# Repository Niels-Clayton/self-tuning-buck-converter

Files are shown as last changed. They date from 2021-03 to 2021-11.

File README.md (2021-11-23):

# [Self Tuning Buck Converter](https://niels-clayton.github.io/self-tuning-buck-converter/)

### Documents

Documentation and project planing

### Literature

Latex bibliography `.bib` file, organised using [JabRef](http://www.jabref.org), with copies of all cited documents.

### Reports

Latex projects for all written reports.

- Project Proposal
- Preliminary Report
- Final Project Report

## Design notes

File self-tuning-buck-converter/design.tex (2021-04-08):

\documentclass[a4paper,11pt]{article}
\usepackage[left=2.5cm, right=2.5cm, top=1.5cm, bottom=1.5cm]{geometry}
\usepackage{graphicx}
\usepackage{amssymb}
\usepackage{amsmath}
\usepackage{xcolor}
\usepackage{hyperref}

\hypersetup{ %color attributes of citation, link, etc.
    colorlinks=true,
    linkcolor=blue,
    filecolor=gray,
    urlcolor=blue,
    citecolor=blue,
}

\setlength{\parindent}{0pt}

%'codify' text for snippets
\usepackage{xcolor}
\definecolor{codegray}{gray}{1}
\newcommand{\code}[1]{\colorbox{codegray}{\texttt{#1}}}

\graphicspath{ {./images/} }
  
\title{\LARGE{\textbf{Self Tuning Buck Converter Design}}}
\author{}
\date{}

\begin{document}

\maketitle
\vspace{-20pt}
\hrule

\section{PWM Generation}

Based on our evaluation criteria, the generated PWM signal will need to be capable of outputting frequencies between 1kHz and 100kHz. \\

This PWM signal will also need to facilitate the required output voltage accuracy of $\pm5\%$ of the target output voltage, for target voltages between 3V and 10V. The relationship between the input and output voltage of a buck converter is given by $V_{out} = D \times V_{in}$. It should be noted that the output voltage is a function of the PWM duty cycle, therefore we must design the duty cycle such that it can provide the required output voltage accuracy. The workings of this design can be seen in the following.\\

Assuming $V_{min} = 3V$ 
\begin{align*}
    V_{error} &= 5\% \mathrm{\; of \;} V_{min} = 0.15V\\
    D_{steps} &\ge \frac{V_{in}}{V_{error}} \ge 80
\end{align*}

By designing the PWM duty cycle based on the buck converter minimum output voltage, we design the system to achieve the smallest tolerable error. This design guarantees that the required output voltage accuracy will always be achievable by our system if our PWM duty cycle has more than 80 steps. 

\subsection{Analogue}

\subsection{Microcontroller}

\subsection{FPGA}

\section{Current Ripple Sensing}

\end{document}

% \begin{center}
%     \fbox{\includegraphics[width=0.9\textwidth]{image_name.png}}
% \end{center}

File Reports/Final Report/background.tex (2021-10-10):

\chapter{Background}\label{C:background}

A literature research was performed to inform design decision made in this project, and to evaluate any existing research. This chapter will discuss buck converter design factors and topologies, as well as the various different methods of PWM generation, current sensing, and control implementation. In performing this literature research, we searched Google Scholar, Engineering Village, and Te Waharoa to find designs that utilised variable frequency PWM. 

These searches returned no research relevant to the designs of this project, with the only related work focusing on the electromagnetic noise reduction using randomised frequency modulation \cite{Roman2001,Familiant2016}. Because of this, research was instead performed to inform the design of the buck converter and the generation of PWM signals.

\section{Pulse Width Modulated Signal Generation}\label{S:PWM_back}

Pulse width modulation (PWM) is a digital signal generation technique shown in \Cref{F:PWM}, in which the Period $T$ of the signal is held constant, while the ratio of its logic high period $T_{on}$ to logic low period $T_{off}$ is modulated. This ratio of high period to the low period is referred to as the duty cycle of the PWM signal and is often expressed as a percentage, this can be seen in \Cref{F:Duty}.\\

PWM signals are used in a wide variety of applications for both digital and analogue electronics. PWM is often used to generate analogue signals from digital components by varying the average voltage of the digital PWM signal over time \cite{Thoren}. PWM is also used to control the switching elements contained within switch mode power supplies using this same principle, as discussed in \Cref{S:buck_back}. With regard to this project, we will be looking to generate a PWM signal that can be modulated in both duty cycle and frequency.

\begin{figure}[H]
      \centering
      \begin{subfigure}{0.45\textwidth}
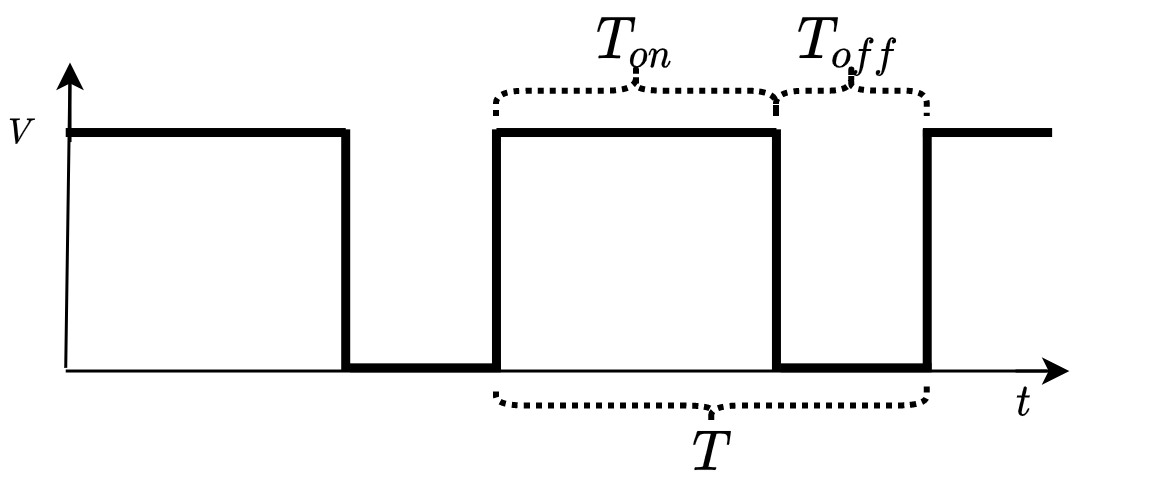
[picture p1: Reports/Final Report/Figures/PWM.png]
          
          \subcaption{Pulse width modulated signal}
          \label{F:PWM}
      \end{subfigure}
      \hspace{10pt}
      \begin{subfigure}{0.5\textwidth}
          
          \vspace{-6pt}
          \subcaption{Duty cycle calculation}
          \label{F:Duty}
      \end{subfigure}
      \caption{Pulse width modulated signal characteristics}
      \label{F:PWM_description}
  \end{figure}

\subsection{Analogue PWM Signal Generation} \label{S:analogue_PWM_back}

Designing a PWM signal generator using analogue components has three distinct stages required to generate the signal. These stages can be seen in \Cref{F:analogue_PWM}, and include clock generation, triangle wave generation, and signal comparator stages \cite{Caldwell2013}.\\ 

The clock generation stage generates a square wave clock signal at a set frequency. This is usually done using a quartz crystal oscillator, or another form of resonating oscillator circuit. The triangle wave generating state must take the clock signal from the previous stage, and produce a triangle wave of the same frequency. This stage is most often done using a standard op-amp integrating circuit with unity gain at the resonating frequency of the clock source. The final signal comparator stage will convert this triangle wave into a PWM signal. Using a comparator, a reference voltage can be applied to the non-inverting input, and then the triangle wave can be applied to the inverting input. This will produce a pulse train with the same frequency as the clock source, where the period of $T_{on}$ and $T_{off}$ is set by the reference voltage. 

\begin{figure}[H]
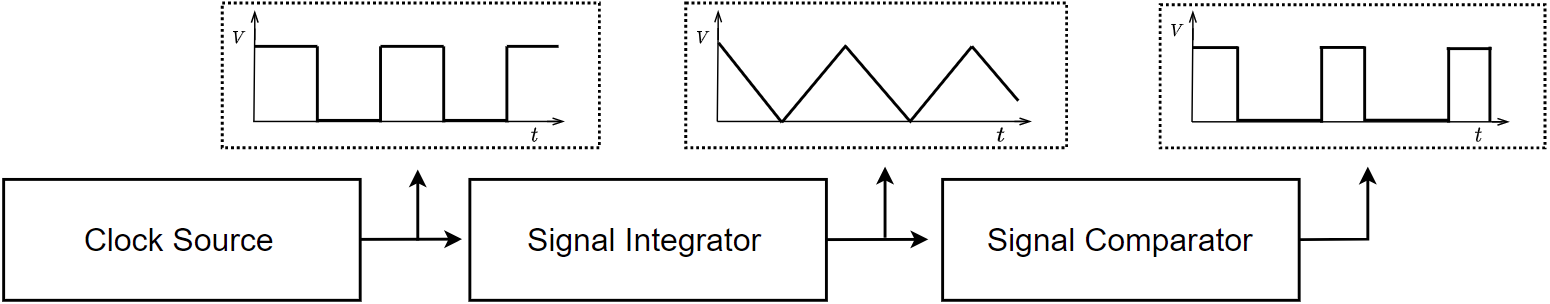
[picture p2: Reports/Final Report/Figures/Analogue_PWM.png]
	
	\caption{Stages of analogue PWM generation}
	\label{F:analogue_PWM}
\end{figure}

\subsection{Digital PWM Signal Generation}\label{S:digital_PWM_back}

Designing a PWM signal generator with digital components is less complex than the method described in \Cref{S:analogue_PWM_back}, and can be done using either a microcontroller or a Field Programmable Gate Array (FPGA). By using an internal timing register that is continually incrementing at a known period we can set a period for our PWM. It is possible to vary the period of the PWM by simply increasing or decreasing the timing registers clock. Next, by toggling a digital I/O when a compare variable is equal to the current value of the timer, we are able to generate a PWM signal with a variable duty cycle \cite{Colley2020}. 
This timing architecture can be simply implemented within an FPGA, but it can also commonly be found within the hardware of most microcontrollers. However, It should be noted that the range of achievable frequencies and duty cycle accuracy will be dependant on an individual microcontrollers clock speed and internal register sizes.

\section{Buck Converters}\label{S:buck_back}

The buck converters is a variant of a switch mode power supply that steps down a DC input voltage to a DC output voltage. They are commonly used in a wide variety of consumer and professional appliances such as laptops, phones, and chargers due to their high efficiency compared to other DC-to-DC step down converters such as linear regulators \cite{Mohan2012}.\\

The basic operational components of a buck converter can be seen below in \Cref{F:buck_func}. From this we see that a buck converter has three main elements, the input voltage source, two switching components, and an output filter across the load. In the case of \Cref{F:buck_func}, the first switching component is an actively controlled switch such as a MOSFET or transistor, and the second a passive switching diode. This configuration of an active and a passive switch is known as the non-synchronous buck converter topology, if the passive diode were to be replaced with a second active switch the topology would be considered synchronous. Although both topologies function under the same fundamental principles, the non-synchronous topology is easier to implement with the drawback of higher losses and therefore lower efficiency.\\

It can also be seen from \Cref{F:buck_func} that a buck converter has two operating states that are controlled through the activation of these switching components. By toggling these switching components at high speed though the use of PWM, we can control the current flowing through the inductor of the output filter. By controlling this current we are also able to directly control the current through, and voltage across the output load of the converter. Using this, buck converters will often have a feedback control system in their design to be able to actively control and regulate the output voltage during usage. This controller will vary the duty cycle of the the switching PWM signal, thereby varying the output voltage of the buck converter as shown in \Cref{E:V_out}.\\

\begin{figure}[H]
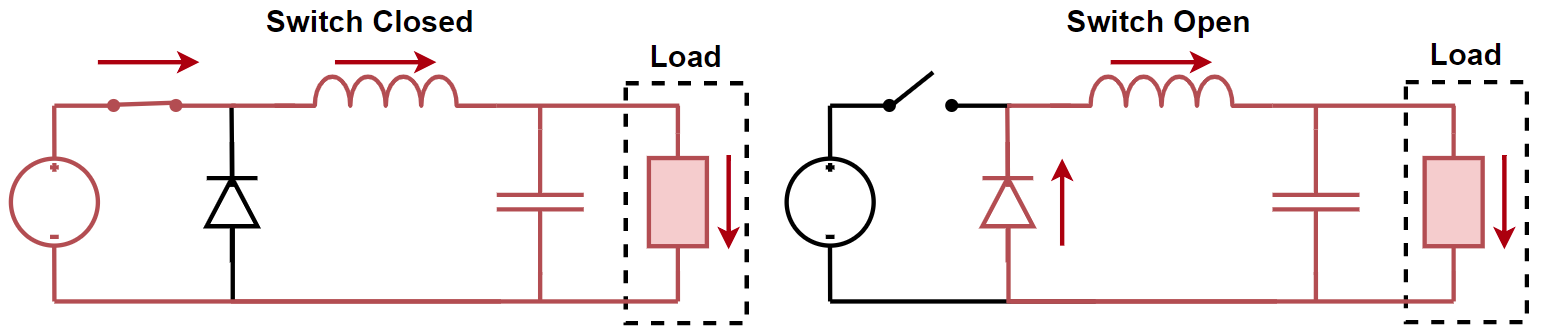
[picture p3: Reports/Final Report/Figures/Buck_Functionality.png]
	
	\caption{Operating states of a buck converter}
	\label{F:buck_func}
\end{figure}

\subsection{Buck Converter Design}\label{S:buck_design_back}

The design of a common buck converter has two primary considerations, the output voltage of the converter $V_0$, and the inductor current ripple of the converter $\Delta i_L$. These considerations can be specified by designing the buck converter using \Cref{E:V_out} \& \Cref{E:delta_i} \cite{Mohan2012_Design,Hauke2015}.\\ 

When designing a buck converter the first design specification that must be met is the output voltage. In \Cref{E:V_out} the output voltage can be directly related to the input voltage $V_{in}$ and the switching duty cycle $D$. Using this equation it is possible to directly set the output voltage of the buck converter by varying this duty cycle.

\begin{align}\label{E:V_out}
	V_o &= D \cdot V_{in}
\end{align}

Once the output voltage has been specified, the inductor current ripple can be calculated and specified with \Cref{E:delta_i}. This equation allows for the inductor current ripple to be directly related to the inductor size $L$, and the PWM switching frequency $f_s$. This allows the the specification of the inductor current ripple through the varying of these two values.

\begin{align}\label{E:delta_i}
   \Delta i_L &= \frac{ V_{o} \cdot \left( 1 - D \right) } {L \cdot f_s}
\end{align}

These two equations will be used to inform the designs and specifications of this project, and will be discussed in detail in \Cref{S:specs_design}.

\section{Current Sensing}\label{S:current_sense_back}

Current sensors are transducers that converter an input current to an easily measured output voltage that is proportional to the current through the sensor. Current sensors operate on one of two principles, Ohm's law, Faraday’s and Ampere’s law \cite{current_sensor_types}.  Ohm's law describes how when current flows through a resistive element a voltage drop will occur. Sensors operating under this principle will measure the voltage drop across a known resistance, and are referred too as direct sensors as they directly effect the circuit. Faraday’s and Ampere’s law describes how a changing electric flux will induce a changing magnetic field, and a changing magnetic field will induce a changing magnetic flux. Sensors operating under this principle will use the magnetic field induced by the current through the sensor to produce a voltage proportional to that current, and are referred to as indirect sensors as they make no direct contact with the circuit being sensed. 

\subsection{Current Sense Amplification}\label{S:current_shunt_back}

Current sense voltage amplification sensors are a form of direct sensor, working on the principle of Ohm's law $I=\frac{V}{R}$. By sensing the voltage dropped across a known value resistive element (Often called the current shunt), it is possible to calculate the current that is flowing through the element. This form of current sensing is easy to implement in theory, however it has the effect of altering the system being sensed by adding a resistive load, and thereby increasing the losses of the system. 

To mitigate the effects of this sensing on a circuit, a smaller resistive load can be used. However, this will also decrease the measurable voltage across the load, and therefore decrease the precision of a taken measurement. Because of this, shunt based current sensors are often paired with an operational amplifier of known gain. This combination allows for accurate amplification of the shunts voltage drop, increasing the precision of measurements, and allowing for drastically smaller shunt resistors. 

\subsection{Hall Effect Sensors}\label{S:hall_effect_back}

Hall effect sensors are a form of indirect sensor, working on the principles of Faraday’s and Ampere’s law as discussed above. They function by measuring the magnetic flux density, meaning that they are commonly used to sense the presence of a magnets or magnetic fields. However, since a current flowing though a wire will produce a magnetic flux, they can also be used to measure current flow.

Due to this operation, they are able to sense a current without contacting or altering the circuit. This means that they are commonly used in the measurement of high voltage or high current circuits, as they will remain completely isolated from the circuit being sensed. This provides large safety advantages, eliminates sensing power losses, and can often decrease the complexity of the sensing circuit. 

However, hall affect sensors do suffer from a lack of precision. Due to their operation, their measurements will constantly be offset by any ambient magnetic flux within the surrounding environment. This means that they are not commonly used for the sensing of small signal currents, as the noise floor of the Earth's own magnetic field can often be larger than the signal being sensed \cite{hall_effect_precision}. 

\newpage

\section{Control Systems}\label{S:control_back}

Control systems are integral to the operation of any system for which you wish to achieve a desired outcome. In their simplest, a control systems has the purpose of obtaining a desired output from a system, with a desired performance, when a given input is provided. \\

There are two main topologies of control system, open loop and closed loop. An open loop control system requires no feedback of the output, and therefore no sensing. Because of this, open loop controllers are often fast to implement within a system because of this. However, it should be noted that they possess no knowledge of the systems state and are therefore unable to correct for errors such as external disturbances. 

On the other hand, closed loop controllers require feedback from the current output of a system, and therefore will require sensing to be implemented. This feedback provides the ability to compensate for errors in the systems output, with the drawback of add complexity.\\

The performance of a specific control system is often discussed in terms of it's steady state settling time, and it's stead state error. The steady state settling time of a controller describes the time it takes for a controller to reach it's final value (`steady state') when provided with a given input. The slower the steady settling time of a controller, the slower it will react to a given input, and vice versa. The steady state error of a controller describes the error between the desired output and the final output of the system once it's steady state has been achieved.

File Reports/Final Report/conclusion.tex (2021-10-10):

\chapter{Conclusions}\label{C:conclusion}

The ultimate goal of this project was to develop a testing platform through which the effects of variable buck converter switching frequency on inductor current ripple could be observed and controlled. This goal was to be approached with an emphasis on its usability and expandability, providing a proof of concept for further development and research to be performed.\\

With these goals in mind the project was subdivided into three subsystems, each responsible for the operation of a key component of the final systems design. Each subsystem was individually designed, implemented, and evaluated throughout this report.

The first of these subsystem is PWM signal generation, responsible for providing a selectable switching frequency and duty cycle switching signal. This section facilitates buck converter operation, providing the ability to both vary output voltage, and inductor ripple independently. 

The second subsystem involves system state sensing, responsible for measuring the current values of various portions of the design. This section facilitates the feedback on current converter states, monitoring the output voltage, the supply voltage, and the inductor current ripple. 

The final subsystem provides the control, responsible for maintaining the selected buck converter output voltage and inductor current ripple. This subsystems interacts directly with the previous two, receiving system feedback from subsection 2, and providing output frequencies and duty cycles to subsystem 1.\\

This project was also subject to a list of requirements, provided in \Cref{S:goals}, which was then broken down into final system specifications in \Cref{S:specs_design}. The following list briefly outlines each requirement and it's final implementation within this project.\\

\begin{enumerate}
    \item \textbf{Operate with a 12V DC input supply voltage}

    Each subsystem was successfully designed to operate with a DC input supply between 8V and 16V. 

    \item \textbf{Provide a selectable DC output voltage between 3V and 10V}

    The implemented system was capable maintaining a selected DC output voltage between 1V and 10V, selectable to one decimal pace. 

    \item \textbf{Provide an output voltage precision of at least $\pm5\%$ of the targeted output voltage}

    The implemented system was capable maintaining an output steady state error of $\pm$0.78\%, across the entire output voltage range.

    \newpage
    \item \textbf{Provide a selectable inductor current ripple between 20\% and 50\% of the total output current}

    This requirement is pending implementation due to Covid-19 relates delays. Evaluation has been performed on each element of the requirements design, all of which successfully met the individual specifications.

    \item \textbf{Provide a variable converter switching frequency between 1kHz and 100kHz}

    The implemented system was capable of varying switching frequency between 1kHz, and 100kHz, with a maximum frequency error of 0.064\% of the target output.

    \item \textbf{Provide an inductor current ripple precision of at least $\pm5$\% of the target inductor current ripple }

    This requirement is pending implementation due to Covid-19 relates delays. Evaluation has been performed on each element of the requirements design, all of which successfully met the individual specifications.

    \item \textbf{Operate with variable load sizes between 10$\Omega$ and 20 $\Omega$}

    Each subsystem has been successfully designed to operate with variable load sizes between 10$\Omega$ and 20 $\Omega$.

\end{enumerate}

\section{Future Work}

Upon full assembly of this projects subsystems into the final designed system, this project lends it self to a wide variety of future research and study. 

With the projects motivation being based on the complexity and static nature of buck converter design, research into the characterisation of varying buck converter topologies can be performed. This could allow for distinctions between the design process of synchronous and asynchronous buck converters, exploring possible differences in switching frequency requirements between the two topologies. 

It would also be valuable to explore this systems response to non-resistive loads, looking to characterise the different switching requirements for both inductive and capacitive impedances.

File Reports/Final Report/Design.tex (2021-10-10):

\chapter{Design}\label{C:design}

The design processes outlined within this report will draw heavily on the background research discussed in \Cref{C:background}. These designs aim to effectively implement the outlined system requirements discussed by \Cref{S:goals} in a robust and repeatable manner.

%
% SECTION Defining & Justifying System Specifications
%

\section{System Specifications and Architecture}\label{S:specs_design}

\Cref{S:goals} outlines a list of specifications that this project must achieve. For each item in this list, design specifications can be derived to ensure that our designs are capable of meeting the outlined requirements. This list of specifications will also help to shape the architectural approach taken on this project.

\subsubsection*{Requirement 1: Operate with a 12V DC input supply voltage}

To meet this requirement, the buck converter must be designed to be 12V DC compatible. this will require all designed hardware, including additional digital and analog circuity to be capable of operating with this supply.

\subsubsection*{Requirement 2: Provide a selectable DC output voltage between 3V and 10V}

To meet this requirement, the designed buck converter must have the ability to change the duty cycle of it's PWM switching signal. This will allow for variation of the output voltage based on \Cref{E:V_out}.

\subsubsection*{Requirement 3: Provide an output voltage precision of at least $\pm5\%$ of the targeted output voltage}

To meet this requirement, the designed buck converter must have a control system to regulate the output voltage. To achieve a steady state error of less than $\pm5\%$, feedback should be implemented, requiring output voltage sensing. We can also specify that a minimum duty cycle resolution of 1.25\% will be required to achieve this. For the derivation of these values, refer to \Cref{A:specs}.

\subsubsection*{Requirement 4: Provide a selectable inductor current ripple between 20\% and 50\% of the total output current}

To meet this requirement, the designed buck converter must have the ability to change the frequency of it's PWM switching signal. This will allow for variation of the inductor peak to peak current ripple based on equation \Cref*{E:delta_i}. 

\subsubsection*{Requirement 5: Provide a variable converter switching frequency between 1kHz and 100kHz}

To meet this requirement, the PWM switching frequency must be selectable across the specified range. This, in tandem with requirement 4, allow for the specification of the inductor range for which these requirements can be met. For the derivation of these values, refer to \Cref{A:specs}.

\subsubsection*{Requirement 6: Provide  an  inductor  current  ripple  precision  of  at  least $\pm$5\%  of  the  target  inductor current ripple}

To meet this requirement, the designed buck converter must have a control system to regulate the inductor current ripple. To achieve a steady state error of $\pm$5\%, feedback should be implemented, requiring inductor current ripple sensing. We can also specify that a minimum frequency selection resolution of 200Hz, as well as a minimum current ripple measurement resolution of a resolution of 15mA will be required to achieve this. For the derivation of these values, refer to \Cref{A:specs}.  

\subsubsection*{Requirement 7: Operate with variable load sizes between $10\Omega$ and $20\Omega$}

To meet this requirement, all components of the buck converter must be designed to handle the maximum output current of 1A that will occur with a $10\Omega$ load at 10V. It will also be important that any current sensing is designed to operate within the range defined by these loads. Finally it is required that control systems are implemented to maintain requirements 3, \& 6 as the load varies. 

\subsection{System Architecture}\label{S:system_architecture}

Based on the specifications outlined in the above section, an architecture that outlines the system design has been developed. This architecture has been divided into three subsystems that must each be developed. This architecture system can be seen in \Cref{F:sys_overview}.\\

Subsystem one implements a PWM generator. From requirements 2, \& 5 it has been identified that a PWM generator capable of varying both the duty cycle and the frequency of it's output signal independently must be designed. This system can be seen in \Cref{F:sys_overview} outlined in green.\\

Subsystem two implements system state sensing. From requirement 3 \& 6 it has been identified that an output voltage sensor, and an inductor current ripple sensor must be designed. This system can be seen in \Cref{F:sys_overview} outlined in blue.\\

Subsystem three implements two control systems. From requirements 3, 4, 6, \& 7 it has been identified that control systems should be designed to ensure that the specified steady state errors of the output voltage and inductor current ripple are met. 

One control system will take the output load voltage measurement, and control the PWM duty cycle. The other control system will take the inductor current ripple, and control the PWM frequency. This system can be seen in \Cref{F:sys_overview} outlined in red.

\newpage

\begin{figure}[!h]
    
    \caption{System architecture design, with three internal subsystems}
    \label{F:sys_overview}
\end{figure}

% It has been specified that the final system design will be able to select for both the output load voltage, and the inductor current ripple of the buck converter. From this requirement we can identity that two separate control systems should be designed, one to regulate the output voltage of the converter, and one to regulate the inductor current ripple.

% Next we can identify that to control the output load voltage and the inductor current ripple, we must be able to actively effect their current state. Based on \Cref{E:V_out} we can see that by varying the duty cycle of the converters PWM signal, we are able to directly control the output voltage. Similarly, from \Cref{E:delta_i} we can see that by varying the converters PWM switching frequency we are able to directly control the inductor current ripple. From this we can specify that our designs of the PWM generation must be capable of varying both the duty cycle and the switching frequency of the output PWM signal independently and simultaneously. \\

% The outlined requirements also specify the level of precision that will be required from the output load voltage and the inductor current ripple. This allows us to specify the tolerable error for the system design, and calculate the minimum required system specifications. Based on the buck converter design equations from \Cref{S:buck_design_back}, The following specifications have been identified:

% \begin{itemize}
%     \item Maximum allowable duty cycle step size

%     \begin{align}
%         V_{error} &= V_{min} \cdot error = 0.15V\\
%         D_{step} &= \frac{V_{error}}{V_{in}} = 0.0125\\
%         N_{step} &= \frac{1}{D_{step}} = 80 \label{E:duty_step}
%     \end{align}

%     \item Maximum \& minimum inductor sizes

%     \begin{align}
%         L_{max}&=\frac{V_{max}\cdot\left(1-D_{max}\right)}{f_{min}\cdot I_{min}} = 27.7mH \label{E:L_max}\\ 
%         L_{min}&=\frac{\frac{V_{in}}{2}\cdot\left(1-0.5\right)}{f_{max}\cdot I_{min}} = 0.5mH \label{E:L_min}
%     \end{align}
    
%     \item Maximum allowable frequency step size

%     \begin{align}
%         f_{step}&=\frac{V_{max}\cdot\left(1-D_{max}\right)}{\left(I_{min}-I_{Error}\right)\cdot L_{max}}-f_{min} = 52Hz\\
%         N_{steps}&=\frac{\left(f_{max}-f_{min}\right)}{f_{step}} = 1881 \label{E:f_step}
%     \end{align}

% \end{itemize}

% The derivation of these values can be found in \Cref*{A:specs}.

% \subsubsection{TODO Refactor this to be a list of specifications}
% From these equations we can build a list of final specifications to inform the design of our PWM generator and buck converter. The PWM generator must provide a minimum voltage step size of $0.0125$V, for a resolution of 80 voltage steps between 3V and 10V. The PWM generator must also be able to provide a minimum frequency step size of $52$Hz, for a resolution of 1881 frequency steps between $1$kHz \& $100$kHz. Finally we can also specify that the buck converter must be capable of functioning with inductor values between $0.5$mH \& $27.7$mH. \\

% By designing the PWM generator and the buck converter to these specifications, we are able to guarantee that we can always achieve the requirements outlined in \Cref{C:intro}.\\

% \subsubsection{TODO Discuss the minimum and maximum sense current, along with the bandwidth requirement of the sensors}
% Design the system specifications around the current sensing and voltage sensing. What is the required bandwidth of the sensor? What is the required precision?\\

% \section{System Architecture \& Design}\label{S:system_design}

% To achieve the specifications that have been outlined in \Cref{S:specs_design}, it is important to design the system architecture around them. In \Cref{F:sys_overview} an overview of the system architecture can be seen, with three main design sections outlined. These sections each represent a significant segment of work that must be completed for the final artefact of this project to be achieved. \\

% The first section of work that must be completed is the design of the PWM generation, denoted 1 in \Cref{F:sys_overview}. This PWM generator will be used to control both the output voltage and the inductor current ripple, and as such must be able to modulate both the duty cycle and the frequency of the PWM to the precisions required. \\

% The second section of work is the design of the sensing elements required by the system, denoted 2 in \Cref{F:sys_overview}. These elements will be used to measure both the output voltage and the inductor current ripple, and therefore must be able to achieve the required precisions and sampling rates. \\

% Finally the third section of work is the design and implementation of the two control systems, denoted 3 in \Cref{F:sys_overview}. These control systems will be responsible for maintaining the desired output voltage and inductor current ripple of the buck converter. This system will therefore be responsible for facilitating the final functionality of the project, combining sections 1 \& 2. \\

%
% SECTION PWM Generation
%

\section{PWM Signal Generator}\label{S:pwm_gen_design}

In the design of the PWM generator, both the analogue and digital topologies discussed in \Cref{S:PWM_back} were considered, and designed for. Each of these designs presented pros and cons that would affect the overall design. This section will discuss these design choices, and finalise the design of the PWM signal generator.

A successful design will meet all of the requirements outlined by \Cref{S:specs_design}. Therefore the design must be capable of duty cycle variation with a resolution of 1.25\%, as specified by requirements 2 \& 3, as well as switching frequency variation between 1kHz \& 100kHz with a resolution of 200Hz, as specified by requirements 4, 5, \& 6. A successful design will also adhere to the ease of use and future expansion goal specified in \Cref{S:goals}.

\subsection{Analogue PWM Generator Design}\label{S:PWM_analogue_design}

It has been discussed in \Cref{S:analogue_PWM_back} that the design of an analogue PWM signal generator requires three distinct stages. These stages are signal clock generation, signal integration, and signal comparison, as shown in \Cref{F:analogue_PWM}.

Designs for these sections were implemented within the circuit simulation software LTSpice, see \Cref{A:PWM}. From these simulations it was identified that the signal integration stage of the design functions as a first order low pass filter, where integration occurs beyond the filter's cut-off frequency. This causes a 40dB attenuation of the output signal across the required frequency range. Due to this, the design was identified to be unsuitable for this system as it was unable to meet requirements 4, 5, \& 6. 

% The clock generation stage will be responsible for setting the frequency of the final PWM signal. This specifies that the clock source have a variable frequency output range between $1kHz$ and $100kHz$, with a minimum step size of $52Hz$. Research was done on a variety of clock sources, looking at voltage-controlled oscillators (VCO's), signal generator IC's, and even the basic 555 timer. From this VCO's were identified to operate at much higher frequencies than those used in this project. It was also identified that signal generator IC's often require selections of passive components to operate effectively, increasing their complexity. For this reason the variable frequency 555 timer circuit was selected, as it provided the required specifications.\\

% The next section designed was the signal integrator stage. This stage consisted of a basic op-amp integrator circuit, with a design requirement that it be able to integrate the clock signal across the frequency range required. This circuit was designed and implemented in an LTSpice simulation to evaluate it's performance, and can be seen in \Cref*{A:analogue_PWM}. From this simulation it was noted that the integrator's frequency response was similar to that of a first order low pass filter, and greatly attenuated the integrated signal. For this reason it was decided that analogue PWM generation would not be implemented in this system, as it presented many issues.

\subsection{Digital PWM Generator Design}\label{S:PWM_digital_design}

As discussed in \Cref{S:digital_PWM_back}, The design of a digital PWM signal generator is based on the toggling an output when a timer reaches a given comparison value. This design can be achieved with either discrete logic designed within an FPGA, or using existing hardware within a microcontroller. 

\subsubsection*{FPGA PWM Generator}

The operation of an FPGA allows for the design and implementation of customised logic. Because of this, designs utilising FPGA's would easily be able to meet the specified requirements for the PWM signal generator.

However, the designs integration into the system architecture described in \Cref{F:sys_overview} must also be considered. A PWM generator implemented in an FPGA will be required to either implement or provide an interface with the control subsystem, as well as the state sensing subsystem. These interfaces must also be designed, greatly increasing the complexity of this specific subsystem. Due to this added complexity, it was identified that this design was not suitable for an initial proof of concept, and would not adhere to the ease of use goal. 

\subsubsection*{Microcontroller PWM Generator}

The selection of the microcontroller is highly dependant on the clock frequency and internal PWM peripheral architecture. Since these vary greatly between different processors, a selection of microcontroller data-sheets were reviewed to identify their specifications. 

The microcontrollers reviewed were selected based on the ease of use of their available development environments. This included AVR, STM8, Espressif, and teensy based microcontroller development boards. 

From this review it was identified that the ESP32 microcontroller \cite{ESP32Manual} would be best suited to this project. This microcontroller is capable of outputting a maximum PWM frequency of 125$kHz$ when a duty cycle resolution of 9 bits is selected. This will provide a total of 512 selectable duty cycle values, for a resolution of 0.2\%, while providing a selectable duty cycle frequency between 1Hz, \& 125kHz. 

Based on these specifications, it is clear that this design meets the duty cycle requirements of 2 \& 3, as well as the frequency requirements of 4, 5, \& 6, and is therefore suitable.

%
% SECTION Inductor Current Ripple Sensing Design
%

\section{System State Sensing}\label{S:sensing_design}

The design of the state sensing system will include the output voltage sensor and the inductor current ripple sensor. These sensors will be responsible for providing the feedback data for the control systems, illustrated in \Cref{F:sys_overview}. To provide a peak to peak inductor current measurement as a percentage of the output current, both the average and peak inductor currents must be measured. Based on these measurements, the inductor current ripple percentage can be calculated.

A successful design will meet all the requirements outlined by \Cref{S:specs_design}. Therefore the output voltage sensor must be capable of measuring voltages between 3V \& 10V with a resolution of 150mV, as specified by requirements 2 \& 3. It is also required that the average inductor current, and the peak inductor current ripple measurements achieve a resolution of 15mA, for frequencies between 1kHz \& 100kHz, as specified by requirement 4, 5, 6, \& 7.

\subsection{Output Voltage Sensing}\label{S:v_sense_design}

The output voltage of the buck converter will be a DC voltage between 3V \& 10V. As there are no high frequency components to this signal, there are no bandwidth requirements on it's sampling. Due to this the internal analog to digital converter (ADC) of the ESP32 microcontroller will be used for sampling. This 12 bit ADC can measure an input voltage range of 0V to 3V \cite{ESP32Manual}, therefore the output voltage will have to be measured through a voltage divider. This divider will provide an output ratio of $\frac{10}{3.33}$, allowing for maximal use of the ADC's input range. This will provide a theoretical measurement resolution of 2.5mV. 

Based on these specifications, this design is capable of measuring output voltages between 3V and 10V, with a resolution of 2.5mV, meeting the outlines requirements 2 \& 3.

\subsection{Current Sensor Selection}\label{S:current_sense_selection}

To maintain design simplicity, both the average inductor current, and the peak inductor current ripple will be measured from the same sensor. Due to this, a hall effect based current sensor is not suitable for this application. It was discussed in \Cref{S:hall_effect_back} that they lack precision due to a high noise floor, and would be unable to meet requirements 4 \& 6. 

Because of this, a current shunt based sensor with a defined gain and selectable shunt resistance has been designed, specifically the LT1999-50 with a 60m$\Omega$ shunt. This current sense amplifier has a specified gain of 50V/V, a typical gain error of 0.2\%, and a bandwidth of 2MHz \cite{LT1999_datasheet}. This sensing solution will provide a voltage output between 0.67V \& 3.72V across the total current sensing range, with a resolution defined by the gain error of 50$\mu$A at the output. Refer \Cref{A:specs} for the calculation of these values. The datasheet also specifies that there will be no attenuation of the output gain for frequencies of 100kHz or below. 

Based on these specifications, this design is capable of measuring the full current input range specified in requirements 4 \& 7, while surpassing the resolution and frequency specifications of requirements 5, \& 6.

\subsection{Average Inductor Current Sensing}\label{S:avg_current_design}

\begin{wrapfigure}{r}{0.3\textwidth}
    \vspace{-33pt}
    \begin{center}
      
    \end{center}
    \caption{Average current 10Hz cut-off low pass filter}
    \vspace{-22pt}
\end{wrapfigure}

To obtain the average inductor current ripple, the output of the previously designed current sense amplifier can be low pass filtered. By designing a first order passive low pass filter with a cut-off frequency of 10Hz, we can be sure to attenuate any selectable switching frequency by at least 40dB. This will provide a simple to measure DC voltage between 0.45V and 3V. This can be measured using the internal ADC of the ESP32 providing a theoretical resolution of 700$\mu$V, or 244$\mu$A. Refer \Cref{A:specs} for the calculation of these values.

\subsection{Peak Inductor Current Sensing}\label{S:peak_current_design}

Based on the bandwidth requirement of 1kHz to 100kHz, it was identified that sampling the output signal of the current sensors to identify the peaks would be impractical. To achieve this a sampling rate of at least twice the highest frequency component would be specified by the Nyquist theorem, and a recommended minimum of one decade above is considered common practice, requiring a sampling rate of 1Mhz. 

Due to this, designs were undertaken to simplify the sampling requirements. The following designs will take direct input from the current sensor, and aim to output a DC voltage that is representative of the input current peak values. 

% discuss why it is that peak sensing is important, and how two designs have been created to achieve this task. The precision rectifier is my own design and not based on any existing designs, the sample and hold based sensor is based on designs from these resources \cite{peak_detector_designs, LTC6244_peak_detector}

\subsubsection*{Precision Rectifier Peak Voltage Detection}\label{S:current_sense_precision_rectifier_design}

This design is based around the operation of a signal precision rectifier, and the knowledge that the inductor current ripple will be symmetrical and triangular in shape \cite{Mohan2012_Design}. Due to this symmetry, we know that the average inductor ripple current over a period will be zero, shown in \Cref*{F:rectification} (a). After rectification of the signal, the the ripple peak to peak value will halve, the frequency will double, and the new signal average will be half the new ripple peak to peak, shown in \Cref*{F:rectification} (b). 

\begin{figure}[H]
    
    \centering
    \begin{subfigure}{0.49\textwidth}
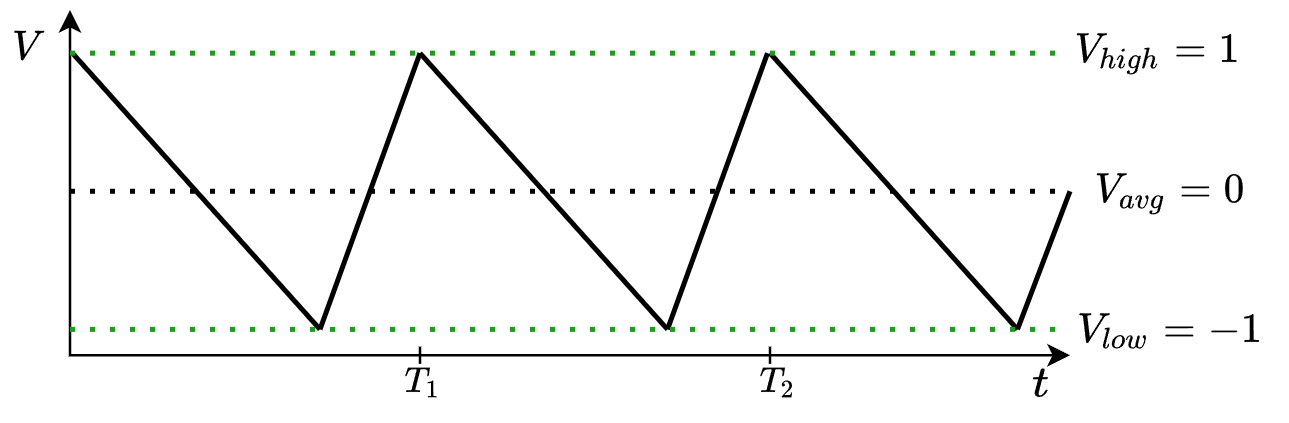
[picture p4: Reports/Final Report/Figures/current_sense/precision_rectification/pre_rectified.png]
        
        \subcaption{Pre-rectification current sense output of 1V pk to pk, average voltage of 0V}
    \end{subfigure}
    \begin{subfigure}{0.49\textwidth}
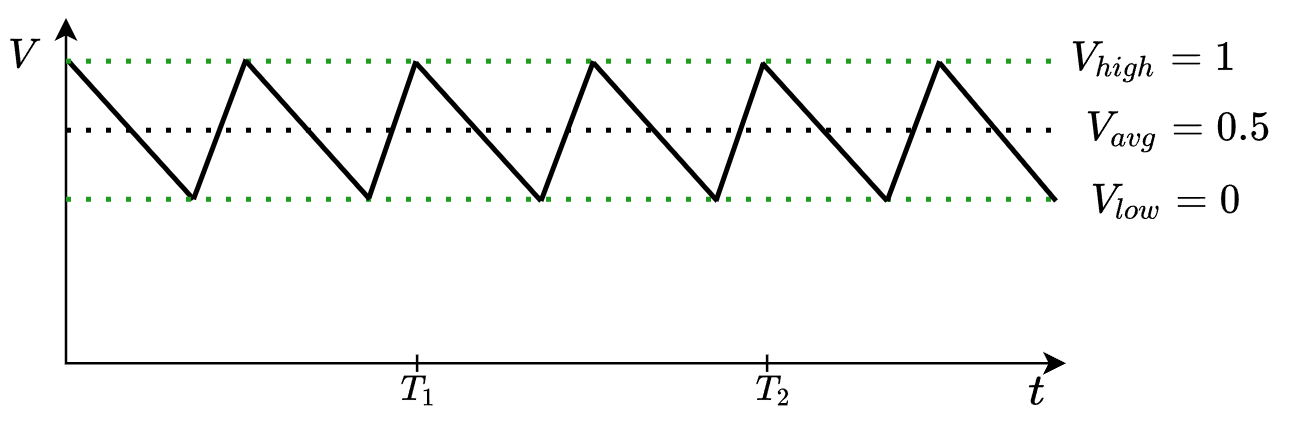
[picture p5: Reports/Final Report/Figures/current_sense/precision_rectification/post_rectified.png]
        
        \subcaption{Post-rectification current sense output of 1V pk to pk, average voltage of 0.5V}
    \end{subfigure}
    \caption{Average voltage output of a symmetrical signal, before and after rectification}
    \label{F:rectification}
\end{figure}

From here, we can obtain the signal average by applying a passive a low pass filter with a cut off of 10Hz to the output, producing a sampleable DC voltage. To obtain the full original signal peak to peak value, this signal can then amplified with a gain of 4. The full design can be seen in \Cref{F:precision_rectifier_circuit}.

\begin{figure}[!h]
    \centering
    
    \caption{Precision rectifier peak detector designed circuit schematic}
    \label{F:precision_rectifier_circuit}
\end{figure}

% Discuss the operation, and simulations of the Precision Rectifier Peak Voltage Detection. 

\subsubsection*{Sample and Hold Peak Voltage Detection}\label{S:current_sense_sample_and_hold_design}

This design is based on existing voltage peak detection designs \cite{peak_detector_designs,LTC6244_peak_detector}. The design operates on a similar principle to a sample and hold unit, charging a signal capturing capacitor through a diode such that it will not discharge. In order to remove the voltage drop across the charging diode, it is placed within the forward path of an operational amplifier buffer. The output voltage is then buffered again to allow for sampling. The full design can be seen in \Cref{F:sample_and_hold_circuit}.

\begin{figure}[!h]
    \centering
    
    \caption{Sample \& hold peak detector designed circuit schematic}
    \label{F:sample_and_hold_circuit}
\end{figure}

Both of the discussed designs have been simulated in LTSpice, and have had their operation confirmed, refer to \Cref{A:peak_detector} for output plots. From this it was identified that both designs would be able to meet the resolution specification of 15mA, and bandwidth specification of 1kHz to 100kHz outlined in requirement 4, 5, 6, \& 7.

It should also be noted however that the design of the precision rectifier based peak detector is much more complex than that of the sample and hold peak detector. Because of this, it was decided that the sample and hold based peak detector would be most suitable for this project, as it meets all required specifications, and best adheres to the ease of use goal.

% Discuss the operation, and simulations of the Sample and Hold Peak Voltage Detection. Then discuss that due to it's simpler design, it's implementation will be far easier, the possible issue it may have will be easier to diagnose, and it's cost will be much lower. then specify that this was the final design selected for this section.

\subsection*{Current sensing digitisation}\label{S:current_sense_ADC_design}

Due to the operation of the design discussed in \Cref{S:current_sense_sample_and_hold_design}, the output DC voltage will be imposed on a DC refrence voltage. To eliminate this DC bias from the output, a dedicated external ADC with a differential input can be employed. This will allow for the removal of the bias at the digitisation of the signal. The selected ADC is the MAX11644, which provides a 12bit resolution, an internal reference of 4.096V, and the required differential input. 
Based on these specifications, this design is capable of measuring input voltages between 0V and 4.096V, with a resolution of 8mV. This will give a current sensing resolution of 2.6mA, meeting the specifications of requirement 6.

% Discuss the selection of the ADC for measuring the peak ripple and mean ripple currents. Talk about the minimum required ADC precision, and bandwidth requirements. Discuss hoe this AC provides a differential output. 

%
% SECTION Control System Design
%

\section{Control System}\label{S:control_design}

When designing the output voltage and inductor current ripple control systems, a successful design will meet all the requirements outlined by \Cref{S:specs_design}. From this we can identify that both controllers must provide a steady state error that is less $\pm$5\% of the targeted value, as specified in requirements 3 \& 6. 

\subsection{Output Load Voltage Controller}\label{S:output_control_design}

To achieve the desired output voltage steady state error, a feedback controller with an integrating term should be used. To provide this, the design will implement a proportional, integral, \& differential (PID) controller. This controller will be provided with the buck converter output voltage as an input, this will then be converted to the theoretical PWM duty cycle required to produce that output based on \Cref{E:V_out}. This will then be used to calculate the controller error and output the new PWM duty cycle.

To design this, a mathematical model of a buck converter \cite{Patil2015} was found and simulated in Matlab. This model was then discretised such that it could be implemented on a microcontroller, and a PID controller was then designed with the `\lstinline{PIDTune()}' function. A step response simulation of this model can be found in \Cref{A:control}. 

Due to the control topology used in this design, this design will be able to provide an output voltage steady state error of 23mV based on the discrete voltage step size from the PWM generator. This will provide a worst case error of $\pm$0.78\%, meeting the $\pm$5\% specified in requirement 3.

\newpage
\subsection{Inductor Current Ripple Controller}\label{S:ripple_control_design}

To achieve the desired inductor current ripple steady state error, the same topology implemented for the output voltage controller will be implemented. This PID controller will take the system's inductor current ripple as a percentage of the average current, and then calculate the error between it and the target value. From here it will then output the new PWM switching frequency. 

Due to the control topology used in this design, this design will be able to provide an inductor current ripple steady state error of less than $\pm$5\%, as specified in requirement 6.

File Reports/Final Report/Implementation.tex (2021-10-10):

\chapter{Implementation}\label{C:implementation}

\section{PWM Signal Generation}\label{S:pwm_gen_impl}

The PWM signal generator subsystem was designed around the Espressif ESP32 microcontroller. For ease of development around this microcontroller, a pre-built breadboard compatible development board was purchased for the implementation. \\

Using this development board, a PWM hardware driver was developed to facilitate the implementation of this subsystems core functionality as specified in \Cref{S:specs_design}. This driver implements three core functions, `\lstinline{PWM_setup()}' to initialise the PWM hardware, `\lstinline{PWM_set_duty()}' to select a new duty cycle, and `\lstinline{PWM_set_frequency}' to select a new frequency. The full driver implementation, refer to \Cref{A:pwm_code}.\\

After the software implementation had been completed, it was identified that the 3.3V digital output of the microcontroller would be incapable of driving the buck converters switching power MOSFET. To resolve this, the IR2125 high side N-channel gate driver IC was purchased to drive the MOSFET from the PWM generators output signal. This final circuit was then implemented and it's functionality was tested on a breadboard. Please see \Cref{A:pcb_and_schematic} for the designed schematic, and \Cref{A:breadboard} for the implemented breadboard circuit.

% Discuss how the micro will be unable to directly drive the gate of the switching MOSFET, as it's $V_{GS_{on}}$ will be too large. Because of this a gate driver will need to be selected. The driver will need to be driven using the 3.3V logic from the ESP32, and will need timings fast enough to function correctly at 100kHz. I can also discuss how during the lock-down I was unable to purchase a gate driver, and so I built a bootstrapping circuit from components I located around the house. 

\section{System State Sensing}\label{S:current_sense_impl}

% Due to time restraints caused by COVID-19 related delays, the implementation and evaluation of each design within the state sensing subsystem discussed in \Cref{S:sensing_design} was impractical. Therefore, designs that \todo{lacked prior formal testing and evaluation in the form of datasheets} were prioritised for implementation. 

\subsection{Output Voltage Sensing}\label{S:v_sense_impl}

The output voltage sensing design discussed in \Cref{S:v_sense_design} was implemented on a prototyping breadboard. Refer to \Cref{A:pcb_and_schematic} for the designed schematic, and \Cref{A:breadboard} for the implemented breadboard circuit.

Using the ESP32 development board, an ADC hardware driver was developed to facilitate the measurement of the sensor output. This driver implements the core functionality of the ADC though two functions, `\lstinline{init_adc()}' to assign the input IO and measurement resolution, and `\lstinline{read_adc()}' to take an ADC measurement. Using these two functions this driver then also facilitates the computation of a rolling average with the `\lstinline{rolling_average()}' function, and voltage conversion with the `\lstinline{adc_conversion()}' function. The full driver implementation can be found in \Cref{A:adc_code}.\\

When initially implementing the ADC conversion function, it was assumed that that the output conversion of the ADC was linear. Once this had been implemented, it was observed that there were large inaccuracies in the voltage conversion. 

From this it was identified that the internal ADC  was non-linear, and would require calibration before meeting the required specifications. To achieve this, ADC measurements were taken for a selection of known input voltages ranging from 100mV to 3V in 500mV steps. These ADC measurements were then plotted against their respective input voltages using Matlab, and a forth order polynomial was fit to the data, shown in \Cref{F:adc_calibration}. This polynomial was then used for the conversion of the raw ADC reading to a voltage, greatly improving the ADC's accuracy.

\begin{figure}[!h]
    \centering
    
    \caption{ESP32 internal ADC calibration data with forth order polynomial fit}
    \label{F:adc_calibration}
\end{figure}

\subsection{Inductor Current Sensing}

\subsubsection*{Average Inductor Current Sensing}

The average inductor current sensing design discussed in \Cref{S:avg_current_design} was implemented on a prototyping breadboard. Refer to \Cref{F:final_peak_detector} for the designed schematic, and \Cref{A:breadboard} for the implemented breadboard circuit.

This design also utilises the ESP32 internal ADC, which was previously implemented in \Cref{S:v_sense_impl}. Therefore no further implementation was required for the functionality of this design.  

\subsubsection*{Peak Inductor Current Sensing}\label{S:peak_current_implementation}

The peak inductor current sensing design discussed in \Cref{S:peak_current_design} was initially implemented on a prototyping breadboard, using an LT084CN operational amplifier (op amp) provided by the lab technicians. 

On implementation it was observed that the functional principles of the design held true, as the design maintained a DC output voltage that was dependant in the input peak to peak ripple. However, it was observed that the accuracy of the design was much lower than expected when compared to the design simulations. The operation of this original design \todo{can be seen in} \Cref{A:peak_detector}.\\

It was identified that the limiting factor within the design was the bandwidth and slew-rate of the input stage op amp seen in \Cref{F:sample_and_hold_circuit}. This op amp is responsible for charging the sampling capacitor and negating the forward bias diode drop, and therefore it's bandwidth and slew-rate will dictate the bandwidth of the design.  

Based on this, the input op amp was replaced with the OPA2830, as it provided a greatly improved bandwidth of 230MHz and a slew rate of 500V/$\mu$s. The original design was also altered to place a potentiometer in series with the sampling capacitor, as well as adding a high impedance resistor in parallel with this capacitor. This allows for the final designs performance to be tuned through the potentiometer, and any overshoot to be quickly dissipated by the parallel discharge resistor. This final design of the schematic can be seen in \Cref{F:final_peak_detector}, and the implemented breadboard circuit can be found in \Cref{A:breadboard}.

\begin{figure}[!h]
    \centering
    
    \caption{Finalised peak detector schematic, with updated op amp selection and performance improvements}
    \label{F:final_peak_detector}
\end{figure}

\section{Control System}\label{S:control_impl}

The control system design discussed in \Cref{S:control_design} has been implemented in the form of a generic PID based control system library. This control system implementation provides a structure in which all of the controller variables and states are stored. This simplifies the initialisation of the controller, as the proportional, integral, derivative, and time period constants can all be specified at the structure initialisation. This implementation also allows for the creation and management of multiple controllers simultaneously, meeting requirements 2 \& 4. 

This control library also provides more advanced safety features for the system, including selectable minimum and maximum output limits, and selectable integrator windup limits.\\

This library implements two core functions which provide the full functionality of a digital PID control loop. `\lstinline{PID_init()}' initialises and sets up the controller, and `\lstinline{PID_update()}' calculates the new output of the controller. The full driver implementation can be found in \Cref{A:pid_code}.

\section{Full system implementation}

\subsubsection*{Software implementation}

The full system software implementation is built upon the ESP-IDF framework, and utilises a FreeRTOS to provide tasks and scheduling. 

The ESP-IDF Framework was chosen over other supported frameworks due to it's increased control of the ESP32 available hardware peripherals, which was required for the designs system to meet it's specified requirements from \Cref{F:sys_overview}. 

The use of the ESP-IDF framework also facilitated the use of FreeRTOS, providing access to a task scheduler that would greatly decrease the structural complexity of this system. This scheduler allows each subsystem within the design to operate from within a task, independent of all others. therefore, this implementation reduces the complexity of further developments within this project, without limiting the functionality of the microcontroller platform. The full system software implementation can be found in \Cref{A:main_code}.

\subsubsection*{Hardware implementation}

To facilitate the ease of use of the fully designed system, a printed circuit board (PCB) was designed and implemented using the KiCAD software platform. This PCB implements all finalised designed elements discussed in \Cref{C:design}, and provides multiple footprints for the buck converter output filter to allow for expedited testing and varying filters. For the full system schematic, refer to \Cref{A:pcb_and_schematic}.

\begin{figure}[!h]
    \centering
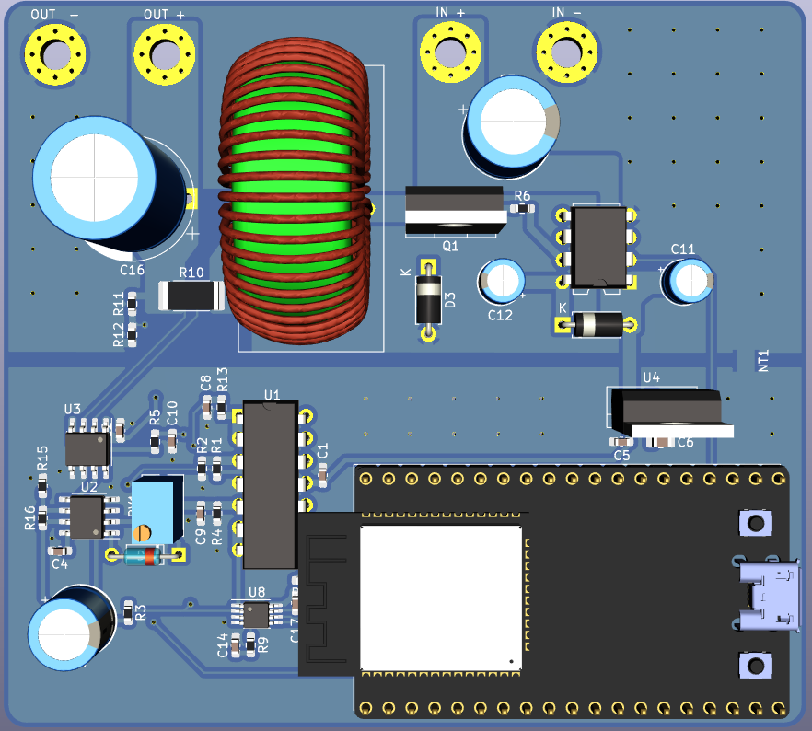
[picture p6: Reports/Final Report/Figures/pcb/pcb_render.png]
    
    \caption{Full system printed circuit board implementation}
    \label{F:implemented_pcb}
\end{figure}

% Discuss how the code implements each of the hardware sections designed. Then also discuss how the full system has been implemented on a PCB 
% Discuss the ESP-IDF HAL (Hardware Abstraction Layer), and how it provides greater control of the system resources than the more commonly used Arduino platform. 
% \\
% Then discuss how the system operates within the freeRTOS real time operating system, what allows for easy multitasking between the different time sensitive control loops that will have to be run on the micro.  
% \\
% Finally discuss the simple to use API that was implemented, which aims to abstract away the HAL layer. This API is implemented using collection of single header libraries written in the 'C' programming language, with each implementing only the core functionality of the hardware they are interacting with. This makes the software platform robust and simple to move to different embedded platforms, with such a move only requiring the re-implementation of the core functions of each library.

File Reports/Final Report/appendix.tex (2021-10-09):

\appendix

\include{acknowledge}

\include{appendix/system_specifications}

\include{appendix/pwm_figures_and_tables}

\include{appendix/peak_detector_figures_and_tables}

\include{appendix/control_figures.tex}

\include{appendix/schematic_and_pcb}

\include{appendix/breadboard_implementation}

\include{appendix/source_code}

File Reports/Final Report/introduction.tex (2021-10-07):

\chapter{Introduction}\label{C:intro}

Historically power distribution has been primarily in the form of AC (Alternating current). This is credited to the fact that AC power is simple to produce, and made it easy to step up and down the voltages efficiently with transformers \cite{Earley2013}. However, with the invention of solid-state electronics such as the metal–oxide–semiconductor field-effect transistor or MOSFET for short, it has become possible to efficiently step up and step down direct current (DC) voltages. This has been achieved by the invention of the switch-mode power supply, which has facilitated the continued reduction of size and increase in efficiency of electronics \cite{Bocock}.

Today, switch-mode power supplies can be found in a wide variety of consumer and professional electronics, with some examples being laptops, phones, and any form of DC charger. Their widespread usage when compared to other DC-DC converters such as linear regulators can be attributed to their far greater efficiency. One such switch-mode power supply is the buck converter, which will step down a DC input voltage to a lower DC output voltage.

\section{Project Motivation}

Although buck converters are a widespread technology, they are not without their limitations and drawbacks. The current buck converter design process requires that a specific output filter be designed around the switching frequency of the converter, and the desired inductor ripple current. This filter design process will often result in the converter requiring discrete passive components that are non-standard and hard to source. This will usually result in the designer having to make compromises in their design for either the cost or the performance of the converter.

Another drawback of this design process is the static nature of both the filter and the switching components once they have been selected. This results in the buck converters desired inductor current ripple only being achieved at a very specific designed output voltage or load. This means that with current buck converter designs varying the desired output voltage or varying the output load will cause the inductor current ripple to vary. This is an issue, as very few loads are static and will not change during their operation. 

\section{Project Goals}\label{S:goals}

The goal of this project is to develop a testing platform through which the effects of variable buck converter switching frequency on inductor current ripple can be observed and controlled. The aim of this is to eliminate the need to design the output stage of the buck converter by implementing a control system to maintain a specified inductor current ripple, and output voltage.\\

To achieve this goal, a proof of concept buck converter will be designed to operate as the testing platform. This converter will require a variable frequency pulse width modulated (PWM) signal generator, and inductor current ripple sensing. This will allow for direct manipulation and control of inductor current ripple. The converter will also need to implement the full functionality of existing buck converter designs, including controlled output voltage regulation.

It is also important to note that as this project aims to produce a testing platform to be used as a proof of concept, there will be continued work undertaken after the projects conclusion. Because of this, it is important that the design and implementation undertaken in this project considers the ease of use and future expansion of the project.\\

The following list of specifications outlines the requirements the designed test platform will meet:

\begin{enumerate}
    \item Operate with a 12V DC input supply voltage
    \item Provide a selectable DC output voltage between 3V and 10V
    \item Provide an output voltage precision of at least $\pm5\%$ of the targeted output voltage
    \item Provide a selectable inductor current ripple between 20\% and 50\% of the total output current
    \item Provide a variable converter switching frequency between 1$k$Hz and 100$k$Hz
    \item Provide an inductor current ripple precision of at least $\pm5$\% of the target inductor current ripple 
    \item Operate with variable load sizes between 10$\Omega$ and 20 $\Omega$
\end{enumerate}

% This project aims to eliminate the need to design the output stage of a buck converter. By implementing a control system that varies the switching frequency of the converter, we will be able to directly manipulate the inductor current ripple. This project aims to produce a proof of concept buck converter that is capable of operating at 12V, with an output range of 3-10V and precision of $\pm5\%$. The converter will also be able vary its switching frequency between 1$kHz$ and 100$kHz$, allowing for selection of inductor current ripple between 20\% and 50\% with precision of $\pm5\%$. All of this must be implemented while maintaining the standard functionality of the converter.

% \subsubsection{TODO Expand on the project goals, possibly convert the previous section into a bulleted list of project goals and requirements.}

% This will be referenced in the implementation and design sections many times, so it needs to clearly outline what we are looking to achieve in this project.

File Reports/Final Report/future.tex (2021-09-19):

\chapter{Future Plan}\label{C:future} 

This final chapter will outline the work that is yet to be completed for this project, and how we plan complete it. It will also discuss how we plan to evaluate this system once this future work has been completed, outlining the changes to the evaluation that have come about since the project proposal. Finally this chapter will then present the project timeline for the remaining work and evaluation, breaking down this work into discrete blocks of time. 

\section{Work to be Completed}\label{S:work_remaining}

As discussed in \Cref{S:system_design}, there are 3 main segments of work in this project. The first segment of work was the PWM generator, which has been outlined in \Cref{S:pwm_gen_design} and has already been completed. The next two section were the specification and selection of the required sensing elements, and then the implementation of the control system that will make this project functional.\\

To complete the specification and selection of the sensing elements, a large amount of background research will need to be completed. This research will include the identifying of various ways that the inductor current ripple can be measured, as well as defining the required specifications of the sensors based on the system requirements. Once this research has been completed and components have been selected, it will be important to evaluate the functionality of the components, to verify that they do meet the required specifications. Finally once the sensing elements have been selected and tested, the creation of a printed circuit board (PCB) to hold the PWM generator, sensing elements, and buck converter will be completed. This PCB will be the final physical artefact that is created from this project. \\

Once this physical artefact has been generated, the only section left to be completed is the projects control system. This control system will be responsible for regulating both the inductor ripple current and the buck converter output voltage. To be able to successfully implement this section of the project I will again need to perform a section of background research. This research will inform the design and implementation of this controller within the microcontroller, helping to select the controller architecture and structure. Once the controller design has been specified, it will need to be implemented in software on the microcontroller, allowing for time to test the implementation. 

\section{System Evaluation}

    The evaluation of this system has not changed substantially since the project proposal, and is still based upon meeting the following selection of specifications. 
    
    However, the evaluation of the system will now be conducted using a range of load resistances, evaluating its performance with 10$\Omega$, 15$\Omega$, and 20$\Omega$ output loads, using a constant supply voltage of 12V DC.

\begin{itemize}
	\item The buck converter will be able to take input voltages up to 12V DC
	
	\item The buck converter must maintain the basic functionality outlined in \cref{E:V_out}

	\item The buck converter will have an output voltage range between 3V and 10V DC
	
	\item The output voltage accuracy will be within $\pm 5\%$ of the target output voltage

	\item The user will be able to define the inductor ripple between 20\% and 50\%
	
	\item The inductor ripple accuracy will be within $\pm 5\%$ of the defined inductor ripple
	
	\item The buck converter will have a switching frequency range of 1k$Hz$ to 100k$Hz$

	\item The control system will have no steady state error

\end{itemize}

Since all of these evaluation metrics are highly qualitative, the evaluation of the final artefact will consist of a series of tests that will look to confirm the systems ability to achieve each of theses requirements.  

\section{Project Timeline}

The Gantt chart in \Cref{F:gantt} directly relates the remaining work set out in \Cref{S:work_remaining} to the time remaining for the project. For both the sensing element design and the control system, we believe that a large amount of background research will need to be completed before work is able to commence. This background research will inform and help reduce the time require to effectively design these sections. we plan to have all of the implementation and evaluation of the system completed before the end of the mid trimester break, as this will allow for a large amount of report writing time.

\begin{figure}[H]
    
    \caption{Proposed project timeline}
    \label{F:gantt}
\end{figure}

\section*{Feedback}\label{S:feedback} 

At this stage in the project I have a very clear idea as to what I am planning to, and how I am planning to get there. I would also greatly appreciate all feedback that can be provided on this report, so that I can implement the changes in my final report. I would greatly appreciate it if It would be possible to organise an in person meeting with my markers to discuss this report and project.

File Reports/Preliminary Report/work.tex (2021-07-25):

\chapter{Work Completed}\label{C:work}

This chapter will discuss the work that has been completed so far on this project. It will begin by discussing the projects requirements', using them to design and justify the final specifications of the system. Once the specifications are outlined, the architecture and design of the final system will be discussed. Finally the design and current implementation of the PWM signal generator will be specified.  

\section{Defining \& Justifying System Specifications}\label{S:specs}

Based on the system requirements that have been outlined in \Cref{C:intro}, a set of system specifications can be created to inform the design. Current work on this project has been towards the implementation of the PWM signal generator, and as such all specifications outlined will pertain to this work.

The final system is required to be able to select both the output voltage and inductor current ripple of the buck converter. From this requirement we specify that our PWM generator must vary both the duty cycle and the switching frequency of the buck converter, based on \Cref{E:V_out} \& \Cref{E:delta_i}. The requirements also specify the level of precision that will be required for these selections, allowing us to specify the tolerable error. Using these same equations, the minimum duty cycle step size in \Cref{E:duty_step}, the inductor minimum and maximum values in \Cref{E:L_min} \& \Cref{E:L_max}, and the frequency step size in \Cref{E:f_step} have all been derived. For the derivation of these values see \Cref*{A:specs}.\\

Duty cycle step calculation:
\begin{align}
    V_{error} &= V_{min} \cdot error = 0.15V\\
    D_{step} &= \frac{V_{error}}{V_{in}} = 0.0125\\
    N_{step} &= \frac{1}{D_{step}} = 80 \label{E:duty_step}
\end{align}

Inductor Sizing Calculations:
\begin{align}
    L_{max}&=\frac{V_{max}\cdot\left(1-D_{max}\right)}{f_{min}\cdot I_{min}} = 27.7mH \label{E:L_max}\\ 
    L_{min}&=\frac{\frac{V_{in}}{2}\cdot\left(1-0.5\right)}{f_{max}\cdot I_{min}} = 0.5mH \label{E:L_min}
\end{align}

Frequency step calculation:
\begin{align}
    f_{step}&=\frac{V_{max}\cdot\left(1-D_{max}\right)}{\left(I_{min}-I_{Error}\right)\cdot L_{max}}-f_{min} = 52Hz\\
    N_{steps}&=\frac{\left(f_{max}-f_{min}\right)}{f_{step}} = 1881 \label{E:f_step}
\end{align}

From these equations we can build a list of final specifications to inform the design of our PWM generator and buck converter. The PWM generator must provide a minimum voltage step size of $0.0125V$, for a resolution of 80 voltage steps between 3V and 10V. The PWM generator must also be able to provide a minimum frequency step size of $52Hz$, for a resolution of 1881 frequency steps between $1KHz$ \& $100kHz$. Finally we can also specify that the buck converter must be capable of functioning with inductor values between $0.5mH$ \& $27.7mH$. \\

By designing the PWM generator and the buck converter to these specifications, we are able to guarantee that we can always achieve the requirements outlined in \Cref{C:intro}.

\section{System Architecture \& Design}\label{S:system}

To achieve the specifications that have been outlined in \Cref{S:specs}, it is important to design the system architecture around them. In \Cref{F:sys_overview} an overview of the system architecture can be seen, with three main design sections outlined. These sections each represent a significant segment of work that must be completed for the final artefact of this project to be achieved. \\

The first section of work that must be completed is the design of the PWM generation, denoted 1 in \Cref{F:sys_overview}. This PWM generator will be used to control both the output voltage and the inductor current ripple, and as such must be able to modulate both the duty cycle and the frequency of the PWM to the precisions required. \\

The second section of work is the design of the sensing elements required by the system, denoted 2 in \Cref{F:sys_overview}. These elements will be used to measure both the output voltage and the inductor current ripple, and therefor must be able to achieve the required precisions and sampling rates. \\

Finally the third section of work is the design and implementation of the two control systems, denoted 3 in \Cref{F:sys_overview}. These control systems will be responsible for maintaining the desired output voltage and inductor current ripple of the buck converter. This system will therefor be responsible for facilitating the final functionality of the project, combining sections 1 \& 2. \\

\begin{figure}[!h]
    
    \caption{High level system overview}
    \vspace{-20pt}
    \label{F:sys_overview}
\end{figure}

\section{PWM Generation Design}\label{S:pwm_gen}

In the design of the PWM generator, both the analogue and digital designs discussed in \Cref{S:PWM} were considered, designed, and tested for. Each of these designs presented pros and cons that would affects the overall design of the system architecture. This section will discuss these designs and finalise the design of the PWM generator for this system. 

\subsection{Analogue PWM Generator Design}\label{S:analogue_design}

As discussed in \Cref{S:analogue_PWM}, the design of the analogue PWM signal generator requires three stages, each of which will have its own design requirements based on the specifications outlined in \Cref{S:specs}. \\

The clock generation stage will be responsible for setting the frequency of the final PWM signal. This specifies that the clock source have a variable frequency output range between $1kHz$ and $100kHz$, with a minimum step size of $52Hz$. Research was done on a variety of clock sources, looking at voltage-controlled oscillators (VCO's), signal generator IC's, and even the basic 555 timer. From this VCO's were identified to operate at much higher frequencies than those used in this project. It was also identified that signal generator IC's often require selections of passive components to operate effectively, increasing their complexity. For this reason the variable frequency 555 timer circuit was selected, as it provided the required specifications.\\

The next section designed was the signal integrator stage. This stage consisted of a basic op-amp integrator circuit, with a design requirement that it be able to integrate the clock signal across the frequency range required. This circuit was designed and implemented in an LTSpice simulation to evaluate it's performance, and can be seen in \Cref*{A:analogue_PWM}. From this simulation it was noted that the integrator's frequency response was similar to that of a first order low pass filter, and greatly attenuated the integrated signal. For this reason it was decided that analogue PWM generation would not be implemented in this system, as it presented many issues.

\subsection{Digital PWM Generator Design}\label{S:digital_design}

As discussed in \Cref{S:digital_PWM}, The design of the digital PWM generator is far simpler than that of the analogue, and can be implemented in a wide variety of methods. In this project microcontrollers and FPGA's have been considered.

Based solely on the capabilities of the platform, the PWM generator would be best designed and implemented on an FPGA as it would allow for superior speed and precision. However FGPA design brings a lot of difficulties, primarily in the prototyping and testing stages. Because of this, due to the limited time from of this project, we have decided to implement this PWM design using a microcontroller.

The selection of the microcontroller is highly dependant on the clock frequency and design of the PWM peripherals, as it must be capable of achieving the specifications outlined in \Cref{S:specs}. A large selection of microcontroller datasheets were reviewed to identify their specifications, including AVR, STM8, Espressif, and teensy based microcontrollers. From this review it was decided that the ESP32 microcontroller would be best suited to this project \cite{ESP32Manual}. This microcontroller is capable of outputting a maximum PWM frequency 125$kHz$ with a duty cycle resolution of 9 bits (512 voltage steps). From here a short C program was written to test the PWM functionality of the ESP32, and it was confirmed that it met the required specifications. The source code and images of this PWM signal can be found in \Cref{A:digital_PWM}.

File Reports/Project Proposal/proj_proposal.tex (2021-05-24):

%% $RCSfile: proj_proposal.tex,v $
%% $Revision: 1.3 $
%% $Date: 2016/06/10 03:44:08 $
%% $Author: kevin $

\documentclass[11pt, a4paper, oneside]{report}

\usepackage{float} % lets you have non-floating floats
\usepackage{url} % for typesetting URLs
\usepackage{wrapfig}
\usepackage[image,ecs]{vuwproject}

\renewcommand{\thesection}{\arabic{section}}
\setlength{\parindent}{0pt}
\setlength{\parskip}{\baselineskip}

%  We don't want figures to float so we define
%
\newfloat{fig}{thp}{lof}[chapter]
\floatname{fig}{Figure}
\graphicspath{ {./Figures/} }

\title{Self Tuning Buck Converter}
\author{Niels Daniel Clayton}
\supervisor{Daniel Burmester, Ramesh Rayudu}
\date{}
\otherdegree{Honours of Electronic and Computer System Engineering}

\begin{document}

% Make the page numbering Roman, until after the contents, etc.
\frontmatter

%%%%%%%%%%%%%%%%%%%%%%%%%%%%%%%%%%%%%%%%%%%%%%%%%%%%%%%

\begin{abstract}

	Switch-mode power supplies are commonly used in a wide variety of consumer and professional appliances to transform DC voltages with high efficiency. One such converter is the buck converter. The design of the buck converter requires specific components to design the output filter. These components be difficult to purchase or accurately manufacture. This project will implement a control system to actively control the switching frequency and eliminate the need design the output filter.

\end{abstract}

%%%%%%%%%%%%%%%%%%%%%%%%%%%%%%%%%%%%%%%%%%%%%%%%%%%%%%%

\maketitle

\tableofcontents

% we want a list of the figures we defined
%\listof{fig}{Figures}

%%%%%%%%%%%%%%%%%%%%%%%%%%%%%%%%%%%%%%%%%%%%%%%%%%%%%%%

\mainmatter

%%%%%%%%%%%%%%%%%%%%%%%%%%%%%%%%%%%%%%%%%%%%%%%%%%%%%%%

\section{Introduction}

\subsection{Switch Mode Power Supplies}

Switch-mode power supplies convert a DC input voltage to another DC output voltage. They are commonly used in a wide variety of consumer and professional appliances such as laptops and chargers due to their high efficiency compared to other DC-to-DC converters.

The step-down switch mode power supply also known as a buck converter, is a common DC-to-DC power converter that steps down an input voltage to the desired output efficiently. Currently, the design of these converters for specific applications requires a specifically designed output filter, designed around the switching speed of the converter. This filter will smooth the converter output voltage and maintain the inductor current ripple at the designed values. However this design process is not always applicable, if the specified components for the filter are not available there can be lead times, cost implications and delays.

\begin{figure}[h!]
	\begin{center}
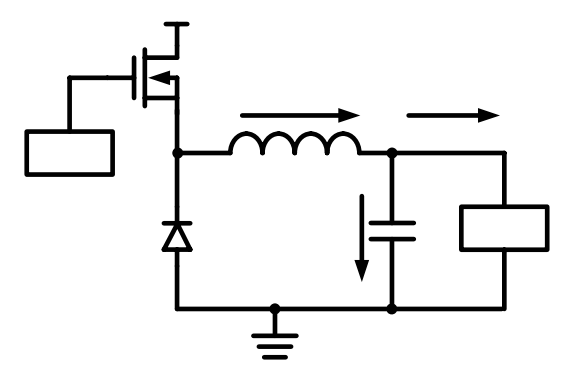
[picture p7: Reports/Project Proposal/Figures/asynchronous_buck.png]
		
		\caption{Asynchronous buck converter topology \cite{BuckTopology}}
		\label{asynchronous_buck}
	\end{center}
\end{figure}

This project aims to remove the need for designing the output stage of the buck converter. Using a control system, the switching frequency and duty cycle of the converter can be modulated to meet a selected inductor ripple, while maintaining a selected output voltage. This project will focus on the design and implementation of this control system on a basic asynchronous buck converter.
\newpage

\section{The Problem}

The current buck converter design requires that a specific output filter be designed around the switching frequency of the converter, and the desired inductor ripple. This filter design process will often result in the designer requiring discrete passive components that are not easily available. This requirement for precise discrete components can greatly increase the cost of the converter, and can also cause delays in manufacturing due to the lead time of components.

Another side effect of this design process is that this desired inductor ripple will only be achieved at the designed output voltage or load. This means that in current buck converter designs, varying the output voltage, or output load will cause the inductor ripple to vary. This can lead to the buck converter no-longer meeting the required specifications, making it hard to design a converter for a complex load.

This project aims to eliminate the need to design the output stage of a buck converter. This will be achieved by implementing a control system to vary both the switching frequency and duty cycle, to achieve the desired inductor ripple and output voltage. This will allow the buck converter to actively adjust the switching frequency to match the currently designed output filter at all times.

\section{Proposed Solution}

The proposed solution to this problem will have 3 phases, the initial research and setup, the design, and the implementation phase. Each phase will have a selection of tasks that must be completed to be able to progress to the following phase. The following subsections will go into detail on the undertakings of each phase. For time estimations of each task please look at the Gantt chart in Figure \ref{fig:gantt}.

\subsection{Research and Set-up}

The first phase of this project is the research and setup. The major component of this phase is the creation of the literature review that will be the basis of this project. In this literature review, I will compare and contrast a wide range of methods available to produce a frequency variable PWM signal. This review will also be used to compare and contrast varying sensing methods for sampling the inductor ripple and the output voltage.

When the literature review is complete, I will select the methods of PWM generation and output sensing that are most suitable for this project. This will help me identify a range of components that I believe will be feasible for the design. These components will be purchased for used in the design phase.

Finally, once the components have been purchased I will design a selection of development PCB's that will allow for simplistic interfacing with the purchased components and the existing buck converter design. This will help expedite the design phase.

\subsection{Design}
\label{sec:design}

In the design phase of the project, I will test and evaluate all of the selected PWM generation methods, and sensing methods. This will involve a large amount of prototyping on breadboards, along with possibly embedded programming on microcontrollers, and FPGA (Field Programmable Gate Array) design. The method of evaluation of these designs will be decided upon in the literature review.

Once the evaluation of the designs is complete, I will make the final hardware selection. The components selected at this stage will be used to implement the closed-loop controller for the converter.

\subsection{Implementation}

Finally, in the implementation phase of the project, the finalised hardware design will be used to implement the closed-loop control system. This system will sample the inductor ripple and vary the switching speed and duty cycle of the buck converter to reach a requested ripple value. A Simulink simulation may be designed to help with the implementation and design of this controller.

As the controller is being implemented, I will also design a final PCB for the buck converter. This PCB will include the entire buck converter design, with female headers for easy filter inductor and capacitor swapping.

\begin{figure}[!h]
	\begin{center}
		
		\caption{Project Gantt Chart}
		\label{fig:gantt}
	\end{center}
\end{figure}

\newpage
\section{Project Evaluation}

The evaluation of this project will be based upon meeting the following selection of specifications. All evaluations of the design will be conducted using a 10$\Omega$ output load, with an input voltage of 12V DC.

\begin{itemize}
	\item The buck converter will be able to take input voltages up to 12V DC
	
	\item The buck converter maintains basic functionality of $V_{out} = D\times V_{in} - \mathrm{effeciency}$

	\item The buck converter will output voltages between 3V and 10V DC
	
	\item The output voltage accuracy will be within $\pm 5\%$ of the target output voltage

	\item The user will be able to define the inductor ripple between 20\% and 50\%, with increments of 5\%.
	
	\item The inductor ripple accuracy will be within $\pm 5\%$ of the defined inductor ripple
	
	\item The buck converter will have a switching frequency range of 1k$Hz$ to 100k$Hz$
\end{itemize}

\section{Safety and Resourcing}

\subsection{Safety Considerations}

Below in Table \ref{tab:hazzard} there is a safety hazard identification, prevention, and mitigation table.

\begin{table}[!h]
	\begin{tabular}{|l|l|l|}
		\hline
		\multicolumn{1}{|c|}{Potential Hazards} & \multicolumn{1}{c|}{Hazard Prevention} & \multicolumn{1}{c|}{Hazard Mitigation} \\ \hline
		\begin{tabular}[c]{@{}l@{}}Burns due to resistive\\ elements heating \\ during use.\end{tabular}               & \begin{tabular}[c]{@{}l@{}}Ensure that no more than 5W of \\ power is dissipated across the \\ load at any time.\end{tabular}              & \begin{tabular}[c]{@{}l@{}}Turn off equipment that is \\ overheating.\end{tabular}              \\ \hline
		\begin{tabular}[c]{@{}l@{}}Cuts due to misuse \\ of wire cutters\end{tabular}               & \begin{tabular}[c]{@{}l@{}}Ensure that there are no \\ distractions when operating \\ potentially hazardous equipment.\end{tabular}              & \begin{tabular}[c]{@{}l@{}}Bandage the cut, and fill out \\ an accident/incident report.\end{tabular}             \\ \hline
		\begin{tabular}[c]{@{}l@{}}Burns due to misuse \\ of soldering iron\end{tabular}              & \begin{tabular}[c]{@{}l@{}}Ensure that there are no \\ distractions when operating \\ potentially hazardous equipment. \\ Make sure to correctly store \\ the soldering iron after use.\end{tabular}             & \begin{tabular}[c]{@{}l@{}}Apply ice to the burn and fill out \\ an accident/incident report.\end{tabular}             \\ \hline
		Dangerous voltages                      & \begin{tabular}[c]{@{}l@{}}Ensure that the power supply \\ never outputs more than the \\ maximum of 50V.\end{tabular}             & Turn off that is not operating safely  \\ \hline
	\end{tabular}
	\caption{Hazard assessment }
	\label{tab:hazzard}
\end{table}

\newpage
\subsection{Required Equipment}
\label{sec:equipment}
The Following list of equipment is currently available without purchase, but will be required for this project:

\begin{itemize}
	\item Lab bench power supply
	\item Lab bench oscilloscope
	\item Lab bench signal generator
	\item lab bench multi-meter
	\item Prototyping breadboards
	\item Passive components (resistors, inductors, capacitors, MOSFETs)
\end{itemize}

\subsection{Budget}

Below in Table \ref{tab:budget} is the total estimated cost of the components I will need to purchase for this project.

\begin{table}[!h]
	\begin{tabular}{|l|l|l|}
		\hline
		\multicolumn{1}{|c|}{Component} & \multicolumn{1}{c|}{Description}                                          & Cost  \\ \hline
		PCB Manufacturing               & In house or external PCB manufacturing                                    & \$50  \\ \hline
		Assorted components             & Parts to be tested and evaluated as discussed in section \ref{sec:design} & \$200 \\ \hline
	\end{tabular}
	\caption{Budget }
	\label{tab:budget}
\end{table}

\subsection{Covid-19 Considerations}

Due to the effects of Covid-19 lock-downs, it is important to be prepared for the possible implication of going to the varying alert levels will have.

In the case of alert level 2, the university will still be open and operating with enforced social distancing and masks. This alert level will have little to no effect on the progress of this project, as the honours lab allows for social distancing.

In the case of alert level 3 \& 4, the university will close. This means that I will not be able to access the honours lab to get to my equipment. In the case of alert level 3 or 4, I will have to ask the technicians if I am able to bring home with me the equipment listed in section \ref{sec:equipment} to continue working from home. If this is not possible then I will work to make an accurate simulation of the Project within Simulink.

%%%%%%%%%%%%%%%%%%%%%%%%%%%%%%%%%%%%%%%%%%%%%%%%%%%%%%%
\backmatter
%%%%%%%%%%%%%%%%%%%%%%%%%%%%%%%%%%%%%%%%%%%%%%%%%%%%%%%

\bibliographystyle{ieeetr}
\bibliography{bibliography}
\end{document}

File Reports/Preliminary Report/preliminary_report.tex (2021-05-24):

%% $RCSfile: proj_report_outline.tex,v $
%% $Revision: 1.3 $
%% $Date: 2016/06/10 03:41:54 $
%% $Author: kevin $

\documentclass[11pt, a4paper, oneside]{report}

\usepackage{float} % lets you have non-floating floats
\usepackage{url} % for typesetting urls

\usepackage{amsmath}

\usepackage{hyperref}
\usepackage{cleveref}

\usepackage{wrapfig}
\usepackage{subcaption}
\usepackage{graphicx}

\usepackage{pdfpages}

% Include C code
\usepackage{listings}
\lstset{
  language=C,                % choose the language of the code
  numbers=left,                   % where to put the line-numbers
  stepnumber=1,                   % the step between two line-numbers.        
  numbersep=5pt,                  % how far the line-numbers are from the code
  backgroundcolor=\color{white},  % choose the background color. You must add \usepackage{color}
  showspaces=false,               % show spaces adding particular underscores
  showstringspaces=false,         % underline spaces within strings
  showtabs=false,                 % show tabs within strings adding particular underscores
  tabsize=2,                      % sets default tabsize to 2 spaces
  captionpos=b,                   % sets the caption-position to bottom
  breaklines=true,                % sets automatic line breaking
  breakatwhitespace=true,         % sets if automatic breaks should only happen at whitespace
  title=\lstname,                 % show the filename of files included with \lstinputlisting;
}

\hypersetup{
    colorlinks=true,
    linkcolor=black,
    filecolor=black,
    citecolor=black,
    urlcolor=black,
}

\usepackage[image,ecs]{vuwproject}

% \renewcommand{\thesection}{\arabic{section}}
% \setlength{\parskip}{\baselineskip}
\setlength{\parindent}{0pt}

\usepackage{titlesec}
\titleformat{\chapter}[hang] 
{\normalfont\huge\bfseries}{\chaptertitlename\ \thechapter:}{1em}{} 

%
%  We don't want figures to float so we define
%
\newfloat{fig}{thp}{lof}[chapter]
\floatname{fig}{Figure}
\graphicspath{ {./Figures/} }

%% These are standard LaTeX definitions for the document
%%                            
\title{Self Tuning Buck Converter}
\author{Niels Clayton}

\supervisors{Daniel Burmester and Ramesh Rayudu}
\otherdegree{Bachelor of Engineering with Honours}

\date{}

\begin{document}

\frontmatter

%%%%%%%%%%%%%%%%%%%%%%%%%%%%%%%%%%%%%%%%%%%%%%%%%%%%%%%

\begin{abstract}

    Switch-mode power supplies are commonly used in a wide variety of consumer and professional appliances to transform DC voltages with high efficiency. One such switch-mode supply is the buck converter, which steps down a DC voltage. The current buck converter design process requires that a specific output filter be designed around the switching frequency of the converter, the required output voltage, and the desired inductor ripple. This filter design process often results in the selection of non-standards components that are difficult to purchase or manufacture, increasing costs and leading to design compromises. This project will implement a control system to actively control the inductor current ripple by modulating the switching frequency of the converter. This will allow engineers to design buck converters directly for the inductor current ripple they wish to tolerate, eliminating the issues of designing this output filter.

\end{abstract}

%%%%%%%%%%%%%%%%%%%%%%%%%%%%%%%%%%%%%%%%%%%%%%%%%%%%%%%

\maketitle

% \include{acknowledge}
% \listof{fig}{figures}
\tableofcontents

%%%%%%%%%%%%%%%%%%%%%%%%%%%%%%%%%%%%%%%%%%%%%%%%%%%%%%%

\mainmatter

%%%%%%%%%%%%%%%%%%%%%%%%%%%%%%%%%%%%%%%%%%%%%%%%%%%%%%%

% individual chapters included here
\include{introduction}
\include{background}
\include{work}
\include{future}

%%%%%%%%%%%%%%%%%%%%%%%%%%%%%%%%%%%%%%%%%%%%%%%%%%%%%%%

\backmatter

%%%%%%%%%%%%%%%%%%%%%%%%%%%%%%%%%%%%%%%%%%%%%%%%%%%%%%%

\bibliographystyle{ieeetr}
% \bibliographystyle{acm}
\bibliography{../../Literature/bibliography}

\appendix
\input{appendix}

\end{document}

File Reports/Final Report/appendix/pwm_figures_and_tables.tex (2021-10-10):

\chapter{PWM Generation Figures} \label{A:PWM}

\section*{Analogue PWM Generation} \label{A:analogue_PWM}

\begin{figure}[H]
    \begin{center}
        
        \caption{Operational amplifier integrator LTSpice circuit simulation}
    \end{center}
    \vspace{-10pt}
\end{figure}
    
\begin{figure}[H]
    
    \caption{Operational amplifier integrator simulation with a 1$kHz$ square wave input. Output triangle wave amplitude of 1.5V}
    \vspace{-10pt}
\end{figure}

\begin{figure}[H]
    
    \caption{Operational amplifier integrator simulation with a 1$kHz$ square wave input. Output triangle wave amplitude of 20mV}
    \vspace{-10pt}
\end{figure}

\section*{Digital PWM Generation} \label{A:digital_PWM}

\subsection*{PWM Duty Cycle Control}
\begin{figure}[H]
    
    \centering
    \begin{subfigure}{0.45\textwidth}
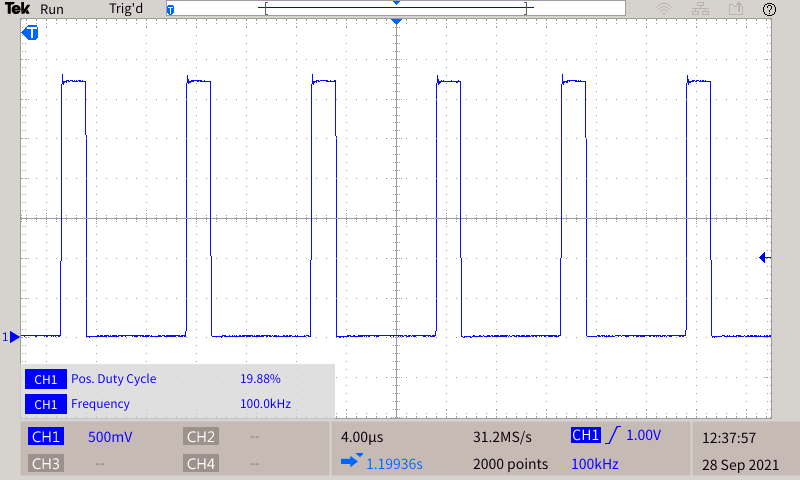
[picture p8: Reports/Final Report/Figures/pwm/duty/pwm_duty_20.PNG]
        
        \subcaption{Digital PWM Generation with a 20\% duty cycle}
    \end{subfigure}
    \begin{subfigure}{0.45\textwidth}
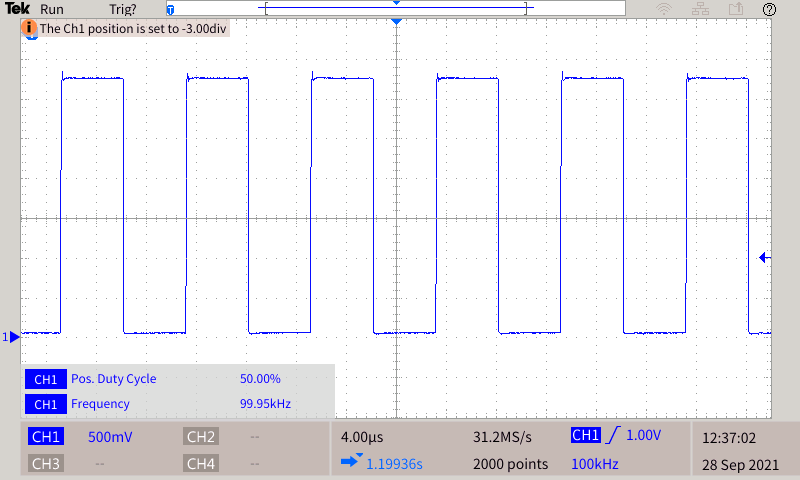
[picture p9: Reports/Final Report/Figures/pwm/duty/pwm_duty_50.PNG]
        
        \subcaption{Digital PWM Generation with a 50\% duty cycle}
    \end{subfigure}
    \begin{subfigure}{0.45\textwidth}
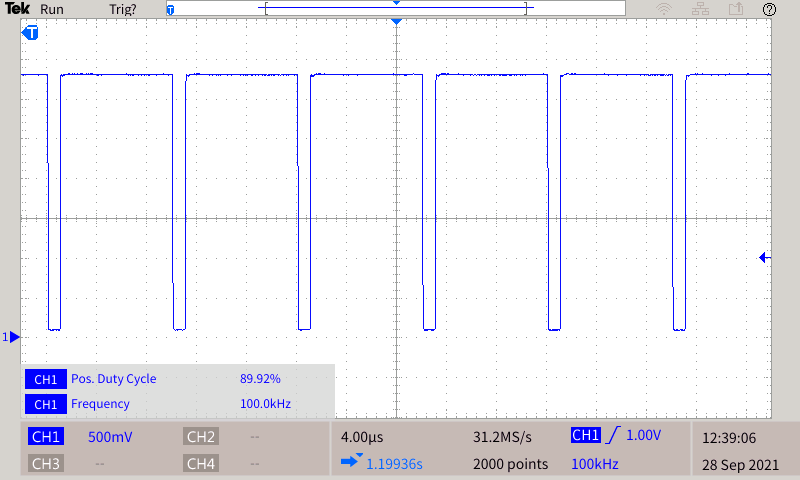
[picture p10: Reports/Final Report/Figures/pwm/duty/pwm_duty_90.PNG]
        
        \subcaption{Digital PWM Generation with a 90\% duty cycle}
    \end{subfigure}
    \caption{Digital PWM: Varying PWM duty cycle with a $100kHz$ frequency}

\end{figure}

\subsection*{PWM Duty Cycle Output range}

\begin{figure}[!h]
    \centering
    
    \caption{Implemented PWM generator full duty cycle selection range}
    \label{A:pwm_range}
\end{figure}

\subsection*{PWM Frequency Control}
\begin{figure}[H]
    \centering
    \begin{subfigure}{0.45\textwidth}
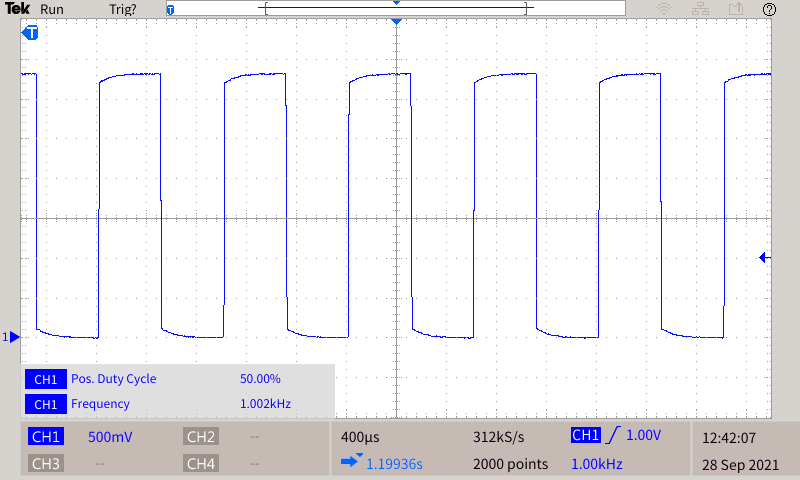
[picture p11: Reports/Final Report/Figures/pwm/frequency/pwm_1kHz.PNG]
        
        \subcaption{Digital PWM Generation with a $1kHz$ frequency}
    \end{subfigure}
    \begin{subfigure}{0.45\textwidth}
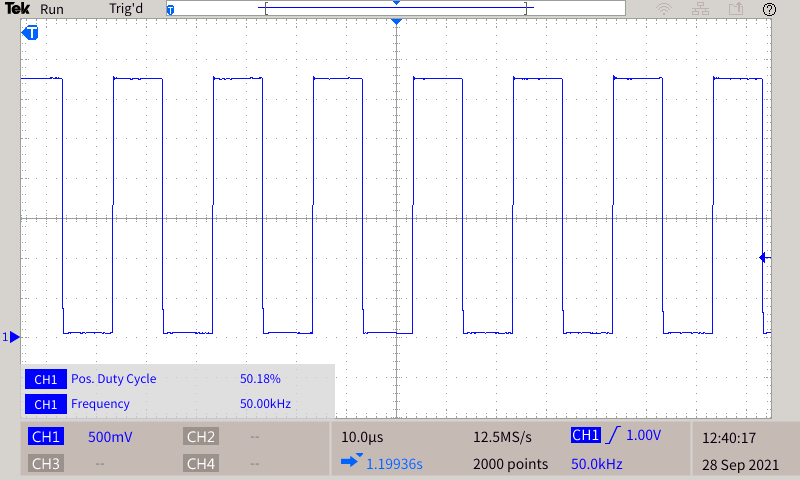
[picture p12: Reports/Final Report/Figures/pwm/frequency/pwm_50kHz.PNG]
        
        \subcaption{Digital PWM Generation with a $50kHz$ frequency}
    \end{subfigure}
    \begin{subfigure}{0.45\textwidth}
        
        \subcaption{Digital PWM Generation with a $100kHz$ frequency}
    \end{subfigure}
    \caption{Digital PWM: Varying PWM frequency with a 50\% duty cycle}

\end{figure}

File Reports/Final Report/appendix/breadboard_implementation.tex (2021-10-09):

\chapter{Breadboard Implementation}\label{A:breadboard}

\section*{PWM Signal Generator \& Control System Breadboard Implementation}

\begin{figure}[H]
    \begin{center}
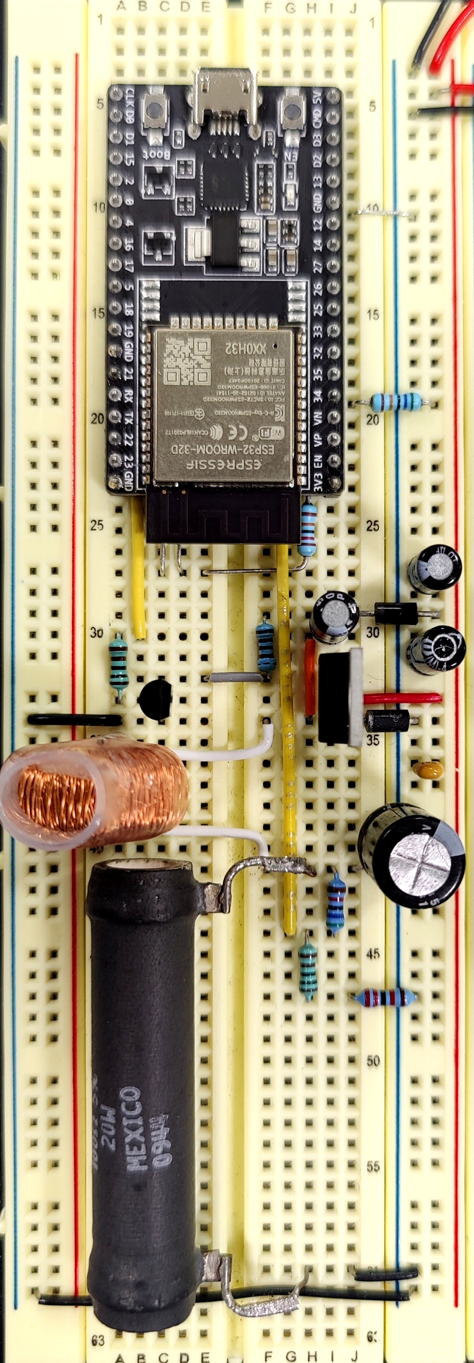
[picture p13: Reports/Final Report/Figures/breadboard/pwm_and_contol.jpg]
        
        \caption{Photograph of the hardware implementation of both the PWM signal generator, and the feedback measurements for the output voltage control system.}
    \end{center}
\end{figure}

\begin{figure}[H]
    \begin{center}
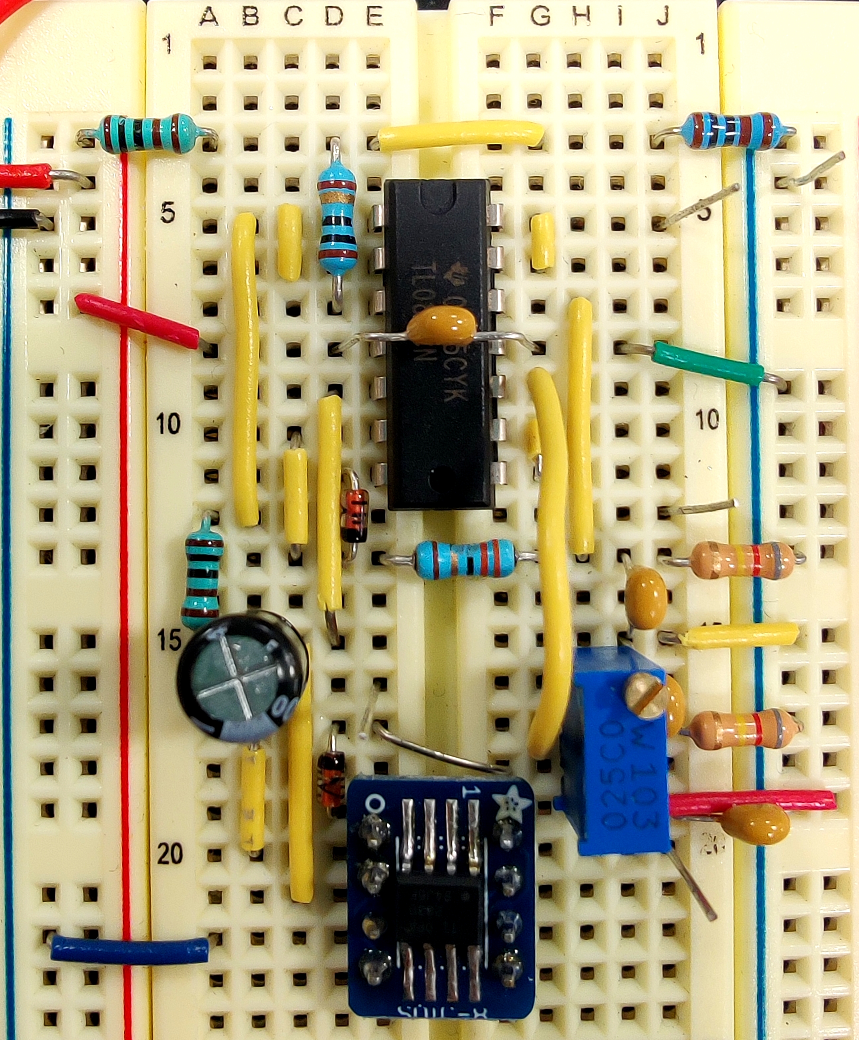
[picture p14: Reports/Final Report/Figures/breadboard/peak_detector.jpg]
        
        \caption{Photograph of the hardware implementation of the inductor current ripple peak detection circuit.}
    \end{center}
\end{figure}

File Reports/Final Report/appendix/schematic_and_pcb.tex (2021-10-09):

\chapter{Schematic \& Printed Circuit Board} \label{A:pcb_and_schematic}

\section*{Full System Schematic} \label{A:full_schematic}

\begin{figure}[H]
        \hspace{-65pt}
        
        \caption{Final system full schematic}

\end{figure}

\section*{Designed Printed Circuit Board}

\begin{figure}[H]
    \begin{center}
        
        \caption{Final system printed circuit board rendering}
    \end{center}
    \vspace{-100pt}
\end{figure}

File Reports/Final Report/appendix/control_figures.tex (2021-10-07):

\chapter{Control System Figures}\label{A:control}
\vspace{-20pt}

\section*{Control System Matlab Simulation}

\begin{figure}[H]
    \begin{center}
        
        \caption{Matlab simulation of the discrete time controlled buck converter with a 3V step input}
    \end{center}
\end{figure}

\section*{Variable Output Voltage Duty Cycle Control} \label{A:control_duty}

\begin{figure}[H]
    
    \centering
    \begin{subfigure}{0.5\textwidth}
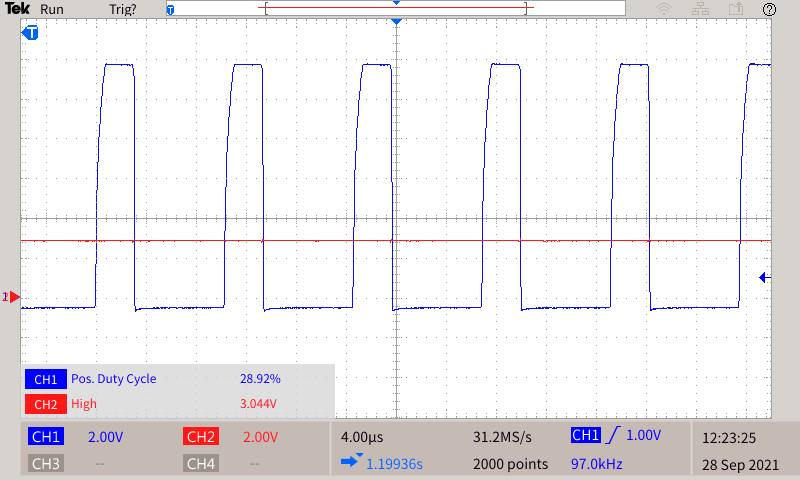
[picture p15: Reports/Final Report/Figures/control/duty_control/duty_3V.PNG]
        
        \subcaption{Controlled duty cycle of 28.9\% for a 3V DC output}
    \end{subfigure}
    \begin{subfigure}{0.5\textwidth}
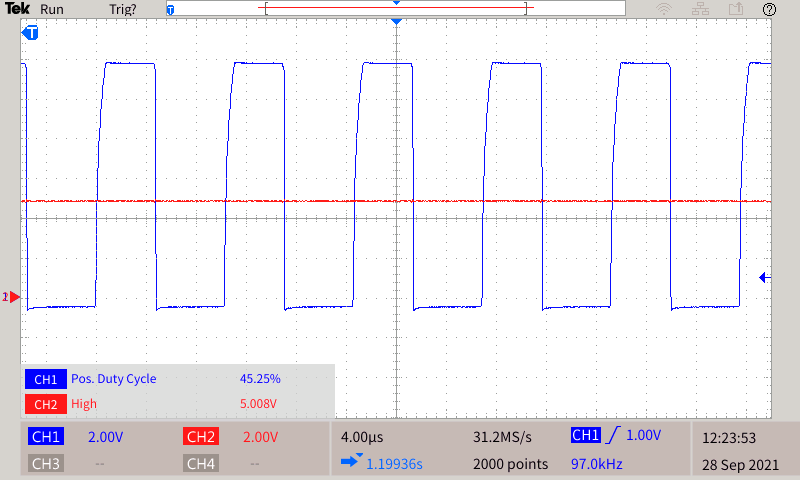
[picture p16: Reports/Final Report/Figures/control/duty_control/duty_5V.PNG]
        
        \subcaption{Controlled duty cycle of 45.25\% for a 5V DC output}
    \end{subfigure}
    \begin{subfigure}{0.5\textwidth}
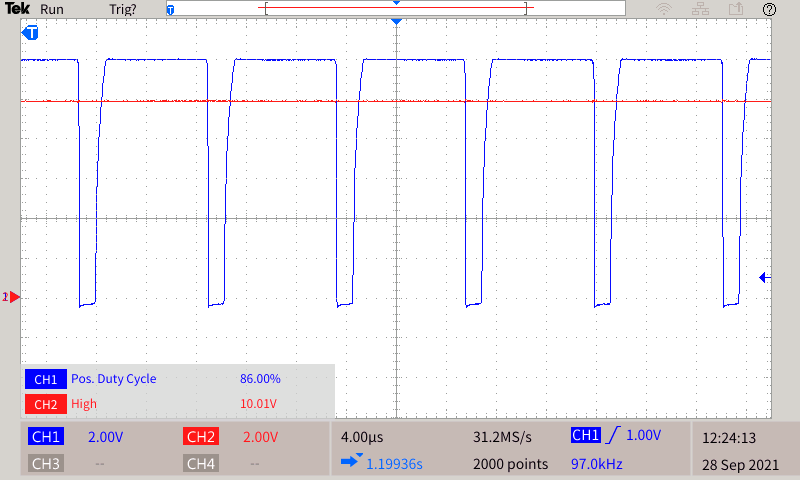
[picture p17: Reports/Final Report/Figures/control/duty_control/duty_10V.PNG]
        
        \subcaption{Controlled duty cycle of 86.0\% for a 10V DC output}
    \end{subfigure}
    \caption{PWM duty cycle controlled by the voltage output control system (Blue), achieving 3V, 5V and 10V DC (Red).}
\end{figure}

\section*{Output Voltage Control System Step Response Rise Time} \label{A:control_step_rise}
\begin{figure}[H]
    \centering
    \begin{subfigure}{0.62\textwidth}
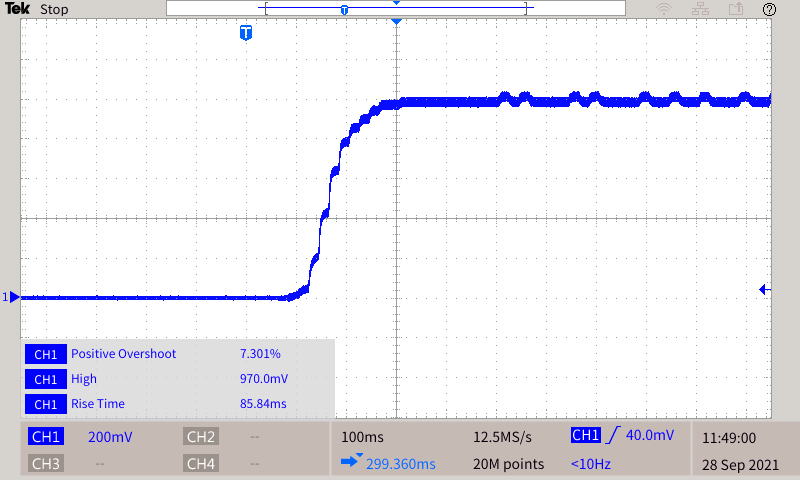
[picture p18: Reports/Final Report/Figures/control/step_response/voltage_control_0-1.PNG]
        
        \subcaption{Output voltage controller 0V to 1V step response with 86ms settleing time.}
    \end{subfigure}
    \begin{subfigure}{0.62\textwidth}
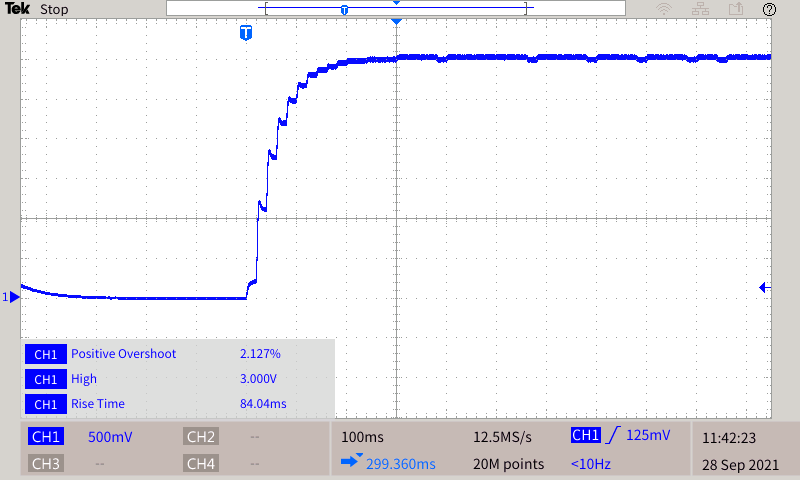
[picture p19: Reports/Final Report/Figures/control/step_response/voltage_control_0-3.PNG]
        
        \subcaption{Output voltage controller 0V to 3V step response with 84ms settleing time.}
    \end{subfigure}
    \begin{subfigure}{0.62\textwidth}
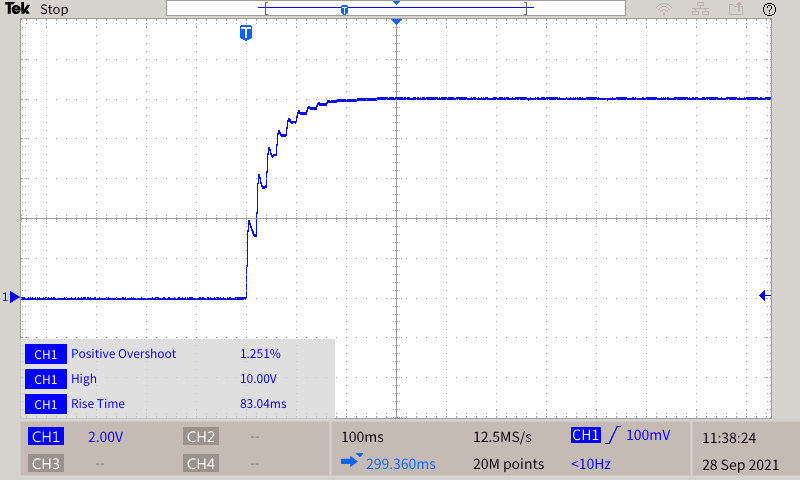
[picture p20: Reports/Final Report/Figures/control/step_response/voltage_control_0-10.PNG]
        
        \subcaption{Output voltage controller 0V to 10V step response with 83ms settleing time.}
    \end{subfigure}
    \caption{Output voltage control system step response, reacting to 1V, 3V and 10V output steps.}
\end{figure}

\section*{Output Voltage Control System Step Response Fall Time} \label{A:control_step_fall}
\begin{figure}[H]
    \centering
    \begin{subfigure}{0.7\textwidth}
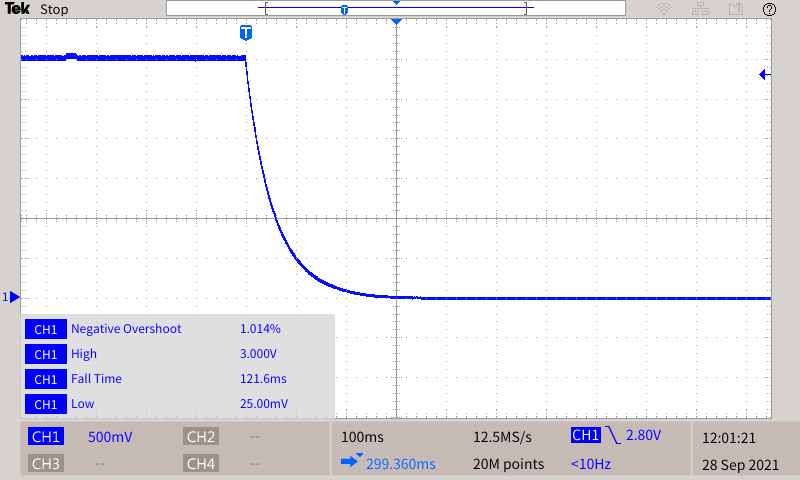
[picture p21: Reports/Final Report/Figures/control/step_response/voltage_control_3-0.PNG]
        
        \subcaption{Output voltage controller 3V to 0V step response with 121ms settleing time.}
    \end{subfigure}
    \begin{subfigure}{0.7\textwidth}
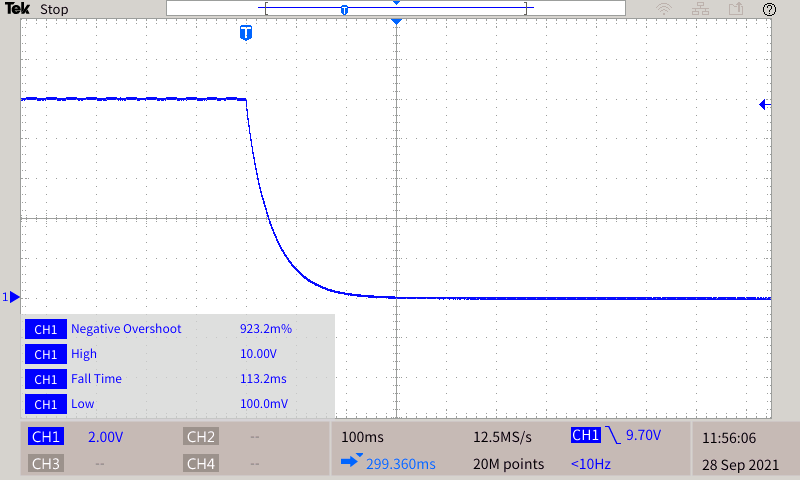
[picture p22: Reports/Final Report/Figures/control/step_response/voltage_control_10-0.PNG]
        
        \subcaption{Output voltage controller 10V to 0V step response with 113ms settleing time.}
    \end{subfigure}
    \caption{Output voltage control system step response, reacting to -3V and -10V output steps.}
\end{figure}
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

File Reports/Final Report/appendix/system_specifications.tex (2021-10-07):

\chapter{System Specification Derivation} \label{A:specs}

\section*{PWM Duty Cycle Resolution Calculations}

It has been specified that the output voltage error should be within $\pm 5\%$ of the output voltage. This allowable error will be smallest with the smallest output voltage, and will therefore define the smallest allowable duty cycle resolution.\\

Calculate the allowable output voltage error:
\begin{align}
    V_{error} &= 3 \cdot 0.05\\
    &=0.15V \nonumber
\end{align}

Calculate the minimum number of discrete voltage steps based on \Cref{E:V_out}
\begin{align}
    N_{steps} &= \frac{V_{in}}{V_{error}} = \frac{12}{0.15}\\
    &=80 \nonumber
\end{align}

Calculate the resolution in bits:
\begin{align}
    N_{bits} &= \log_2(N_{steps}) = \log_2(80)\\
    &=6.3 \approx 7 \nonumber
\end{align}

This gives a minimum duty cycle resolution of 7 bits, or 128 discrete steps.

\section*{Minimum \& Maximum Inductor Size Calculations}

It has been specified that the operating frequency of the buck converter should be between 1$k$Hz \& 100$k$Hz, with an inductor current ripple between 20\% \& 50\%. Based on these specifications, \Cref{E:delta_i} can be used to derive the minimum and maximum inductor sizes that the system will continue to function with. \\
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

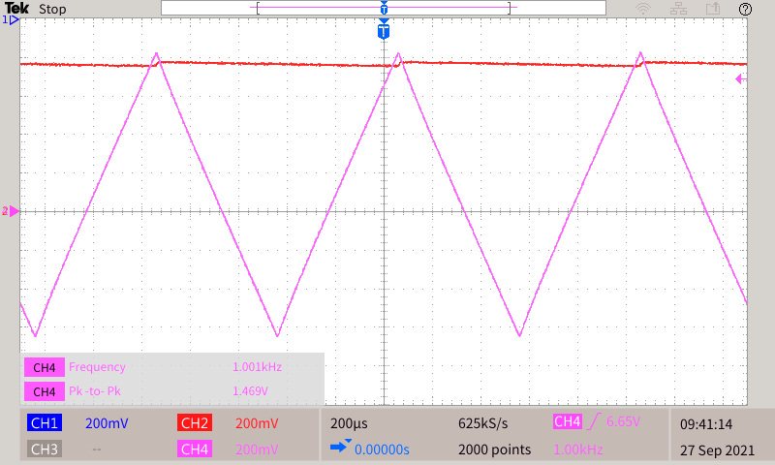
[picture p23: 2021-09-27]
Reports/Final Report/Figures/current_sense/peak_detector_original/1kHz_peak_detector.PNG

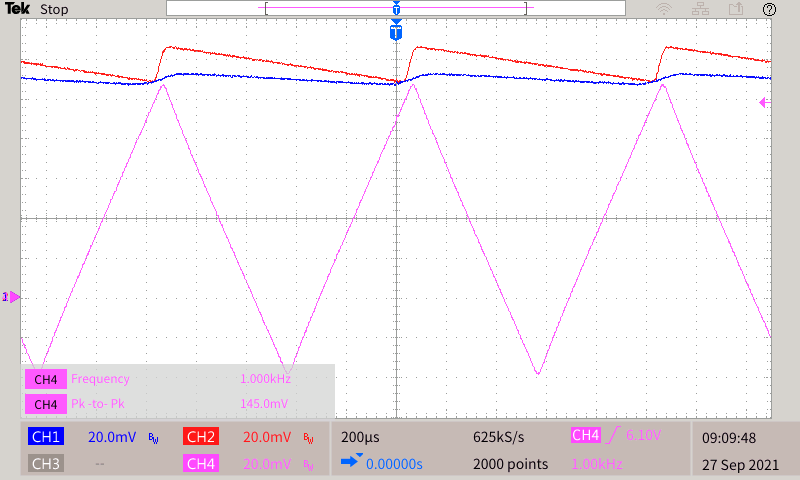
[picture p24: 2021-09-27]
Reports/Final Report/Figures/current_sense/peak_comparison_150mV/1kHz_150mV.PNG

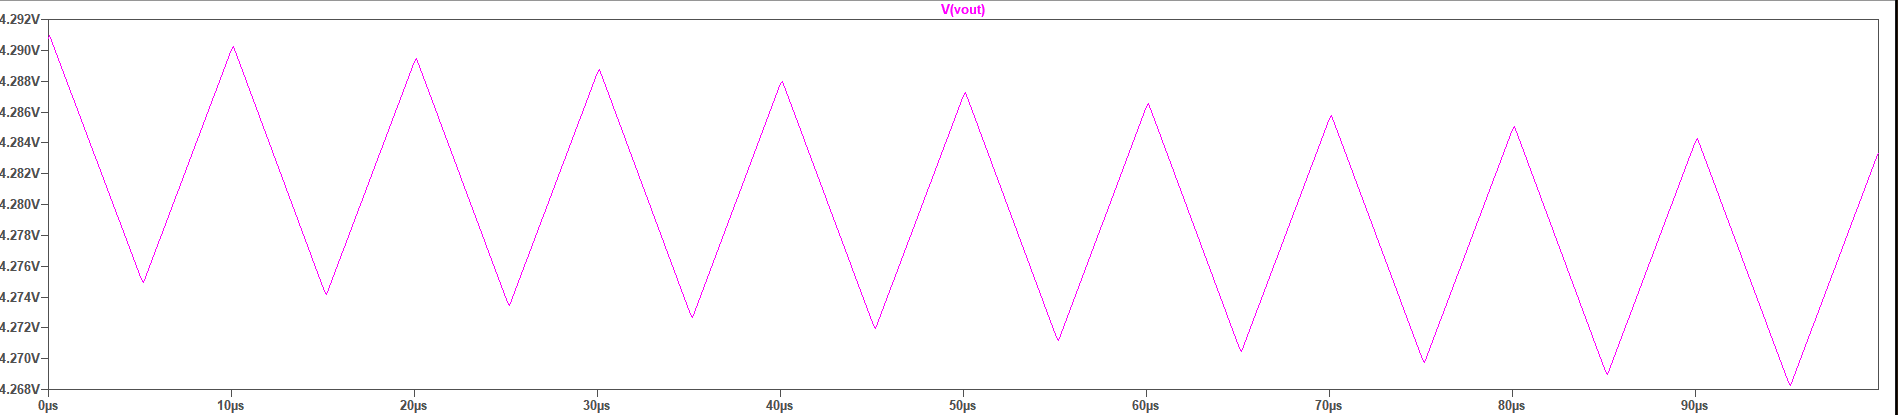
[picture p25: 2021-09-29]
Reports/Final Report/Figures/pwm/analog/analogue_PWM_ltspice_100k.png

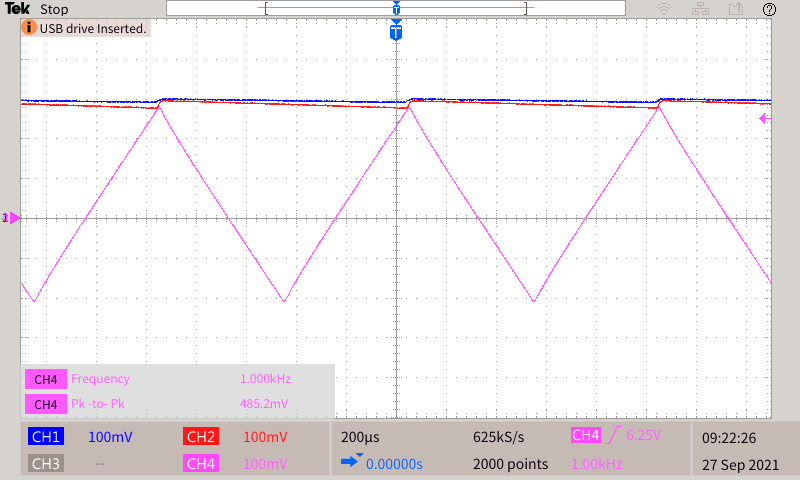
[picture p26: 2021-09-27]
Reports/Final Report/Figures/current_sense/peak_comparison_500mV/1kHz_500mV.PNG

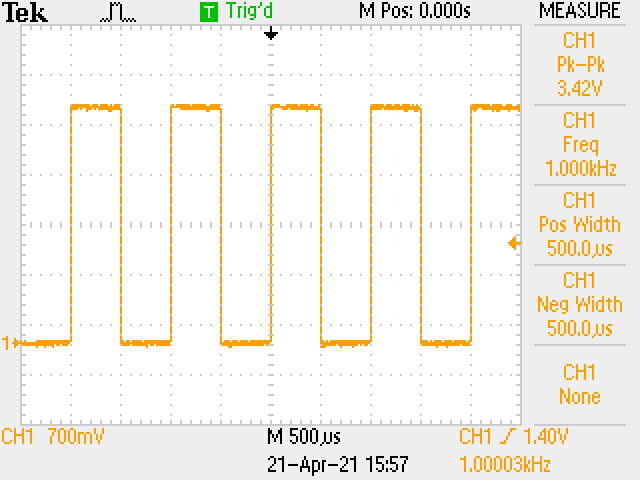
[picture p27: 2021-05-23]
Reports/Final Report/Figures/pwm/duty/1kHz_50Duty.JPG

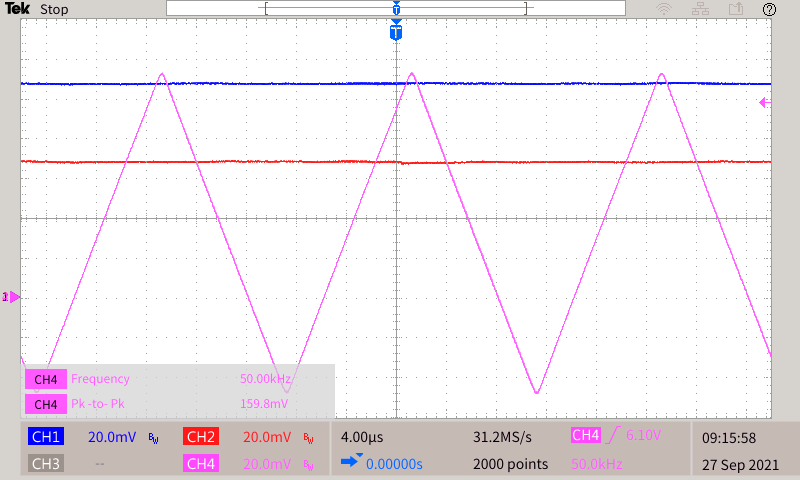
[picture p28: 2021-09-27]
Reports/Final Report/Figures/current_sense/peak_comparison_150mV/50kHz_150mV.PNG

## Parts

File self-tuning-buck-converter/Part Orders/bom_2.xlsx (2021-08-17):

Supplier | Supplier Part No. | Manufacturer Part Number | Qty | Description
Digi-key | MAX11646EUA+-ND | MAX11646EUA+ | 2 | IC ADC 10BIT SAR 8UMAX
Digi-key | MAX11644EUA+-ND | MAX11644EUA+ | 2 | IC ADC 12BIT SAR 8UMAX
Digi-key | 2156-MAX4173FESA-MA-ND | MAX4173FESA | 2 | IC CURR SENSE 1 CIRCUIT 8SOIC
Digi-key | LT1999IS8-10#PBF | LT1999IS8-10#PBF-ND | 2 | IC CURR SENSE 1 CIRCUIT 8SO
Digi-key | 273-PCS1206DR0500ETCT-ND | PCS1206DR0500ET | 4 | 1W 0.050 OHMS 0.5% 1206
Digi-key | WSLG-.06CT-ND | WSL2512R0600FEA | 4 | RES 0.06 OHM 1% 1W 2512
Digi-key | LTC4440EMS8E-5#PBF-ND | LTC4440EMS8E-5#PBF | 2 | IC GATE DRVR HIGH-SIDE 8MSOP
Digi-key | IR2125PBF-ND | IR2125PBF | 2 | IC GATE DRVR HIGH-SIDE 8DIP
Digi-key | LD1117V50 | 497-7311-5-ND | 2 | IC REG LINEAR 5V 800MA TO220AB
Digi-key | LM7322QMAX/NOPB | 296-46308-1-ND | 4 | IC OPAMP GP 2 CIRCUIT 8SOIC

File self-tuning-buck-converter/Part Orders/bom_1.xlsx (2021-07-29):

Supplier | Supplier Part No. | Manufacturer Part Number | Qty | Description
Digi-key | 296-53070-ND | INA253A1IPW | 2 | IC CURR SENSE 1 CIRCUIT 20TSSOP
Digi-key | A888AR-ND | LCQT-TSSOP20 | 2 | SOCKET ADAPTER TSSOP TO 20DIP
Digi-key | 1965-1000-ND | ESP32-DEVKITC-32D | 1 | EVAL BOARD FOR ESP-WROOM-32
Digi-key | 1528-1069-ND | 1210 | 1 | SMT ADAPTERS 6 PACK 14SOIC/TSSOP
Digi-key | 1528-1071-ND | 1212 | 2 | SMT ADAP 6 PACK 8SOIC/MSOP/TSSOP
Digi-key | MAX4020ESD+-ND | MAX4020ESD+ | 1 | IC OPAMP VFB 4 CIRCUIT 14SOIC
Digi-key | LMH6658MAX/NOPBCT-ND | LMH6658MAX/NOPB | 4 | IC OPAMP VFB 2 CIRCUIT 8SOIC
Digi-key | 296-17958-1-ND | OPA2830IDGKT | 2 | IC OPAMP VFB 2 CIRCUIT 8VSSOP
Digi-key | 3296W-101LF-ND | 3296W-1-101LF | 2 | TRIMMER 100 OHM 0.5W PC PIN TOP

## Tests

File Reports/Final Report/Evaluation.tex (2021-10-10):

\chapter{Evaluation}\label{C:evaluation}

This evaluation will evaluate the the success of the designed and implemented components in achieving their specified requirements as outlined in \Cref{C:design}.

\section{PWM Generation}\label{S:pwm_gen_eval}

It was specified in \Cref{S:pwm_gen_design} that a successful PWM generator subsystem must be capable of duty cycle variation with a resolution of 1.25\%, as specified by requirements 2 \& 3. The successful subsystem must also be capable of varying the switching frequency between 1kHz \& 100kHz with a resolution of 200Hz, as specified by requirements 4, 5, \& 6. 

\subsection*{Duty Cycle Variation}

The design discussed in \Cref{S:PWM_digital_design} outlines it's capabilities for selectable PWM duty cycle, with a resolution of 0.2\%. This precision was verified through visual inspection of oscilloscope measurements at various selected duty cycles, as well as numerically, plotting each targeted duty cycle against the systems output.\\

\subsection*{Switching Frequency Variation}

The design discussed in \Cref{S:PWM_digital_design} outlines it's capabilities for selectable PWM frequency between 1Hz, \& 125kHz. This frequency range was verified through visual inspection of oscilloscope measurements at various selected frequencies across the designed range. 

\begin{figure}[H]
    
    \centering
    \begin{subfigure}{0.45\textwidth}
        
        \subcaption{Output PWM frequency plotted against target frequency}
    \end{subfigure}
    \begin{subfigure}{0.45\textwidth}
        
        \subcaption{Output PWM frequency error as a percentage of target frequency}
    \end{subfigure}
    \caption{PWM frequency selection}
    \vspace{-10pt}
    \label{F:pwm_frequency_eval}
\end{figure}

It was also specified that the design would provide a PWM frequency selection error of no more than 200Hz for a provided frequency. This was evaluated numerically by plotting the target output frequency against the systems provided output, and can be seen in \Cref{F:pwm_frequency_eval} (a). To allow for easier visualisation of this error, it was calculated and plotted as a percentage of the target frequency \Cref{F:pwm_frequency_eval} (b). From this data, it was found that the maximum output frequency error of the system was 64Hz, or 0.064\% of the target output.\\

\subsection{PWM Generator Subsystem Evaluation}

The PWM generator subsystem was required to provides a duty cycle selection resolution of at least 1.25\%, and a frequency selection resolution of at least 200Hz, across the 1kHz to 100kHz range. The performed tests show that the implemented subsystem meets these specifications, providing a duty cycle selection resolution of 0.02\%, and a frequency selection resolution of 64Hz.  For the full range of PWM duty cycle and frequency test, measurements, and plots, refer too \Cref{A:digital_PWM}

\section{System State Sensing}\label{S:current_sense_eval}

It was specified in \Cref{S:sensing_design} that a successful state sensing subsystem will provide two sensing elements. The first, an voltage sensor capable of measuring voltages between 3V \& 10V with a resolution of 150mV, specified by requirements 2 \& 3. The second, an inductor current sensor capable of measuring average current and the peak current ripple with a resolution of 15mA, for frequencies between 1kHz \& 100kHz, as specified by requirement 4, 5, 6, \& 7.

\subsection{Output Voltage Sensing}

The design discussed in \Cref{S:v_sense_design} outlines it's capability of measuring a DC voltage between 3V \& 10V, with a measurement resolution of 2.5mV. This measurement precision was evaluated by comparing a selection of known input voltages between 3V and 10V to their measured outputs from the implemented design.\\

From this testing it was identified that a final precision of 10mV was achieved by the design, with signal noise from the ADC presenting as the main design limitation. Although the evaluated resolution of the design does not meet it's designed specification, it still provides a resolution 15 times greater than required.

\subsection{Inductor Current Sensing}

\subsection*{Average Inductor Current}

The design discussed in \Cref{S:avg_current_design} outlines it's capability to provide an average current measurement for frequencies between 1kHz and 100kHz, with a resolution of 244$\mu$A. The frequency range and resolution were evaluated by comparing a selection of known input voltages between 100mV and 3V to their measured outputs from the implemented design. This was then repeated for frequencies of 1kHz, 50kHz, and 100kHz.\\ 

From this testing it was identified that a final precision of 3.5mV was achieved by the design across all frequencies, with similar design limitations as the output voltage sensing. This provided a final average current measurement resolution of 1.1mA.

\subsection*{Peak Inductor Current}

The design discussed in \Cref{S:current_sense_sample_and_hold_design} outlines it's capability to provide a peak current measurement for frequencies between 1kHz and 100kHz, with a resolution of 15mA. As discussed in \Cref{S:peak_current_implementation}, the operation of the original design did not approach the resolution suggested by the simulations, and as such a redesign was undertaken to improve this. 

The precision and functional frequency range of both the initial and final designs were evaluated and compared. In this evaluation, a known peak to peak voltage was input to the design, and compared to it's output DC voltage for a range of frequencies from 1kHz to 100kHz. This was then repeated for input voltages of 150mV, 500mV, and 1500mV, spanning the entire possible input range from the system. An oscilloscope screenshot of this testing for an input of 500mV, and frequencies of 10kHz and 100kHz can be seen in \Cref{F:peak_detect_scope}.

\begin{figure}[H]
    \centering
    \begin{subfigure}{0.45\textwidth}
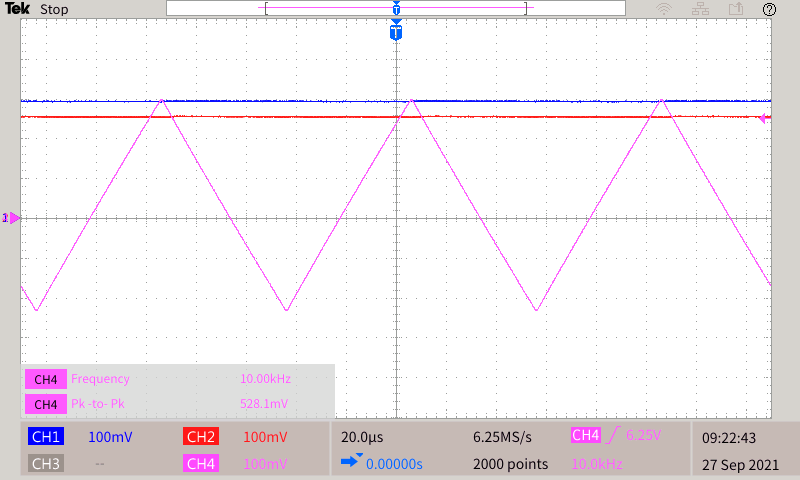
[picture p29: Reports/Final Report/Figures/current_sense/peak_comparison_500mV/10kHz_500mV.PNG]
        
        \subcaption{Initial (Red) \& final (Blue) peak detetor outputs for a 10$kHz$ 500mV triangle input}
    \end{subfigure}
    \begin{subfigure}{0.45\textwidth}
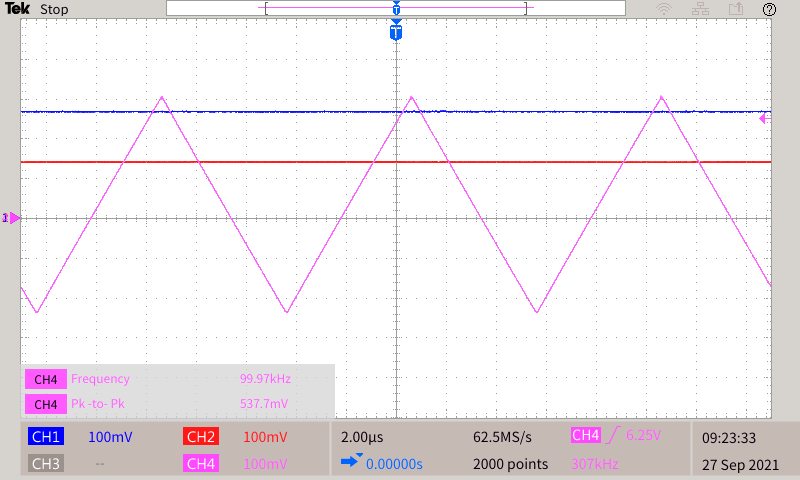
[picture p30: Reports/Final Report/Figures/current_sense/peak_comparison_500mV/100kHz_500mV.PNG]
        
        \subcaption{Initial (Red) \& final (Blue) peak detetor outputs for a 100$kHz$ 500mV triangle input}
    \end{subfigure}
    \caption{Initial and final peak detector design }
    \vspace{-10pt}
    \label{F:peak_detect_scope}
\end{figure}

From this testing, plots comparing the total error of the two designs as a percentage of the input peak to peak signal were generated, and can be seen in \Cref{F:peak_detect_eval}. From these plots it can be observed that there is an increase in the total error for both designs as the input frequency increases, and a decrease in the total error as the input ripple increases. It can also clearly be seen that the final design provides substantially lower error for all input frequencies and peak to peak values, with a largest recorded error of 8.9\% when operating at the minimum input ripple and maximum frequency.   

\begin{figure}[H]
    \centering
    \begin{subfigure}{0.45\textwidth}
        
        \subcaption{Initial design peak current sensing error as a percentage of actual peak current against frequency}
    \end{subfigure}
    \begin{subfigure}{0.45\textwidth}
        
        \subcaption{Final design peak current sensing error as a percentage of actual peak current against frequency}
    \end{subfigure}
    \caption{Initial and final peak current sensing design, percentage of actual peak current against frequency}
    \vspace{-10pt}
    \label{F:peak_detect_eval}
\end{figure}

From this testing it was identified that a worst case precision of 13.35mV was achieved by the design with an 100kHz input of 150mV peak to peak. After conversion, this provided a worst case peak current measurement resolution of 4.45mA. 

\subsection{State Sensing Subsystem Evaluation}

The state sensing subsystem was required to provide measurements of the buck converters output voltage to a resolution of 150mV, as well as inductor average current and peak current ripple measurements across the 1kHz to 100kHz range to a resolution of 15mA. The performed tests show that the implemented subsystem meets these specifications. This subsystem provides an output voltage measurement resolution of 10mV, an average current sensing resolution of 1.1mA, and a worst case peak ripple sensing resolution of 4.45mA. For the full range of testing, measurements, and plots, refer too \Cref{A:peak_detector}.

\section{Control System}\label{S:control_eval}

It was specified in \Cref{S:control_design} that a successful control subsystem will ensure a steady state error of no more than $\pm$5\% across the output range of 3V to 10V, as specified by requirement 3. It can be noted that the success of this control subsystem relies heavily on the designed specifications of the PWM generator subsystem to implement the selected duty cycle and frequency, as well as the state sensing subsystem to provide reliable and accurate feedback. 

\subsection*{Output Voltage Control}

The design discussed in \Cref{S:output_control_design} outlines it's capability to provide an output steady state error of 23mV, or $\pm$0.78\%. This implemented controller was evaluated using a number of methods, characterising the subsystems steady state error and step response across the across the 3V to 10V output range, as well as the controllers supply change rejection.\\

The step response of the system was evaluated by selecting a system output of 0V DC, and then providing supplying an output target voltage step between 1V DC and 10V DC. From these tests it was observed that there was no output overshoot from the control system, and a consistent settling time of 84ms was observed for all step input values. Oscilloscope screenshots of this controller response can be seen in \Cref{F:control_step}. 

It was also observed from these tests that the designed steady state error of $\pm$0.78\% was achieved, with small output fluctuations of 23mV noticeable in \Cref{F:control_step} (a).

\begin{figure}[H]
    \centering
    \begin{subfigure}{0.45\textwidth}
        
        \subcaption{Buck converter output voltage controller 3V step response}
    \end{subfigure}
    \begin{subfigure}{0.45\textwidth}
        
        \subcaption{Buck converter output voltage controller 10V step response}
    \end{subfigure}
    \caption{Buck converter output voltage controller step response for full output voltage range}
    \vspace{-10pt}
    \label{F:control_step}
\end{figure}

The controller response to supply voltage changes was evaluated by allowing the controller to achieve a steady state, and then varying the input supply between values of 6V and 16V respectively. From these tests it was observed that the controller was consistently able to return the output to it's steady state within a period of 250ms. It was also observed that the designed converter was capable of providing any specified output between 1V and 10V across the full tested supply range, so long as the requested output was at least 500mV below the current supply.

\begin{figure}[H]
    \centering
    \begin{subfigure}{0.45\textwidth}
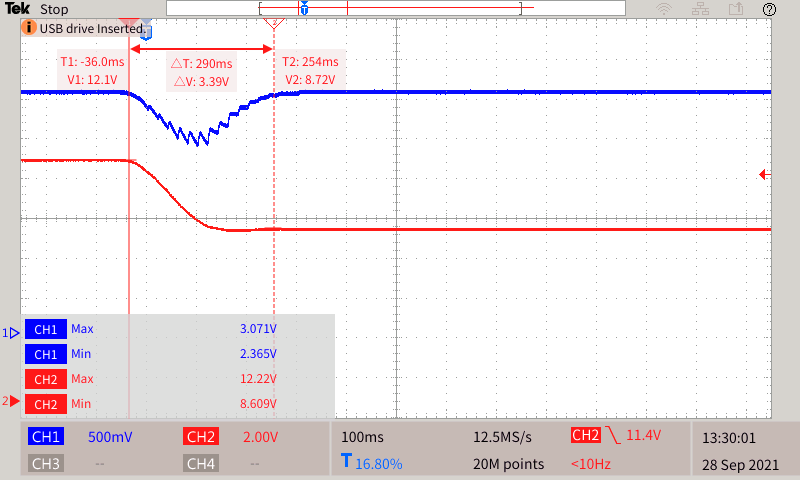
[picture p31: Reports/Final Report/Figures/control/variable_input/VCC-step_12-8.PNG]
        
        \subcaption{Buck converter output voltage controller response to -4V supply transition}
    \end{subfigure}
    \begin{subfigure}{0.45\textwidth}
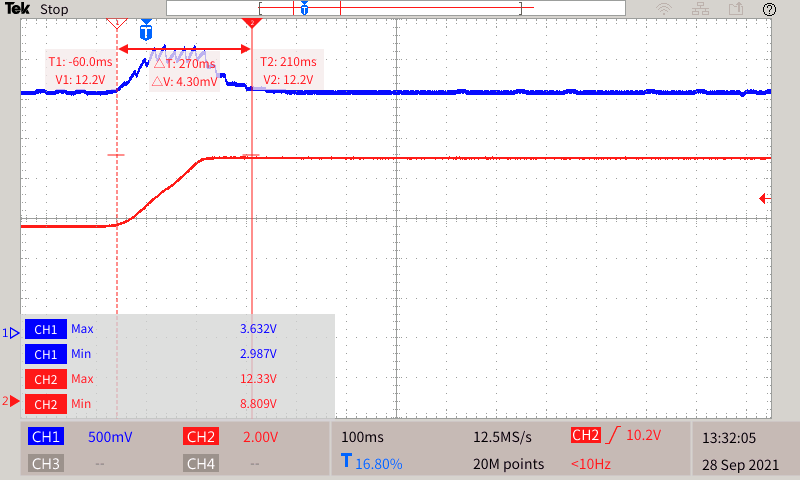
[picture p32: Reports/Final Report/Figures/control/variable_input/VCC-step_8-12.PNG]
        
        \subcaption{Buck converter output voltage controller response to 4V supply transition}
    \end{subfigure}
    \caption{Buck converter output voltage controller response to varied input supply}
    \vspace{-10pt}
    \label{F:Control_variable_input}
\end{figure}

\subsection{Control Subsystem Evaluation}

The control subsystem was required to ensure that the buck converters output voltage steady state error was no larger than $\pm$5\% across the output range of 3V to 10V. The performed tests show that the implemented sub system meets these specifications. This subsystem has been proven to provide an output voltage steady state error of $\pm$0.78\% across it's full output range, while also providing additional functionality of input supply rejection. This shifts the operating input supply range of all subsystems within this project to between 8V and 16V, as opposed to the static 12V initially specified in requirement 1. 

For the full range of testing, measurements, and plots, refer too \Cref{A:control}.

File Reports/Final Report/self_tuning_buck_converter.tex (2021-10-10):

\documentclass[11pt, a4paper, oneside]{report}
% \usepackage[left=2cm, right=2cm, top=1.5cm, bottom=1.5cm]{geometry}

\usepackage{float} % lets you have non-floating floats
\usepackage{url} % for typesetting urls

\usepackage{amsmath}

\usepackage{hyperref}
\usepackage{cleveref}

\usepackage{wrapfig}
\usepackage{subcaption}
\usepackage{graphicx}
\usepackage[table,xcdraw]{xcolor}

\usepackage{pdfpages}

\definecolor{mGreen}{rgb}{0,0.6,0}
\definecolor{mGray}{rgb}{0.5,0.5,0.5}
\definecolor{mPurple}{rgb}{0.58,0,0.82}
\definecolor{backgroundColour}{rgb}{0.95,0.95,0.92}

% Include C code
\usepackage{listings}
\lstset{
  backgroundcolor=\color{backgroundColour},   
  commentstyle=\color{mGreen},
  keywordstyle=\color{magenta},
  numberstyle=\tiny\color{mGray},
  stringstyle=\color{mPurple},
  basicstyle=\ttfamily\small,
  columns=flexible,
  keepspaces=true,
  language=C,                     % choose the language of the code
  numbers=left,                   % where to put the line-numbers
  stepnumber=1,                   % the step between two line-numbers.        
  numbersep=5pt,                  % how far the line-numbers are from the code
  backgroundcolor=\color{white},  % choose the background color. You must add \usepackage{color}
  showspaces=false,               % show spaces adding particular underscores
  showstringspaces=false,         % underline spaces within strings
  showtabs=false,                 % show tabs within strings adding particular underscores
  tabsize=2,                      % sets default tabsize to 2 spaces
  captionpos=b,                   % sets the caption-position to bottom
  breaklines=true,                % sets automatic line breaking
  breakatwhitespace=true,         % sets if automatic breaks should only happen at whitespace
  title=\lstname,                 % show the filename of files included with \lstinputlisting;
  emph={%  
    uint8_t, uint16_t, uint32_t, TaskHandle_t, QueueHandle_t, esp_adc, esp_err_t, PIDController, ledc_timer_config_t, ledc_channel_config_t, TickType_t%
    },emphstyle=\color{magenta},
}

% Make the title spacing smaller
% \usepackage{titlesec}
% \titleformat{\chapter}[hang] 
% {\normalfont\huge\bfseries}{\chaptertitlename\ \thechapter:}{1em}{} 
% \titlespacing*{\chapter}{0pt}{-50pt}{40pt}

\newcommand{\todo}[1]{\textcolor{red}{#1}}

\hypersetup{
    colorlinks=true,
    linkcolor=black,
    filecolor=black,
    citecolor=black,
    urlcolor=black,
}

\usepackage[image,ecs]{vuwproject}

% \renewcommand{\thesection}{\arabic{section}}
% \setlength{\parskip}{\baselineskip}
\setlength{\parindent}{0pt}

\usepackage{titlesec}
\titleformat{\chapter}[hang] 
{\normalfont\huge\bfseries}{\chaptertitlename\ \thechapter:}{1em}{} 

%
%  We don't want figures to float so we define
%
\newfloat{fig}{thp}{lof}[chapter]
\floatname{fig}{Figure}
\graphicspath{ {./Figures/} }

%% These are standard LaTeX definitions for the document
%%                            
\title{Self Tuning Buck Converter}
\author{Niels Clayton}

\supervisors{Daniel Burmester and Ramesh Rayudu}
\otherdegree{Bachelor of Engineering with Honours}

\date{}

\begin{document}

\frontmatter

%%%%%%%%%%%%%%%%%%%%%%%%%%%%%%%%%%%%%%%%%%%%%%%%%%%%%%%

\begin{abstract}

    Switch-mode power supplies are commonly used in a wide variety of consumer and professional appliances to transform DC voltages with high efficiency. One such switch-mode supply is the buck converter, which steps down a DC voltage. The current buck converter design process requires that a specific output filter be designed around the switching frequency of the converter, the required output voltage, and the desired inductor ripple. This filter design process often results in the selection of non-standard components that are difficult to purchase or manufacture, increasing costs and leading to design compromises. This project will develop a platform that allows for observation and control of the inductor current ripple by modulating the switching frequency of the converter. This will allow engineers to design buck converters directly for the specified inductor current ripple their application can tolerate, eliminating the issues of designing this output filter.

\end{abstract}

%%%%%%%%%%%%%%%%%%%%%%%%%%%%%%%%%%%%%%%%%%%%%%%%%%%%%%%

\maketitle

% \setcounter{tocdepth}{1}
\tableofcontents
% \listoffigures
% \listoftables

%%%%%%%%%%%%%%%%%%%%%%%%%%%%%%%%%%%%%%%%%%%%%%%%%%%%%%%

\mainmatter

%%%%%%%%%%%%%%%%%%%%%%%%%%%%%%%%%%%%%%%%%%%%%%%%%%%%%%%

% individual chapters included here
\include{introduction}
\include{background}
\include{Design}
\include{Implementation}
\include{Evaluation}
\include{conclusion}

%%%%%%%%%%%%%%%%%%%%%%%%%%%%%%%%%%%%%%%%%%%%%%%%%%%%%%%

\backmatter

%%%%%%%%%%%%%%%%%%%%%%%%%%%%%%%%%%%%%%%%%%%%%%%%%%%%%%%

\let\OLDthebibliography\thebibliography
\renewcommand\thebibliography[1]{
  \OLDthebibliography{#1}
  \setlength{\parskip}{0pt}
}

\bibliographystyle{ieeetr}
\bibliography{../../Literature/bibliography}

% Remove the appendix from the table of contents
\addtocontents{toc}{\protect\setcounter{tocdepth}{1}}
\input{appendix}

\end{document}

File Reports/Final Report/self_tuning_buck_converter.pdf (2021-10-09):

# VICTORIA UNIVERSITY OF WELLINGTON

Te Whare Wananga o te ¯ | Upoko o te Ika a M ¯ | aui ¯

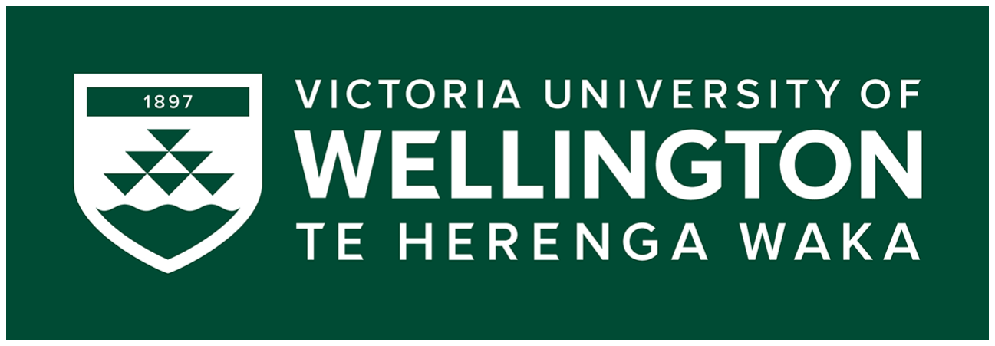
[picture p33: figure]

# School of Engineering and Computer Science

Te Kura Matai P ¯ | ukaha, P ¯ | urorohiko ¯

PO Box 600
Wellington
New Zealand

Tel: +64 4 463 5341
Fax: +64 4 463 5045
Internet: office@ecs.vuw.ac.nz

## Self Tuning Buck Converter

| Niels Clayton

Supervisors: Daniel Burmester and Ramesh Rayudu

Submitted in partial fulfilment of the requirements for Bachelor of Engineering with Honours.

Abstract

Switch-mode power supplies are commonly used in a wide variety of consumer and professional appliances to transform DC voltages with high efficiency. One such switch-mode supply is the buck converter, which steps down a DC voltage. The current buck converter design process requires that a specific output filter be designed around the switching frequency of the converter, the required output voltage, and the desired inductor ripple. This filter design process often results in the selection of non-standard components that are difficult to purchase or manufacture, increasing costs and leading to design compromises. This project will develop a platform that allows for observation and control of the inductor current ripple by modulating the switching frequency of the converter. This will allow engineers to design buck converters directly for the specified inductor current ripple their application can tolerate, eliminating the issues of designing this output filter.

# Contents

1 Introduction | 1
2 Background | 3
3 Design | 8
4 Implementation | 15
5 Evaluation | 19
6 Conclusions & Future Work | 20

i

# Chapter 1: Introduction

Historically power distribution has been primarily in the form of AC (Alternating current). This is credited to the fact that AC power is simple to produce, and made it easy to step up and down the voltages efficiently with transformers [1]. However, with the invention of solid-state electronics such as the metal–oxide–semiconductor field-effect transistor or MOSFET for short, it has become possible to efficiently step up and step down direct current (DC) voltages. This has been achieved by the invention of the switch-mode power supply, which has facilitated the continued reduction of size and increase in efficiency of electronics [2].
Today, switch-mode power supplies can be found in a wide variety of consumer and professional electronics, with some examples being laptops, phones, and any form of DC charger. Their widespread usage when compared to other DC-DC converters such as linear regulators can be attributed to their far greater efficiency. One such switch-mode power supply is the buck converter, which will step down a DC input voltage to a lower DC output voltage.

### 1.1 Project Motivation

Although buck converters are a widespread technology, they are not without their limitations and drawbacks. The current buck converter design process requires that a specific output filter be designed around the switching frequency of the converter, and the desired inductor ripple current. This filter design process will often result in the converter requiring discrete passive components that are non-standard and hard to source. This will usually result in the designer having to make compromises in their design for either the cost or the performance of the converter.
Another drawback of this design process is the static nature of both the filter and the switching components once they have been selected. This results in the buck converters desired inductor current ripple only being achieved at a very specific designed output voltage or load. This means that with current buck converter designs varying the desired output voltage or varying the output load will cause the inductor current ripple to vary. This is an issue, as very few loads are static and will not change during their operation.

### 1.2 Project Goals

The goal of this project is to develop a testing platform through which the effects of variable buck converter switching frequency on inductor current ripple can be observed and controlled. The aim of this is to eliminate the need to design the output stage of the buck converter by implementing a control system to maintain a specified inductor current ripple, and output voltage.

To achieve this goal, a proof of concept buck converter will be designed to operate as the testing platform. This converter will require a variable frequency pulse width modulated

(PWM) signal generator, and inductor current ripple sensing. This will allow for direct manipulation and control of inductor current ripple. The converter will also need to implement the full functionality of existing buck converter designs, including controlled output voltage regulation.
It is also important to note that as this project aims to produce a testing platform to be used as a proof of concept, there will be continued work undertaken after the projects conclusion. Because of this, it is important that the design and implementation undertaken in this project considers the ease of use and future expansion of the project.

The following list of specifications outlines the requirements the designed test platform will meet:

1. Operate with a 12V DC input supply voltage
2. Provide a selectable DC output voltage between 3V and 10V
3. Provide an output voltage precision of at least ±5% of the targeted output voltage
4. Provide a selectable inductor current ripple between 20% and 50% of the total output current
5. Provide a variable converter switching frequency between 1kHz and 100kHz
6. Provide an inductor current ripple precision of at least ±5% of the target inductor current ripple
7. Operate with variable load sizes between 10Ω and 20 Ω

# Chapter 2: Background

A literature research was performed to inform design decision made in this project, and to evaluate any existing research. This chapter will discuss buck converter design factors and topologies, as well as the various different methods of PWM generation, current sensing, and control implementation. In performing this literature research, we searched Google Scholar, Engineering Village, and Te Waharoa to find designs that utilised variable frequency PWM.
These searches returned no research relevant to the designs of this project, with the only related work focusing on the electromagnetic noise reduction using randomised frequency modulation [3, 4]. Because of this, research was instead performed to inform the design of the buck converter and the generation of PWM signals.

### 2.1 Pulse Width Modulated Signal Generation

Pulse width modulation (PWM) is a digital signal generation technique shown in Figure 2.1a, in which the Period T of the signal is held constant, while the ratio of its logic high period Ton to logic low period To f f is modulated. This ratio of high period to the low period is referred to as the duty cycle of the PWM signal and is often expressed as a percentage, this can be seen in Figure 2.1b.

PWM signals are used in a wide variety of applications for both digital and analogue electronics. PWM is often used to generate analogue signals from digital components by varying the average voltage of the digital PWM signal over time [5]. PWM is also used to control the switching elements contained within switch mode power supplies using this same principle, as discussed in Section 2.2. With regard to this project, we will be looking to generate a PWM signal that can be modulated in both duty cycle and frequency.

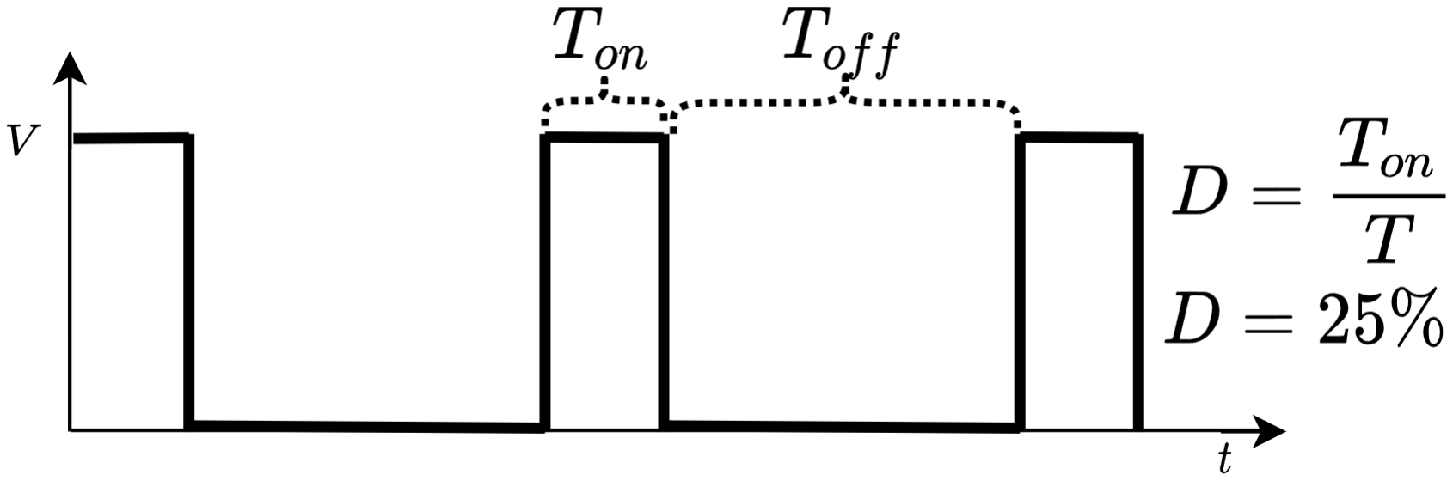
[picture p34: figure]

(a) Pulse width modulated signal | (b) Duty cycle calculation

Figure 2.1: Pulse width modulated signal characteristics

### 2.1.1 Analogue PWM Signal Generation

Designing a PWM signal generator using analogue components has three distinct stages required to generate the signal. These stages can be seen in Figure 2.2, and include clock generation, triangle wave generation, and signal comparator stages [6].

The clock generation stage generates a square wave clock signal at a set frequency. This is usually done using a quartz crystal oscillator, or another form of resonating oscillator circuit. The triangle wave generating state must take the clock signal from the previous stage, and produce a triangle wave of the same frequency. This stage is most often done using a standard op-amp integrating circuit with unity gain at the resonating frequency of the clock source. The final signal comparator stage will convert this triangle wave into a PWM signal. Using a comparator, a reference voltage can be applied to the non-inverting input, and then the triangle wave can be applied to the inverting input. This will produce a pulse train with the same frequency as the clock source, where the period of Ton and To f f is set by the reference voltage.

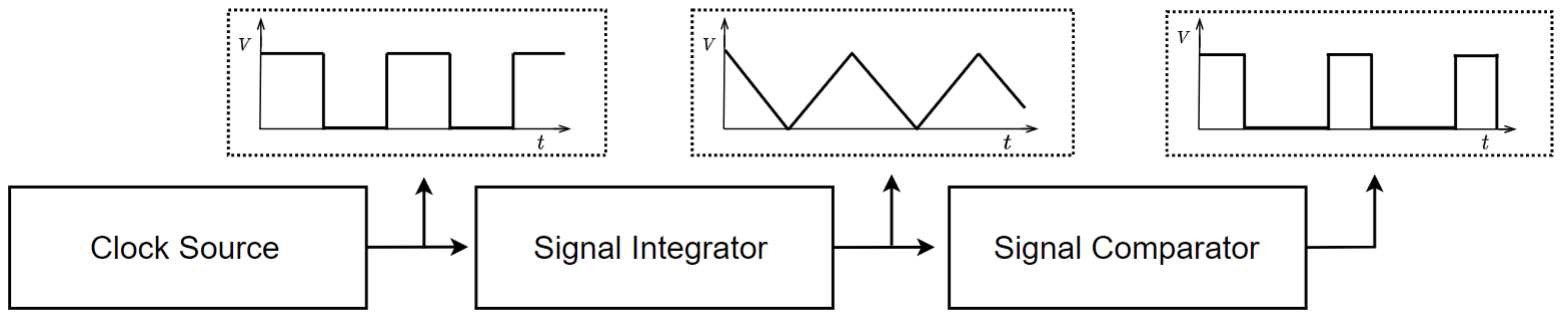
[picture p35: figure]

Figure 2.2: Stages of analogue PWM generation

### 2.1.2 Digital PWM Signal Generation

Designing a PWM signal generator with digital components is less complex than the method described in Section 2.1.1, and can be done using either a microcontroller or a Field Programmable Gate Array (FPGA). By using an internal timing register that is continually incrementing at a known period we can set a period for our PWM. It is possible to vary the period of the PWM by simply increasing or decreasing the timing registers clock. Next, by toggling a digital I/O when a compare variable is equal to the current value of the timer, we are able to generate a PWM signal with a variable duty cycle [7]. This timing architecture can be simply implemented within an FPGA, but it can also commonly be found within the hardware of most microcontrollers.It should be noted however, that the range of achievable frequencies and duty cycle accuracy will be dependant on an individual microcontrollers clock speed and internal register sizes.

### 2.2 Buck Converters

The buck converters is a variant of a switch mode power supply that steps down a DC input voltage to a DC output voltage. They are commonly used in a wide variety of consumer and professional appliances such as laptops, phones, and chargers due to their high efficiency compared to other DC-to-DC step down converters such as linear regulators [8].

The basic operational components of a buck converter can be seen below in Figure 2.3. From this we see that a buck converter has three main elements, the input voltage source, two switching components, and an output filter across the load. In the case of Figure 2.3, the first switching component is an actively controlled switch such as a MOSFET or transistor, and the second a passive switching diode. This configuration of an active and a passive switch is known as the non-synchronous buck converter topology, if the passive diode were to be replaced with a second active switch the topology would be considered synchronous. Although both topologies function under the same fundamental principles, the non-synchronous topology is easier to implement with the drawback of higher losses and therefore lower efficiency.

It can also be seen from Figure 2.3 that a buck converter has two operating states that are controlled through the activation of these switching components. By toggling these switching components at high speed though the use of PWM, we can control the current flowing through the inductor of the output filter. By controlling this current we are also able to directly control the current through, and voltage across the output load of the converter. Using this, buck converters will often have a feedback control system in their design to be able to actively control and regulate the output voltage during usage. This controller will vary the duty cycle of the the switching PWM signal, thereby varying the output voltage of the buck converter as shown in Equation (2.1).

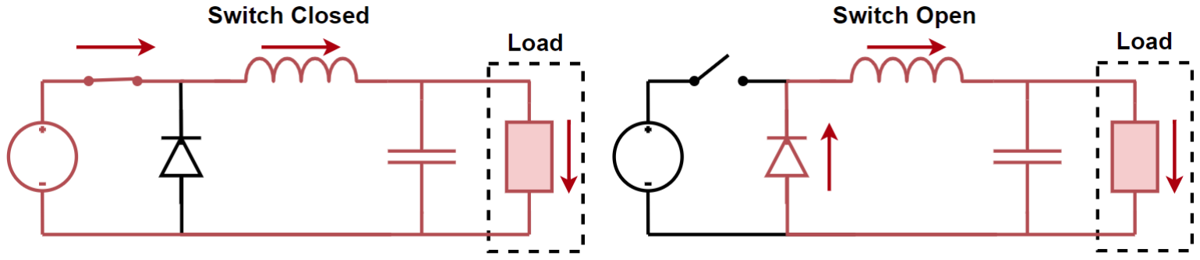
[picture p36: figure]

Figure 2.3: Operating states of a buck converter

### 2.2.1 Buck Converter Design

The design of a common buck converter has two primary considerations, the output voltage of the converter V0, and the inductor current ripple of the converter ∆iL. These considerations can be specified by designing the buck converter using Equation (2.1) & Equation (2.2) [9, 10].

When designing a buck converter the first design specification that must be met is the output voltage. In Equation (2.1) the output voltage can be directly related to the input voltage Vin and the switching duty cycle D. Using this equation it is possible to directly set the output voltage of the buck converter by varying this duty cycle.

Vo = D · Vin | (2.1)

Once the output voltage has been specified, the inductor current ripple can be calculated and specified with Equation (2.2). This equation allows for the inductor current ripple to be
directly related to the inductor size L, and the PWM switching frequency fs | . This allows the
the specification of the inductor current ripple through the varying of these two values.

∆iL =

Vo · (1 − D) L · fs | (2.2)

These two equations will be used to inform the designs and specifications of this project, and will be discussed in detail in Section 3.1.

### 2.3 Current Sensing

Current sensors are transducers that converter an input current to an easily measured output voltage that is proportional to the current through the sensor. Current sensors operate on one of two principles, Ohm’s law, Faraday’s and Ampere’s law [11]. Ohm’s law describes how when current flows through a resistive element a voltage drop will occur. Sensors operating under this principle will measure the voltage drop across a known resistance, and are referred too as direct sensors as they directly effect the circuit. Faraday’s and Ampere’s law describes how a changing electric flux will induce a changing magnetic field, and a changing magnetic field will induce a changing magnetic flux. Sensors operating under this principle will use the magnetic field induced by the current through the sensor to produce a voltage proportional to that current, and are referred to as indirect sensors as they make no direct contact with the circuit being sensed.

### 2.3.1 Current Sense Amplification

Current sense voltage amplification sensors are a form of direct sensor, working on the principle of Ohm’s law I = V
R

. By sensing the voltage dropped across a known value resistive element (Often called the current shunt), it is possible to calculate the current that is flowing through the element. This form of current sensing is very simple to implement in theory, however it has the effect of altering the system being sensed by adding a resistive load, and thereby increasing the losses of the system.
To mitigate the effects of this sensing on a circuit, a smaller resistive load can be used. However, this will also decrease the measurable voltage across the load, and therefore decrease the precision of a taken measurement. Because of this, shunt based current sensors are often paired with an operational amplifier of known gain. This combination allows for accurate amplification of the shunts voltage drop, increasing the precision of measurements, and allowing for drastically smaller shunt resistors.

### 2.3.2 Hall Effect Sensors

Hall effect sensors are a form of indirect sensor, working on the principles of Faraday’s and Ampere’s law as discussed above. They function by measuring the magnetic flux density, meaning that they are commonly used to sense the presence of a magnets or magnetic fields. However since a current flowing though a wire will produce a magnetic flux, they can also be used to measure current flow.
Due to this operation, they are able to sense a current without contacting or altering the circuit. This means that they are commonly used in the measurement of high voltage or high current circuits, as they will remain completely isolated from the circuit being sensed. This provides large safety advantages, eliminates sensing power losses, and can often decrease the complexity of the sensing circuit.
Hall affect sensors do however suffer from a lack of precision. Due to their operation, their measurements will constantly be offset by any ambient magnetic flux within the surrounding environment. This means that they are not commonly used for the sensing of small signal currents, as the noise floor of the Earth’s own magnetic field can often be larger than the signal being sensed [12].

### 2.4 Control Systems

Control systems are integral to the operation of any system for which you wish to achieve a desired outcome. In their simplest, a control systems has the purpose of obtaining a desired output from a system, with a desired performance, when a given input is provided.

There are two main topologies of control system, open loop and closed loop. An open loop control system requires no feedback of the output, and therefore no sensing. Because of this, open loop controllers are often very easy and fast to implement within a system because of this, however they have no knowledge of the systems state and are therefore unable to correct for errors such as external disturbances.
On the other hand, closed loop controllers require feedback from the current output of a system, and therefore will require sensing to be implemented. This added sensing requirement will add complexity to the system, however a closed loop controller provides the ability to compensate for errors in the systems output.

The performance of a specific control system is often discussed in terms of it’s steady state settling time, and it’s stead state error. The steady state settling time of a controller describes the time it takes for a controller to reach it’s final value (‘steady state’) when provided with a given input. The slower the steady settling time of a controller, the slower it will react to a given input, and vice versa. The steady state error of a controller describes the error between the desired output and the final output of the system once it’s steady state has been achieved.

# Chapter 3: Design

The design processes outlined within this report will draw heavily on the background research discussed in Chapter 2. These designs aim to effectively implement the outlined system requirements discussed by Section 1.2 in a robust and repeatable manner.

### 3.1 System Specifications and Architecture

Section 1.2 outlines a list of specifications that this project must achieve. For each item in this list, design specifications can be derived to ensure that our designs are capable of meeting the outlined requirements. This list of specifications will also help to shape the architectural approach taken on this project.

Requirement 1: Operate with a 12V DC input supply voltage

To meet this requirement, the buck converter must be designed to be 12V DC compatible. this will require all designed hardware, including additional digital and analog circuity to be capable of operating with this supply.

Requirement 2: Provide a selectable DC output voltage between 3V and 10V

To meet this requirement, the designed buck converter must have the ability to change the duty cycle of it’s PWM switching signal. This will allow for variation of the output voltage based on Equation (2.1).

Requirement 3: Provide an output voltage precision of at least ±5% of the targeted output voltage

To meet this requirement, the designed buck converter must have a control system to regulate the output voltage. To achieve a steady state error of less than ±5%, feedback should be implemented, requiring output voltage sensing. We can also specify that a minimum duty cycle resolution of 1.25% will be required to achieve this. For the derivation of these values, please see ??.

Requirement 4: Provide a selectable inductor current ripple between 20% and 50% of the total output current

To meet this requirement, the designed buck converter must have the ability to change the frequency of it’s PWM switching signal. This will allow for variation of the inductor peak to peak current ripple based on equation Equation (2.2).

Requirement 5: Provide a variable converter switching frequency between 1kHz and 100kHz

To meet this requirement, the PWM switching frequency must be selectable across the specified range. This, in tandem with requirement 4, allow for the specification of the inductor range for which these requirements can be met. For the derivation of these values, please see ??.

Requirement 6: Provide an inductor current ripple precision of at least ±5% of the target inductor current ripple

To meet this requirement, the designed buck converter must have a control system to regulate the inductor current ripple. To achieve a steady state error of ±5%, feedback should be implemented, requiring inductor current ripple sensing. We can also specify that a minimum frequency selection resolution of 200Hz, as well as a minimum current ripple measurement resolution of a resolution of 15mA will be required to achieve this. For the derivation of these values, please see ??.

Requirement 7: Operate with variable load sizes between 10Ω and 20Ω

To meet this requirement, all components of the buck converter must be designed to handle the maximum output current of 1A that will occur with a 10Ω load at 10V. It will also be important that any current sensing is designed to operate within the range defined by these loads. Finally it is required that control systems are implemented to maintain requirements 3, & 6 as the load varies.
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

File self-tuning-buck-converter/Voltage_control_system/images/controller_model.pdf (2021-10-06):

0 | 0.05 | 0.1 | 0.15 | 0.2 | 0.25 | 0.3 | 0.35 | 0.4 | 0.45 | 0.5
| | | | | time [s]

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
Output Voltage

Buck converter step response to 3V target Discrete time PID control system

Controlled Output Voltage
Target Voltage

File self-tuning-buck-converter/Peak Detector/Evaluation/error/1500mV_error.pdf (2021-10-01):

1500mV Pk-Pk Input Ripple
Measured Output Error vs Switching Frequency

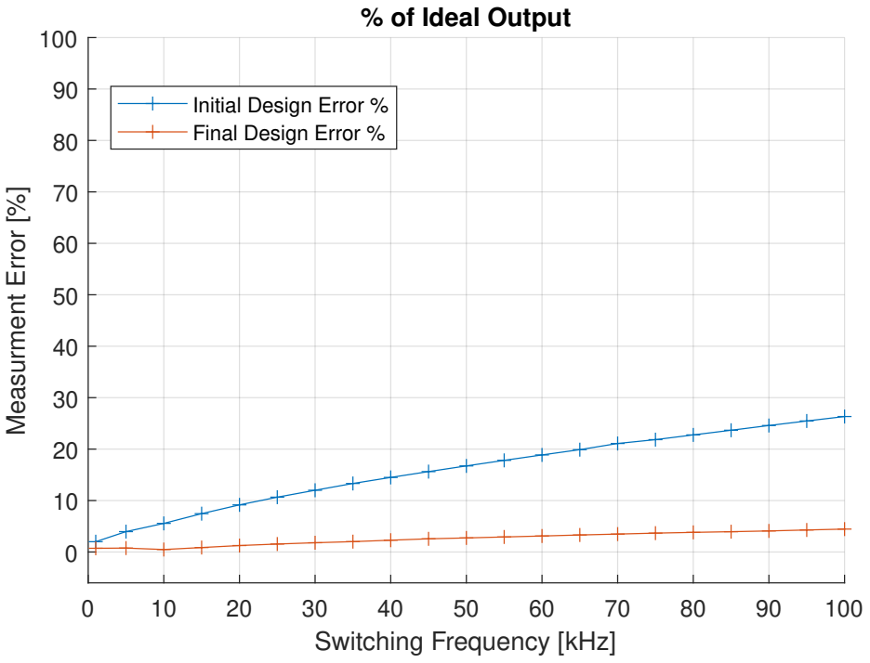
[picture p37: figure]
Switching Frequency [kHz]; Measurment Error [%]; % of Ideal Output; Initial Design Error % Final Design Error %

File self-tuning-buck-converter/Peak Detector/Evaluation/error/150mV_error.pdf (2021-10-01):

150mV Pk-Pk Input Ripple
Measured Output Error vs Switching Frequency

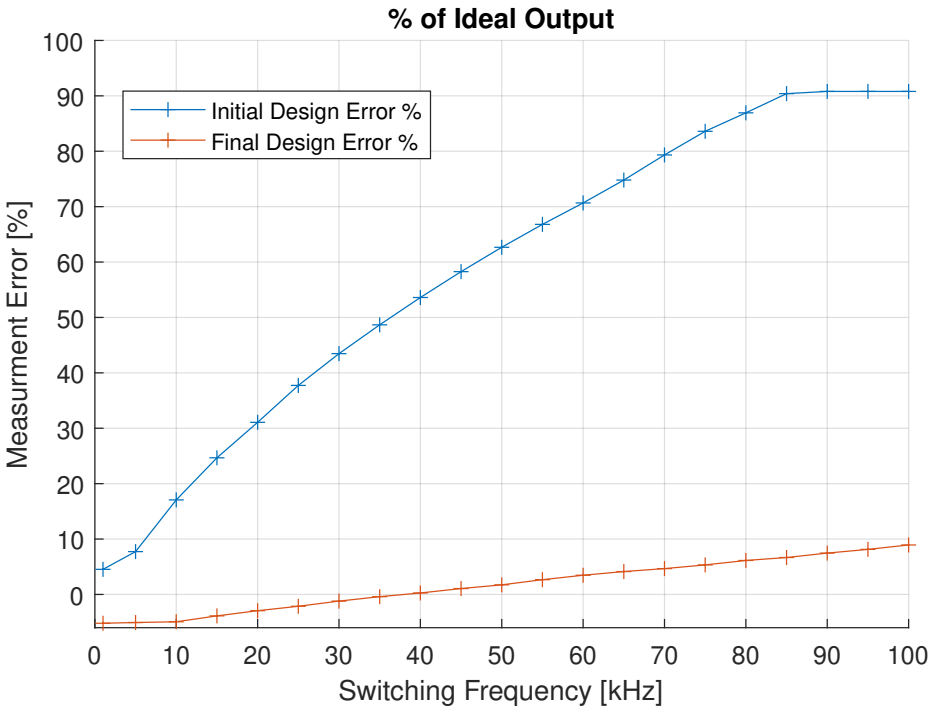
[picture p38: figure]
Switching Frequency [kHz]; Measurment Error [%]; % of Ideal Output; Initial Design Error % Final Design Error %

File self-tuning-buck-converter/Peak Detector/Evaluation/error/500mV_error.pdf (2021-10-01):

500mV Pk-Pk Input Ripple
Measured Output Error vs Switching Frequency

Switching Frequency [kHz]; Measurment Error [%]; % of Ideal Output; Initial Design Error % Final Design Error %

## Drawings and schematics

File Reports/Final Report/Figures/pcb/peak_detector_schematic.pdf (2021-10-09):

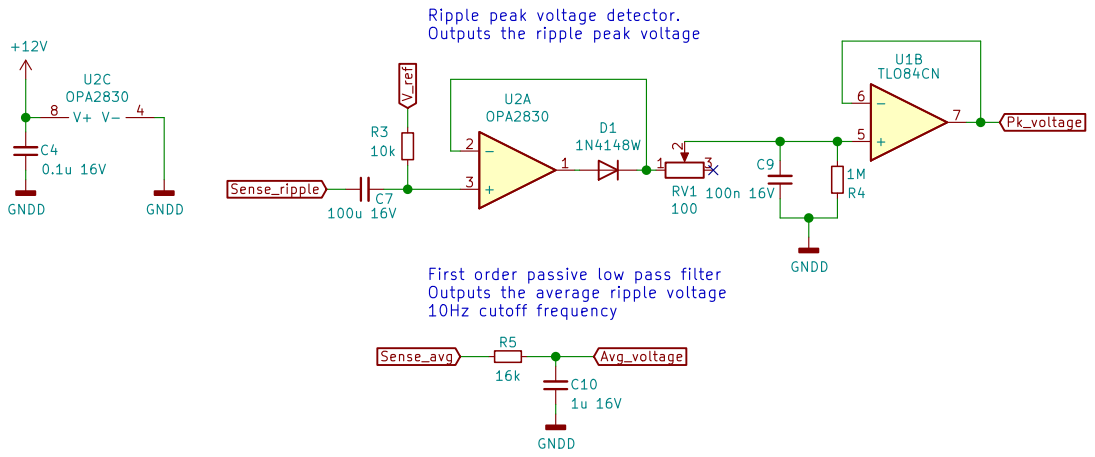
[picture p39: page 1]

Outputs the ripple peak voltage

First order passive low pass filter
Outputs the average ripple voltage
10Hz cutoff frequency

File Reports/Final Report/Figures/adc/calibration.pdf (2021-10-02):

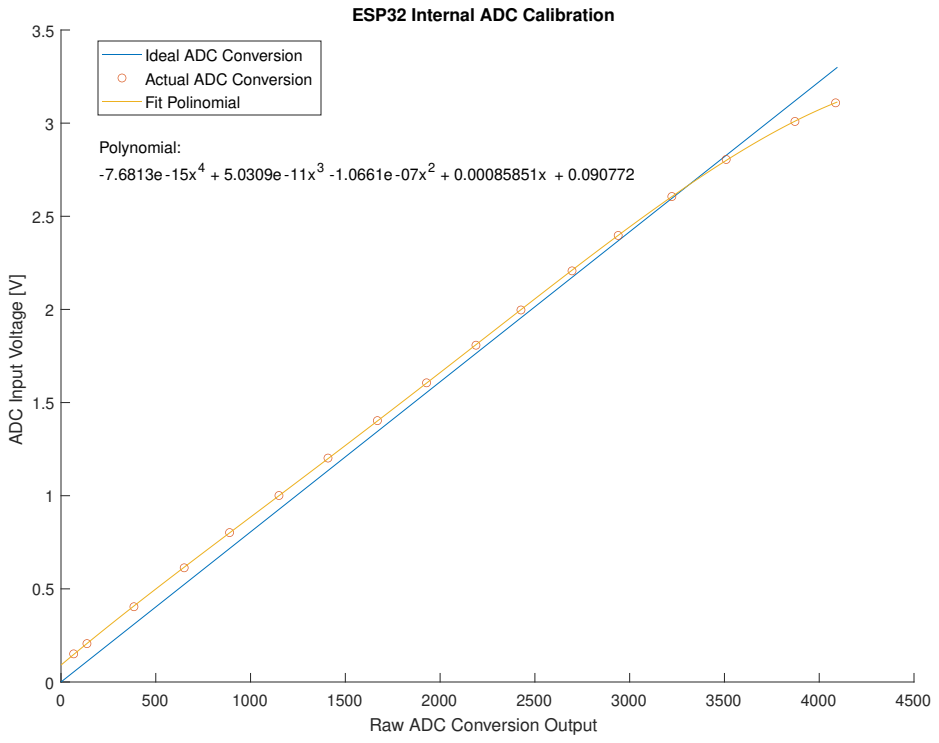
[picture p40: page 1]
Polynomial: -7.6813e-15x⁴ + 5.0309e-11x³ -1.0661e-07x² + 0.00085851x + 0.090772

ESP32 Internal ADC Calibration

Ideal ADC Conversion
Actual ADC Conversion
Fit Polinomial

ADC Input Voltage [V]

Raw ADC Conversion Output

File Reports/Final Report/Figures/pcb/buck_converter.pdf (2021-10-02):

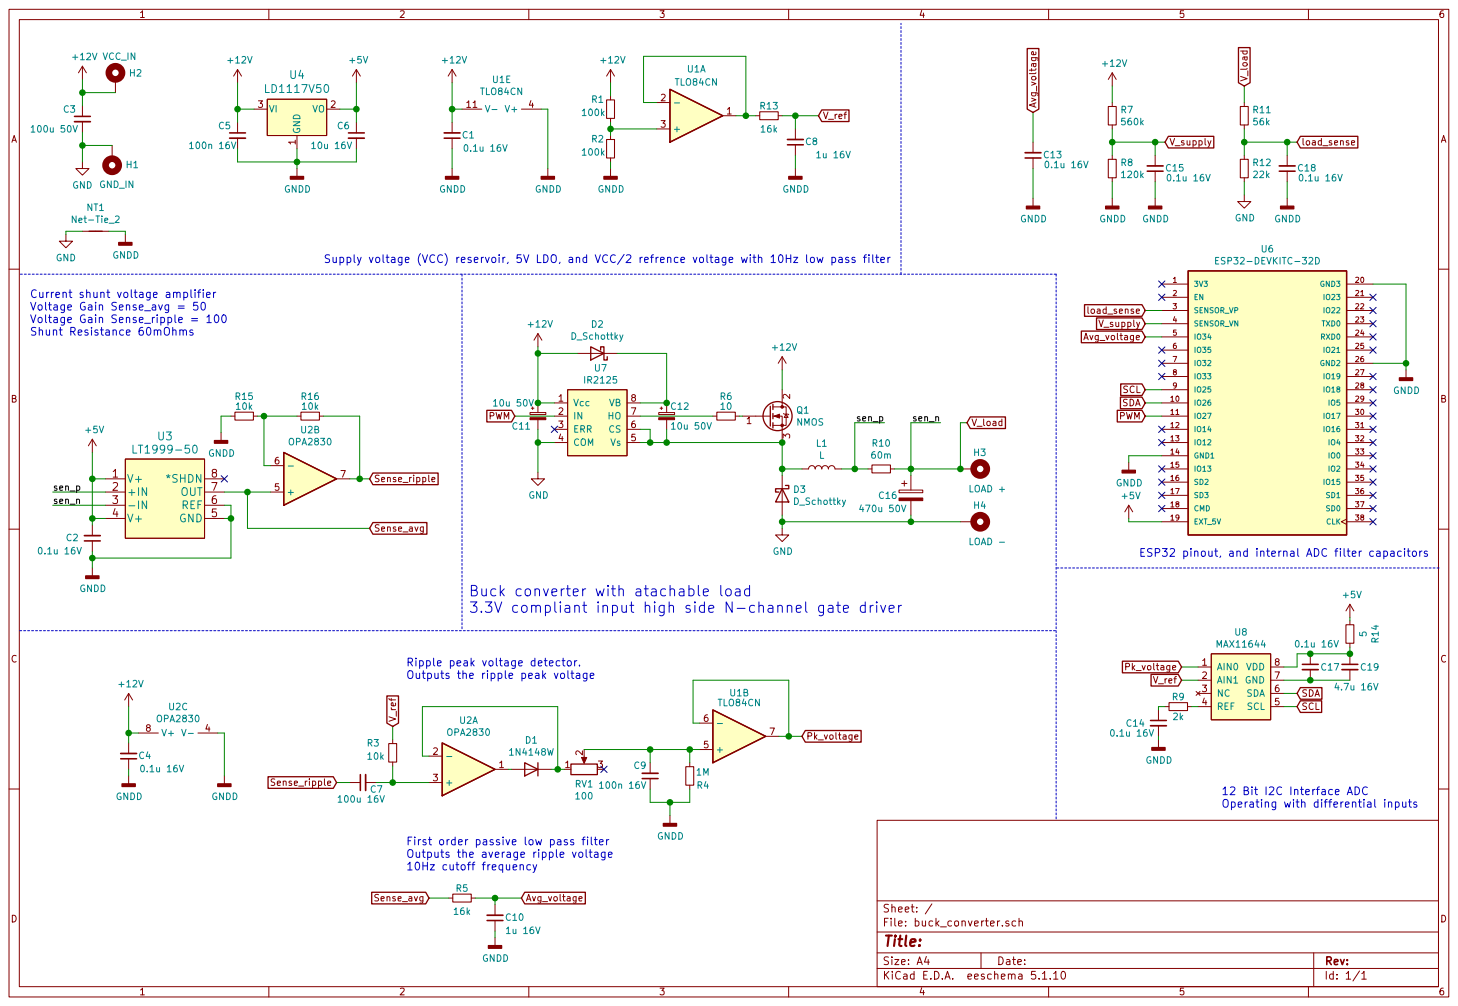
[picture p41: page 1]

Current shunt voltage amplifier
Voltage Gain Sense_avg = 50

ESP32 pinout, and internal ADC filter capacitors

3.3V compliant input high side N-channel gate driver

Outputs the ripple peak voltage

First order passive low pass filter
Outputs the average ripple voltage
10Hz cutoff frequency

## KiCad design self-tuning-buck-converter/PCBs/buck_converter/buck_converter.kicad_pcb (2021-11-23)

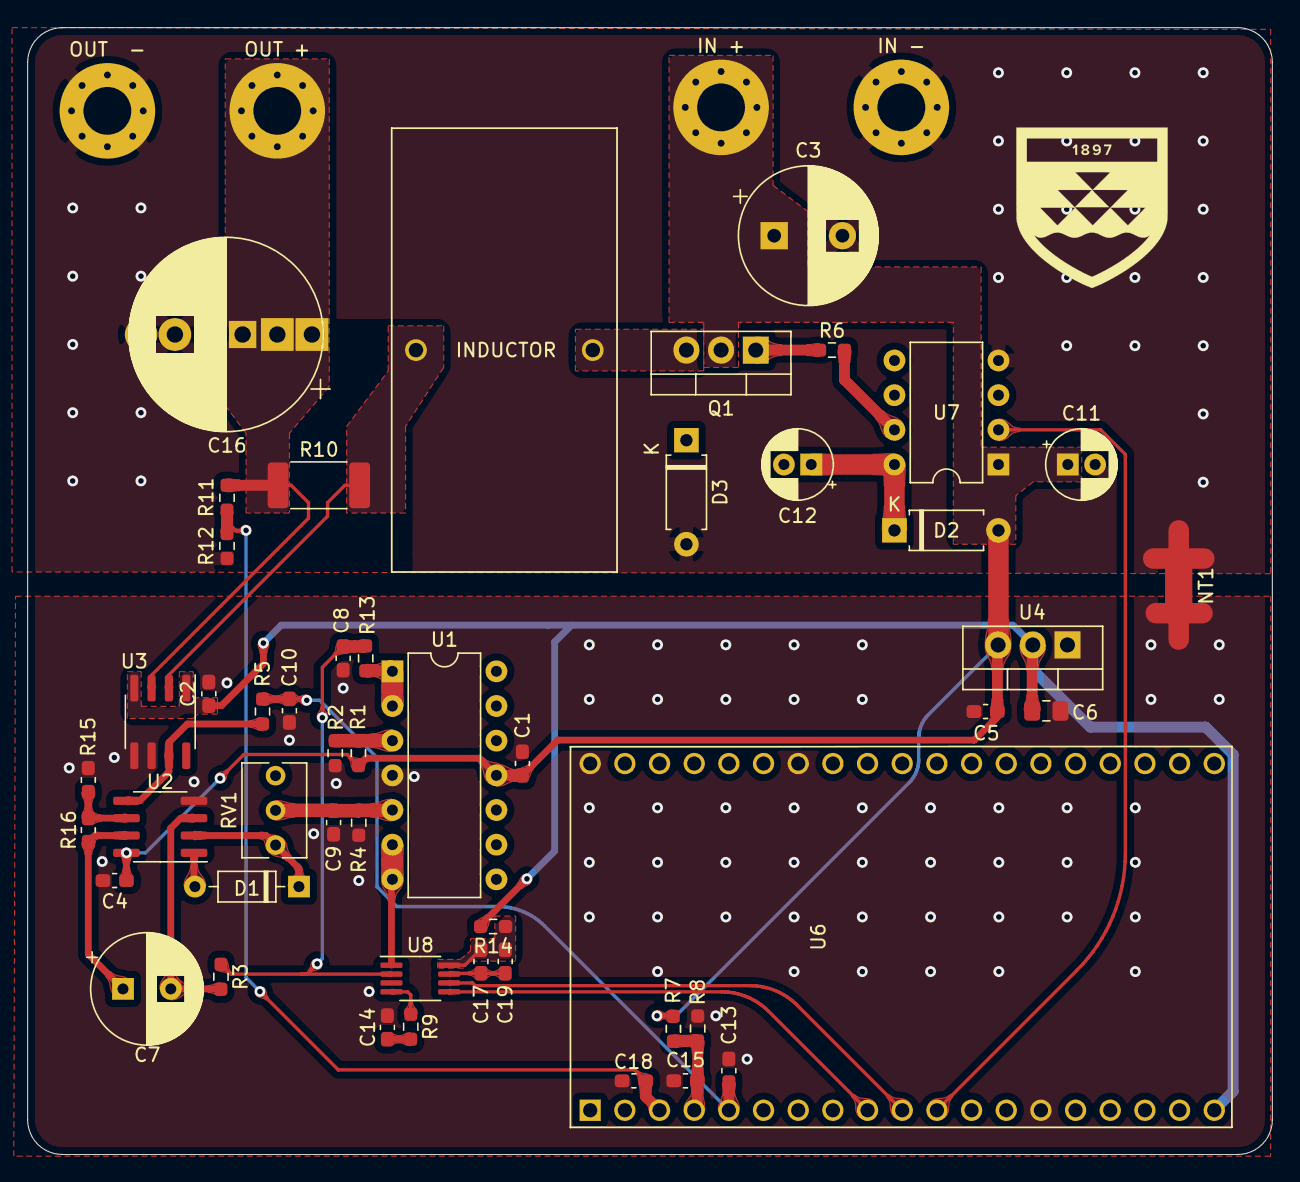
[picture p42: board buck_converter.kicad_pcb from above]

Board: 2 copper layers, 91.2 x 82.6 mm, 53 parts (0 on the bottom side), 31 nets.

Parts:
C1, C2, C4, C13, C14, C15, C17, C18: 0.1u 16V; C_0603_1608Metric_Pad1.08x0.95mm_HandSolder
C3: 100u 50V; CP_Radial_D10.0mm_P5.00mm
C5, C9: 100n 16V; C_0603_1608Metric_Pad1.08x0.95mm_HandSolder
C6: 10u 16V; C_0805_2012Metric_Pad1.18x1.45mm_HandSolder
C7: 100u 16V; CP_Radial_D8.0mm_P3.50mm
C8, C10: 1u 16V; C_0603_1608Metric_Pad1.08x0.95mm_HandSolder
C11, C12: 10u 50V; CP_Radial_D5.0mm_P2.00mm
C16: 470u 50V; multi_cap
C19: 4.7u 16V; C_0603_1608Metric_Pad1.08x0.95mm_HandSolder
D1: 1N4148W; D_DO-35_SOD27_P7.62mm_Horizontal
D2, D3: D_Schottky; D_A-405_P7.62mm_Horizontal
IN +: VCC_IN; MountingHole_3.5mm_Pad_Via
IN -: GND_IN; MountingHole_3.5mm_Pad_Via
INDUCTOR: L; IND_HCTI-150-5.0
NT1: Net-Tie_2; NetTie-2_SMD_Pad2.0mm
OUT  -: LOAD -; MountingHole_3.5mm_Pad_Via
OUT +: LOAD +; MountingHole_3.5mm_Pad_Via
Q1: NMOS; TO-220-3_Vertical
R1, R2: 100k; R_0603_1608Metric_Pad0.98x0.95mm_HandSolder
R3: 10k; R_0603_1608Metric_Pad0.98x0.95mm_HandSolder
R4: 1M; R_0603_1608Metric_Pad0.98x0.95mm_HandSolder
R5, R13: 16k; R_0603_1608Metric_Pad0.98x0.95mm_HandSolder
R6: 10; R_0603_1608Metric_Pad0.98x0.95mm_HandSolder
R7: 560k; R_0603_1608Metric_Pad0.98x0.95mm_HandSolder
R8: 120k; R_0603_1608Metric_Pad0.98x0.95mm_HandSolder
R9: 2k; R_0603_1608Metric_Pad0.98x0.95mm_HandSolder
R10: 60m; R_2512_6332Metric_Pad1.52x3.35mm_HandSolder
R11: 56k; R_0603_1608Metric_Pad0.98x0.95mm_HandSolder
R12: 22k; R_0603_1608Metric_Pad0.98x0.95mm_HandSolder
R14: 5; R_0603_1608Metric_Pad0.98x0.95mm_HandSolder
R15, R16: 10k; R_0603_1608Metric_Pad1.05x0.95mm_HandSolder
RV1: 100; Potentiometer_Bourns_3266Y_Vertical
U1: TLO84CN; DIP-14_W7.62mm
U2: OPA2830; SOIC-8_3.9x4.9mm_P1.27mm
U3: LT1999-50; SOIC-8_3.9x4.9mm_P1.27mm
U4: LD1117V50; TO-220-3_Vertical
U6: ESP32-DEVKITC-32D; MODULE_ESP32-DEVKITC-32D
U7: IR2125; DIP-8_W7.62mm
U8: MAX11644; MSOP-8_3x3mm_P0.65mm

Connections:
+5V: C2.2, C6.1, R14.2, U3.1, U3.4, U4.2, U6.19
+12V: C1.2, C3.1, C4.2, C5.1, C11.1, D2.2, IN +.1, Q1.2, R1.1, R7.1, U1.11, U2.8, U4.3, U7.1
/sen_p: INDUCTOR.2, R10.2, U3.2
Avg_voltage: C10.2, C13.2, R5.1, U6.5
GND: C3.2, C11.2, C16.2, D3.2, IN -.1, NT1.1, OUT -.1, R12.2, U7.4
GNDD: C1.1, C2.1, C4.1, C5.2, C6.2, C8.1, C9.1, C10.1, C13.1, C14.2, C15.1, C18.1, NT1.2, R2.2, R4.1, R8.2, R15.2, U1.4, U2.4, U3.5, U3.6, U4.1, U6.14, U6.20, U6.26
unnamed: C7.2, R3.2, U2.3
unnamed: C9.2, R4.2, RV1.2, U1.5
unnamed: C12.1, D2.1, U7.8
unnamed: C12.2, D3.1, INDUCTOR.1, Q1.3, U7.5, U7.6
unnamed: C14.1, R9.2
unnamed: C17.1, C19.1, R14.1, U8.8
unnamed: C17.2, C19.2, U8.7
unnamed: D1.1, RV1.1, U2.2
unnamed: D1.2, U2.1
unnamed: Q1.1, R6.1
unnamed: R1.2, R2.1, U1.3
unnamed: R6.2, U7.7
unnamed: R9.1, U8.4
unnamed: R13.2, U1.1, U1.2
unnamed: R15.1, R16.2, U2.6
PWM: U6.11, U7.2
Pk_voltage: U1.6, U1.7, U8.1
SCL: U6.9, U8.5
SDA: U6.10, U8.6
Sense_avg: R5.2, U2.5, U3.7
Sense_ripple: C7.1, R16.1, U2.7
V_load: C16.1, OUT +.1, R10.1, R11.1, U3.3
V_ref: C8.2, R3.1, R13.1, U8.2
V_supply: C15.2, R7.2, R8.1, U6.4
load_sense: C18.2, R11.2, R12.1, U6.3

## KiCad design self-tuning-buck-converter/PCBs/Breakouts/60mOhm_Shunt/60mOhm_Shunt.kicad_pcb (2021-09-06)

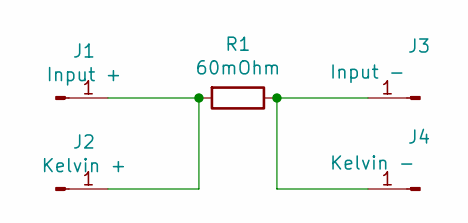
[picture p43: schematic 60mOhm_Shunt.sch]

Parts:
J1: Input +; PinHeader_1x01_P2.54mm_Vertical
J2: Kelvin +; PinHeader_1x01_P2.54mm_Vertical
J3: Input -; PinHeader_1x01_P2.54mm_Vertical
J4: Kelvin -; PinHeader_1x01_P2.54mm_Vertical
R1: 60mOhm; R_2512_6332Metric_Pad1.52x3.35mm_HandSolder

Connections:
unnamed: J1.1, J2.1, R1.2
unnamed: J3.1, J4.1, R1.1

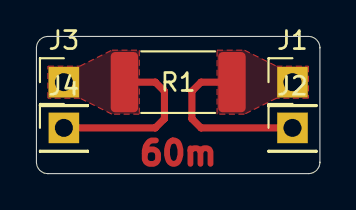
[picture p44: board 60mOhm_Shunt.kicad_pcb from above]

Board: 2 copper layers, 15.7 x 7.6 mm, 5 parts (0 on the bottom side), 2 nets.

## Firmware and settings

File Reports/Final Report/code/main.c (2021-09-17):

#include "buck_converter.h"

void app_main()
{

    init_buck();

    // Declare task handles
    TaskHandle_t VO_controller = NULL;

    QueueHandle_t target_voltage_queue;

    // initialise the queues
    target_voltage_queue = xQueueCreate(5, sizeof(float));

    // Create the output voltage control task
    xTaskCreatePinnedToCore(control_loop,                  // Voltage control loop function
                            "Vout_controller",             // Task name
                            2048,                          // Task stack size
                            (void *)&target_voltage_queue, // Function parameters
                            2,                             // Priority of the task (app_main has priority 1)
                            &VO_controller,                // Task handle
                            tskNO_AFFINITY);               // Core the task has been pinned to (No core selected)

    float input_voltage;
    char input_buffer[20] = {0};
    uint8_t buf_index = 0;

    while (true)
    {
        char input = fgetc(stdin);

        if (input != 0xFF)
        {
            input_buffer[buf_index++] = input; // read in the character, and increment the index
            fputc(input, stdout);              //echo the character back

            if ((input_buffer[buf_index - 1] == '\n'))
            {

                input_voltage = strtof(input_buffer, NULL);

                xQueueSend(target_voltage_queue, (void *)&input_voltage, (TickType_t)1);

                printf("\nInput Target Voltage: %f\n", strtof(input_buffer, NULL));
                buf_index = 0;
            }
        }

        vTaskDelay(1);

        // printf("task stack unused: %d\n\n", uxTaskGetStackHighWaterMark(VO_controller));
        // vTaskDelay(100);
    }
}

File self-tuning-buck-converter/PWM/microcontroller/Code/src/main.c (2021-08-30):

// Standard includes for math and print functions
#include <stdio.h>
#include <math.h>

// RTOS includes for error messages and task handeling
#include "freertos/FreeRTOS.h"
#include "freertos/task.h"
#include "esp_err.h"

// project includes
#include "pwm.h"

// #define DUTY_TEST
#define FREQUENCY_TEST

#define FREQUENCY_MIN 1000
#define FREQUENCY_MAX 100000

ledc_timer_config_t pwm_timer;     // Create the PWM timer struct
ledc_channel_config_t pwm_channel; // Create the PWM channel struct

void app_main() 
{
    /* 
     *  PWM setup
     */

    PWM_setup(&pwm_timer, &pwm_channel, 10000, 0.5f);

    esp_err_t status;

    while (true)
    {
        #ifdef DUTY_TEST
        for(int duty = 0; duty < 100; duty++){
            
            PWM_set_duty(&pwm_channel, duty/100.0f);
            vTaskDelay(1);
        }
        #endif

        #ifdef FREQUENCY_TEST

        for(int frequency = FREQUENCY_MIN; frequency <= FREQUENCY_MAX; frequency = frequency+10){

            status = PWM_set_frequency(&pwm_channel, &pwm_timer, frequency);

            printf("PWM frequency: %d  ->  %d\n", ledc_get_freq(pwm_channel.speed_mode, pwm_timer.timer_num), status);
            // vTaskDelay(1);
        }

        #endif
    }
}

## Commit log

2021-03-19 Project Proposal Complete
    [Gantt_Chart.xlsx]
2021-04-06 SPICE simulation of analog based PWM generation using an integrator to produce a triangle waveform.
2021-04-08 Completed SPICE simulation of an intergrator op amp based PWM generator #4
2021-04-08 Began the writeup of the anaogue PWM section of the design #4
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2021-04-20 Tested the PWM in the lab and looked at the output on a scope. The frequency and duty cycle are both variable and independant, and the frequency step size is a maximum of 200Hz in the 90kHz - 100kHz 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
2021-05-19 Found some sources for buck converter design, and began wiring the buck converter background section of the report
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2021-05-24 Prelim report complete
    [Prelim_Gantt_Chart .xlsx, Proposal_Gantt_Chart.xlsx]
2021-07-26 updated the precision rectifier with a 50MHz bandwidth opamp, also designed a peak detictor circuit that is capable of accuratly matching and sustaining peak voltages between 100mV and 10V
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2021-07-29 Created a bill of materials for all of the parts I want to test my current sensing desings
    [BOM.xlsx]
2021-08-17 created new BOM
    [bom_1.xlsx, bom_2.xlsx]
2021-08-17 created shunt resistor breakouts for breadboard
    [50mOhm_Shunt.kicad_pcb, 50mOhm_Shunt.sch, 60mOhm_Shunt.kicad_pcb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]
2021-08-17 update breakout PCB's for the 50mO and 60mO resistors. Ordered the missing parts
    [50mOhm_Shunt.kicad_pcb, 50mOhm_Shunt.sch, 60mOhm_Shunt.kicad_pcb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]
2021-08-18 Due to covid I will be unable to getthe correct gate driver for some period of time. To be able to continute I have used a BJT to step up and invert the 3.3V logic output to 10V, allowing me to drive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
    [main.c]
2021-08-19 updated breakout PCB's
    [50mOhm_Shunt.kicad_pcb, 60mOhm_Shunt.kicad_pcb]
2021-08-22 Created a bootsrapping circuit for driving the power mosfet with the esp32 micro. Wrote an API to interact the ADC hardware on the esp32, and then characterised the output of the ADC. It was found th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
    [ESP32_adc_calibration.ods]
2021-08-26 updated the adc calibration code
    [ESP32_adc_calibration.ods]
2021-08-26 refactor directories and added a state space model of the buck converter
    [50mOhm_Shunt.kicad_pcb, 50mOhm_Shunt.sch, 60mOhm_Shunt.kicad_pcb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]
2021-08-27 Designed a PI Controller for my state space model of my buck converter
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2021-08-30 Created a PID output voltage controller. This controller was designed with matlab, based on a state space model of the output voltage. This controller is implemented such that it can be run within it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
2021-09-06 began PCB design for entire buck converter
    [50mOhm_Shunt.kicad_pcb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]
2021-09-06 update gate driver schematic
    [buck_converter.sch]
2021-09-14 refactor headder libraries, corrected load voltage divider
2021-09-14 Updated the internal esp ADC library to facilitate reading from multiple pins. This new implementation requires the instantiation of an esp_adc struct, which will hold the adc channel, as well as the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
2021-09-14 updated the resistor values of the output load voltage divider. This will provide a more accurate measurment of the output load voltage
2021-09-14 updated the voltage control loop to use the new implementation of the ADC API
2021-09-15 Replaced the output load sensing voltage divider with more accurate resistors, then updated the code to use the new resistor values
    [main.c]
2021-09-17 Updated the PID controll loop to measure the input supply voltage. This allows for accurate control of the output voltage, when the supply voltage varies and changes.
2021-09-22 updated pcb schematic, added the current sense amplifier, ripple averager (low pass filter), and ripple peak detector
    [buck_converter.sch]
2021-09-22 updated schematic with bypass capacitors, and added small filter caps to the ESP32's ADC input pins as recomended by the the datasheet
    [buck_converter.sch]
2021-09-23 updated the design of the peak detectror such that is imposes thepeaks on VCC/2. This voltage will vary as VCC shifts, but the differential ADC can be used to take accurate peak readings regardless, 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
    [buck_converter.sch]
2021-09-23 Finalised PCM and selected component footprints
    [buck_converter.kicad_pcb, buck_converter.sch]
2021-09-25 Updated schematic with edits found from building it in the lab
    [buck_converter.kicad_pcb, buck_converter.sch]
2021-09-26 Completed the data collection on the performance of the new peak detection circuit
    [Peak Detector Evaluation.xlsx]
2021-09-27 updated peak detector error plots
    [Peak Detector Evaluation.xlsx]
2021-09-27 PEak detection evaluation
    [buck_converter.sch]
2021-09-27 PWM evaluation plots
    [pwm_duty.csv, pwm_frequency.csv]
2021-09-27 begin and almost complete the PCB design of the buck converter:
    [buck_converter.kicad_pcb, buck_converter.sch]
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2021-09-29 completed the PCB design
    [buck_converter.kicad_pcb, buck_converter.sch]
2021-09-29 added via stitching to the board
    [buck_converter.kicad_pcb]
2021-09-29 many images added for the final report... also tidied up the schematic for input into the report
    [buck_converter.sch]
2021-09-30 moved the evaluation data for the peak detector into matlab. generated plots of all the data
    [Peak Detector Evaluation.csv]
2021-09-30 PWM Error plotting changed to a percentage of the target value
2021-09-30 converted svg images to pdf's for inclusion in the report
    [ESP32_adc_calibration.csv, ESP32_adc_calibration.ods]
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2021-10-02 make even more images omg... How will I fit all these images
    [test.sch]
2021-10-03 update appendix structure, included all code with the correct listings settings, and finished inputting the peak detector error tables
    [buck_coverter.c]
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2021-11-23 update PCB, and create the iBOM
    [Prelim_Gantt_Chart .xlsx, Proposal_Gantt_Chart.xlsx, buck_converter.kicad_pcb]
2021-11-23 generate gerbers
    [buck_converter-B_Cu.gbr, buck_converter-B_Mask.gbr, buck_converter-B_SilkS.gbr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]
2021-11-23 update docs
    [Prelim_Gantt_Chart .xlsx, Proposal_Gantt_Chart.xlsx]
2021-11-23 removed un-necessay schematics
    [buck_converter-B_Cu.gbr, buck_converter-B_Mask.gbr, buck_converter-B_SilkS.gbr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]
2022-04-11 update to kicad 6
    [buck_converter.kicad_sch]
